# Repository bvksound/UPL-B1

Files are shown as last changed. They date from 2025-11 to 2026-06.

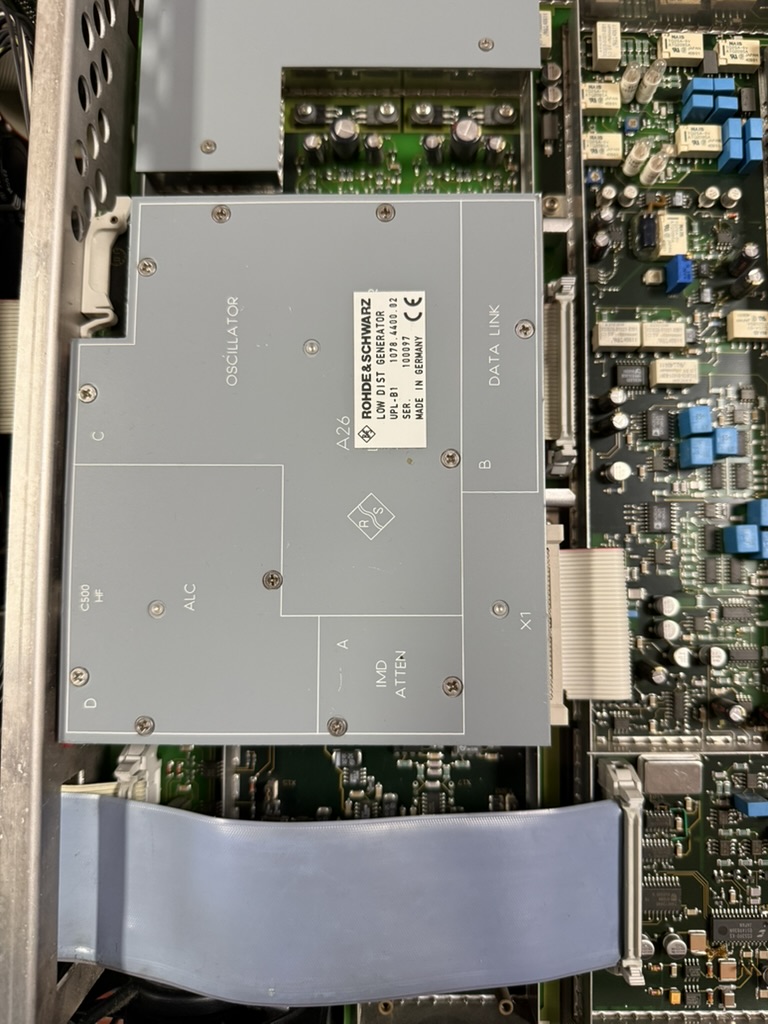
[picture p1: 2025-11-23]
Photo's/27672058-2E6B-4C86-B138-4FB6E2C6E2C1_1_105_c.jpeg

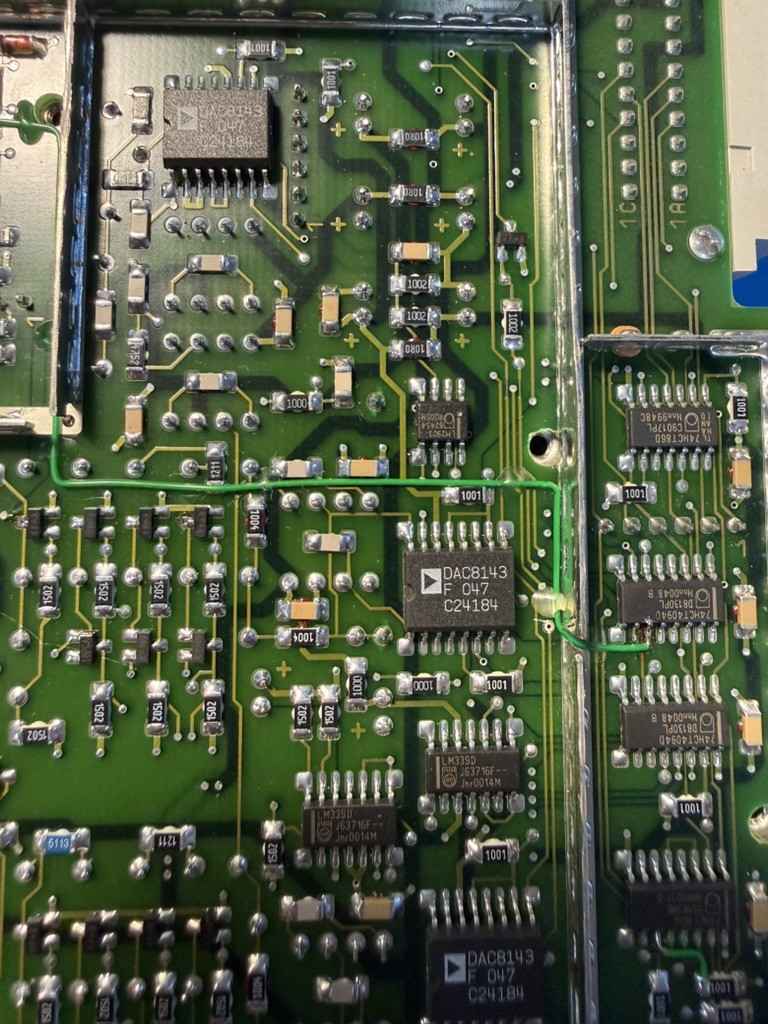
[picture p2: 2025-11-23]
Photo's/FC6CC313-4F3F-445F-819C-2A2638F99B96_1_105_c.jpeg

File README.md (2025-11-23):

UPL-B1 Low Distortion Generator — Functional Description (Sheets 1–5)

The UPL-B1 is a digitally controlled, ultra-low-distortion sine-wave generator. It operates by forming a precisely tuned analog feedback loop based on two integrators, a loop inverter, a fine-tuning DAC, and an ultra-slow automatic level control system. The resulting sine wave is then routed through a calibrated output attenuator to the LOW DIST output connector.

The block diagram in Sheet 1 shows how the system is organized.
What follows is the working description of each functional block in the signal path.

⸻

1. Digital Control Interface (Data Link)

(Located in sheet 1)

At the heart of the module’s control architecture is the Data Link, which acts as the communication interface between the UPL main processor and all analog functions of the generator. A chain of serial-in/parallel-out registers receives configuration words via the UPL’s internal bus. Once a word is clocked in and latched, each bit becomes a control signal for:
	•	selecting RC networks inside the frequency-defining integrators,
	•	programming the 12-bit DAC used for fine frequency tuning,
	•	configuring the ALC’s track-and-hold behavior,
	•	setting the output level via the IMD attenuator.

In this way, the Data Link provides complete, deterministic configuration of the low-distortion generator through a simple serial interface.

⸻

2. First Loop Element: Integrator 2

(Located in sheet 4)

The oscillator loop begins with Integrator 2, which receives the feedback signal from the loop inverter. This block is a precision analog integrator with a set of relay- and switch-selectable RC networks. These RC combinations determine the coarse frequency range of the oscillator.

Because the transfer function of an integrator introduces a –90° phase shift, this element contributes the first quadrature shift in the loop. The output of this block is labelled SIN. It serves as both a phase-shifted signal for the next integrator and as a key reference for amplitude monitoring in the ALC.

⸻

3. Second Loop Element: Integrator 1, and the Loop Inverter

(Both located in sheet 3)

Integrator 1 — second 90° phase shift

The SIN signal from Integrator 2 is fed into Integrator 1, which is structurally similar—another precision op-amp stage with switchable RC networks.
This second integrator produces the COS signal, shifted by another –90°.
Together, the two integrators establish the total –180° shift required by the oscillator’s feedback loop.

Fine Frequency Tuning (DAC + Summing Amplifier)

A portion of the COS signal is routed into a 12-bit DAC system, whose output feeds a summing amplifier. This mechanism provides continuous fine frequency adjustment within each coarse RC range.
The UPL’s firmware writes a digital tuning word via the Data Link, and the DAC modifies the loop dynamics subtly to achieve precise output frequency control.

Loop Inverter — completes the oscillation path

The Loop Inverter receives signals from the fine-tuning circuit and the integrator chain and produces the required additional –180° phase inversion, closing the total loop phase at 360° (0° net).
The loop inverter also establishes the oscillator’s effective feedback gain, which is later stabilized by the amplitude control system.

The output of the loop inverter is fed back to Integrator 2, completing the analog oscillator core.

⸻

4. Amplitude Regulation: The Automatic Level Control (ALC)

(Located in sheet 5)

A precision sine-wave oscillator will naturally drift or saturate unless its amplitude is regulated. In the UPL-B1, this regulation is handled by the Automatic Level Control (ALC) system.

Amplitude Sampling and Track-and-Hold

A portion of the SIN waveform is extracted and fed into a track-and-hold detector.
This allows the ALC to operate cleanly over the full frequency range of the generator—including very low frequencies—where a conventional detector would otherwise create distortion or instability.

Precision Detection and Error Generation

The sampled waveform is rectified and converted into a DC level proportional to its amplitude.
A summing amplifier compares this value to an internally established reference representing the desired output level.

Slow, Low-Distortion Control Loop

The resulting error signal passes through carefully designed low-frequency filters.
These filters ensure that the ALC’s response is extremely slow—far outside the audio band—so that no gain modulation occurs within the audible range. This is critical for achieving the exceptionally low distortion performance of the UPL-B1.

VCA Gain Element

The filtered control voltage drives a voltage-controlled amplifier (VCA) in the main signal path.
When the amplitude is too low, the VCA’s gain increases; when too high, it decreases.
When equilibrium is reached, the loop gain of the oscillator is exactly unity, resulting in a stable, clean sine of precisely controlled amplitude.

The regulated sine now moves to the final output stage.

⸻

5. Output Level Setting: IMD Attenuator

(Located in sheet 2)

The final block is the IMD Attenuator, responsible for delivering calibrated output levels to the LOW DIST connector.
The attenuator uses relay-selected resistor networks combined with precision buffer amplification. Control bits from the Data Link determine the selected attenuation step.

Unlike the ALC-governed gain element, the IMD attenuator applies fixed, accurate attenuation values that do not interact with the oscillator’s internal amplitude regulation. This ensures:
	•	repeatable, calibration-grade output levels,
	•	reliable IMD and THD measurement conditions,
	•	and isolation of the internal oscillator loop from load-dependent variations.

The output of this attenuator is the module’s LOW DIST signal.

⸻

Complete Signal Flow (at a glance)
	1.	UPL processor configures the module via the Data Link (Sheet 1).
	2.	The signal enters Integrator 2 (Sheet 4) which adds the first –90° phase shift.
	3.	It then enters Integrator 1 (Sheet 3) for another –90° shift, producing COS.
	4.	The signal passes through the fine-tuning DAC and the Loop Inverter (Sheet 3), closing the loop.
	5.	The resulting oscillation is amplitude-stabilized by the ALC system (Sheet 5).
	6.	The regulated sine enters the IMD Attenuator (Sheet 2).
	7.	The final output appears as LOW DIST, ready for measurement applications.

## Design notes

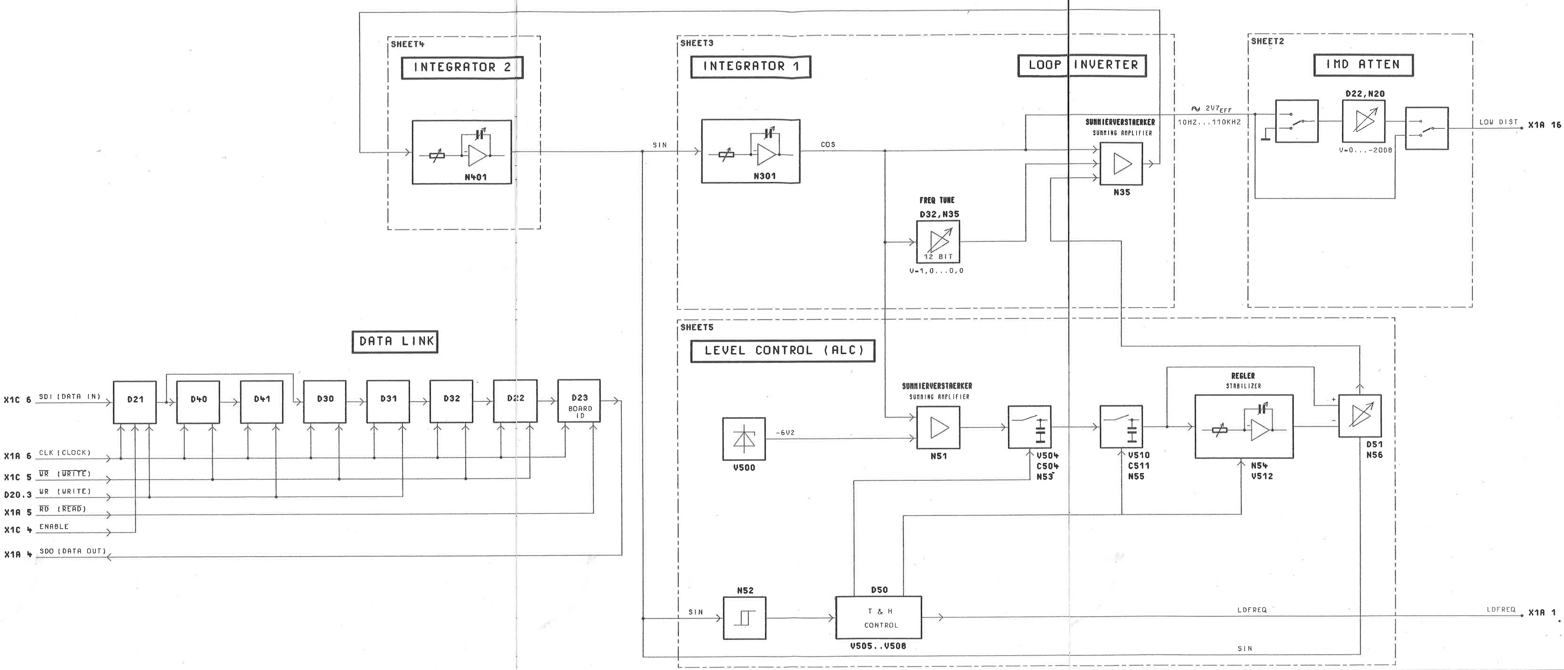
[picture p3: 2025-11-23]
Documentation/Block Schematic Cropped.png

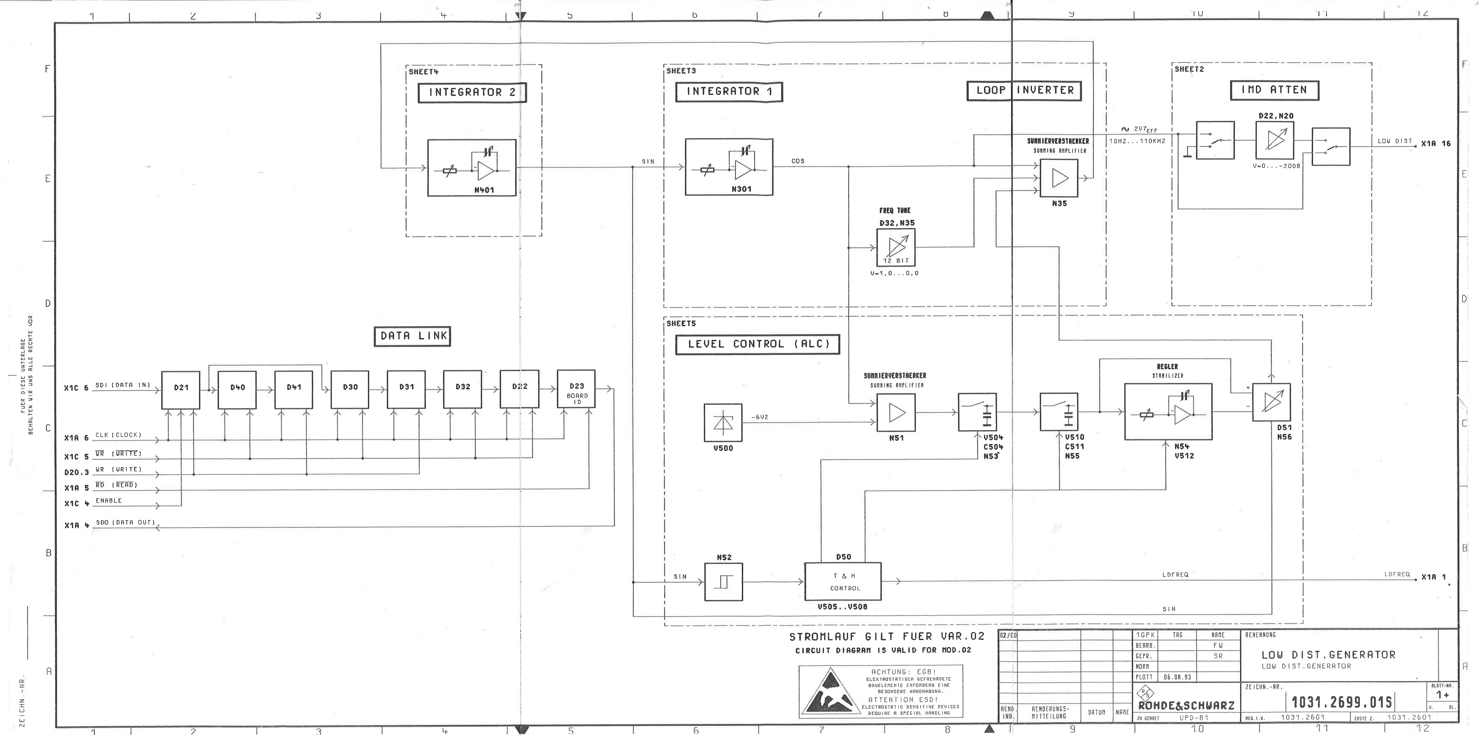
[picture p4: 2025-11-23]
Documentation/Block Schematic.png

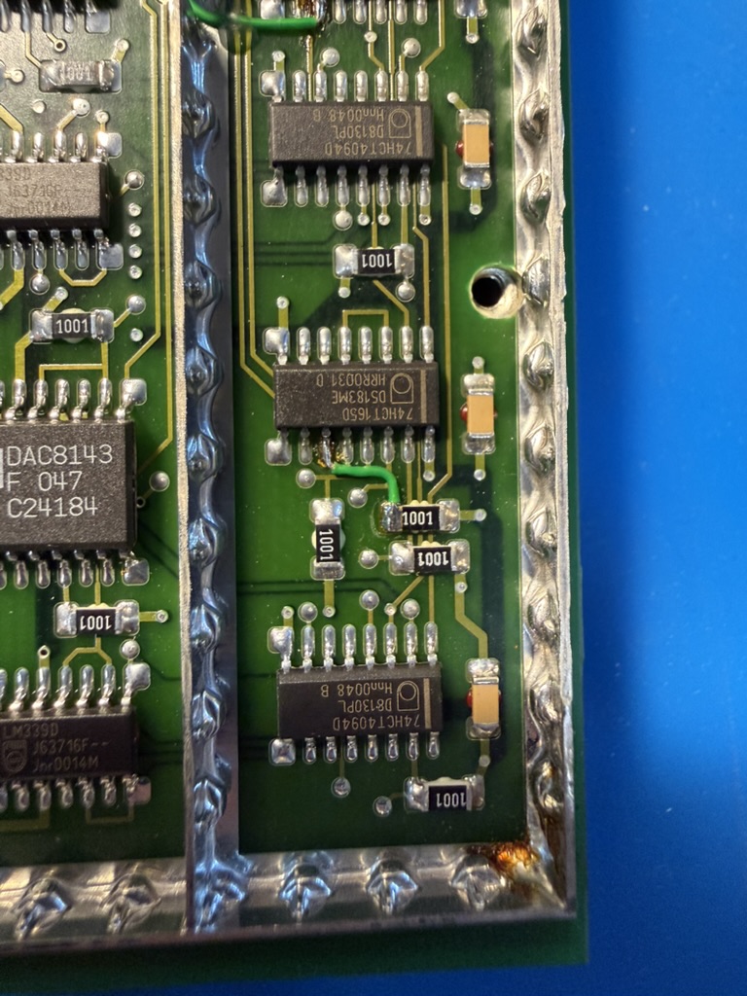
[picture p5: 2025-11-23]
Photo's/623FA692-C8BD-4882-8F0A-5FB2C9D7B14C_1_105_c.jpeg

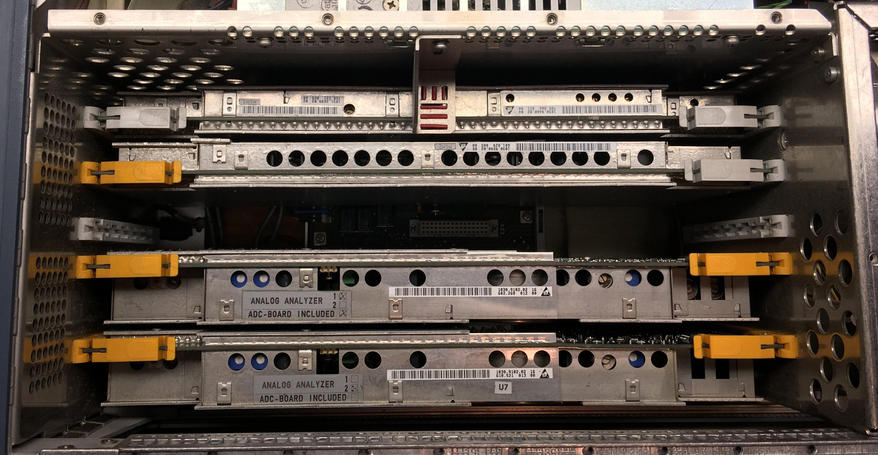
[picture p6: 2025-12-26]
Photo's/UPD_Option UPL-B1 Slot.jpg

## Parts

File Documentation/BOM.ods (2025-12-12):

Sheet: out
 | Value | Footprint | TempCo | Voltage | Manufacturer | Order No | Datasheet | Raw designation from R&S BOM | Still availabe from Distributors | Distributor | Partno | Comment on availability | RoHS | Substitute?
C500 | 1 to 14 pF > 6 turns; |  |  |  |  |  | https://www.ebay.at/itm/284966498300 | CTY 13PF TAUCHTR.RD7X12 CT 0092.4266.00|TEKELEC AT 5401 | TBD
V3 | 16 AK BC850B N 45V 200MA AK 0007.7969.00/PHILIPS-CO BC850B |  |  |  | PHILIPS |  |  | 16 AK BC850B N 45V 200MA AK 0007.7969.00/PHILIPS-CO BC850B | TBD |  |  | Found some on ebay
V510 | 2N4092 | TO-18-3 |  | 40V | INTERSIL | 2N4092 | https://www.mouser.de/datasheet/3/1206/1/jfet-2n4091-2n4092-2n4093-interfet.pdf | AM 2N4092 N-D 40V JFET AM 0010.8791.00/INTERSIL 2N4092 | Yes | Mouser | 494-2N4092 | 35€ p/piece?!
V504 | 2N4856A | TO-18-3 |  |  | Motorola | 2N4856A | https://www.alldatasheet.com/datasheet-pdf/pdf/78471/MOTOROLA/2N4856A.html | AM 2N4856A N-D 40V JFET 0262. 4082.00 |MOTOROLA | Not really |  |  | 60€ p/piece. Min 100
V512 | 2N4856A | TO-18-3 |  |  | Motorola | 2N4856A | https://www.alldatasheet.com/datasheet-pdf/pdf/78471/MOTOROLA/2N4856A.html |  | Not really |  |  | 60€ p/piece. Min 100
V308 | 2N5432 | TO-206AC |  |  | SILICONIX | 2N5432 | https://mm.digikey.com/Volume0/opasdata/d220001/medias/docus/2360/2N5432%20thru%202N5434.pdf | AM 2N5432 N-D 25V JFET AM 0296.8700.00|SILICONIX 2N5432 | No
V309 | 2N5432 | TO-206AC |  |  | SILICONIX | 2N5432 | https://mm.digikey.com/Volume0/opasdata/d220001/medias/docus/2360/2N5432%20thru%202N5434.pdf | AM 2N5432 N-D 25V JFET AM 0296.8700.00/SILICONIX 2N5432 | No
V408 | 2N5432 | TO-206AC |  |  | SILICONIX | 2N5432 | https://mm.digikey.com/Volume0/opasdata/d220001/medias/docus/2360/2N5432%20thru%202N5434.pdf | AM 2N5432 N-D 25V JFET AM 0296.8700.00;SILICONIX 2N5432 | No
V409 | 2N5432 | TO-206AC |  |  | SILICONIX | 2N5432 | https://mm.digikey.com/Volume0/opasdata/d220001/medias/docus/2360/2N5432%20thru%202N5434.pdf | AM 2N5432 N-D 25V JFET AM 0296.8700.00;}SILICONIX 2N5432 | No
V410 | 2N5432 | TO-206AC |  |  | SILICONIX | 2N5432 | https://mm.digikey.com/Volume0/opasdata/d220001/medias/docus/2360/2N5432%20thru%202N5434.pdf | AM 2N5432 N-D 25V JFET AM 0296.8700.00/SILICONIX 2N5432 | No
D50 | 74HC132 | SOIC14 |  |  | PHILIPS | 74HC132D | https://assets.nexperia.com/documents/data-sheet/74HC_HCT132.pdf | BL PC74HC132T 4XSCHMITT T |BL 0520.7811.O00}PHILIPS SE 74HC132D | Yes |  |  |  | Yes
D23 | 74HCT165D | SOIC16 |  |  | PHILIPS | 74HCT165D | https://assets.nexperia.com/documents/data-sheet/74HC_HCT165.pdf | BL PC74HCT165T 8B SHREG BL 0007.5408.O00/PHILIPS SE 74HCT165D | Yes |  |  |  | Yes
D21 | 74HCT4094T | SOIC16 |  |  | PHILIPS | PC74HCT4094T | https://octopart.com/de/datasheet/nxp-semiconductors/PC74HCT4094T | BL PC74HCT4094T 8ST.SHREG |BL O0007.6885.00/PHILIPS-CO PC74HCT4094T | Yes | Mouser | 595-CD74HCT4094EE4 |  | Yes
D31 | 74HCT4094T | SOIC16 |  |  | PHILIPS | PC74HCT4094T | https://octopart.com/de/datasheet/nxp-semiconductors/PC74HCT4094T | BL PC74HCT4094T 8ST.SHREG {BL 0007.6885.00;)PHILIPS-CO PC74HCT4094T | Yes | Mouser | 595-CD74HCT4094EE4 |  | Yes
D41 | 74HCT4094T | SOIC16 |  |  | PHILIPS | PC74HCT4094T | https://octopart.com/de/datasheet/nxp-semiconductors/PC74HCT4094T | BL PC74HCT4094T 8ST.SHREG |BL 0007.6885.00|}PHILIPS-CO PC74HCT4094T | Yes | Mouser | 595-CD74HCT4094EE4 |  | Yes
D20 | 74HCT4094T | SOIC16 |  |  | PHILIPS | PC74HCT86T | https://octopart.com/de/datasheet/nxp-semiconductors/PC74HCT86T | BL PC74HCT86T 4X2IN.EXOR |BL 0007.6291.O00;PHILIPS SE 74HCT86D | Yes | Mouser | 621-74HCT86T14-13 |  | Yes
V20 | BAS32 | SOT23 |  | 75V | PHILIPS | BAS32 | https://assets.nexperia.com/documents/data-sheet/BAS32L.pdf | AD BAS32 75V UDI |AD 0006.7288.00]PHILIPS-CO BAS32 | Yes | Reichelt | BAS32L,115 |  | Yes
V537 | BAS32 | SOT23 |  | 75V | PHILIPS | BAS32 | https://assets.nexperia.com/documents/data-sheet/BAS32L.pdf | AD BAS32 75V UDI |AD 0006.7288.00|PHILIPS-CO BAS32 | Yes | Reichelt | BAS32L,115 |  | Yes
V311 | BAV70 | SOT23 |  |  | PHILIPS | BAV70 | https://assets.nexperia.com/documents/data-sheet/BAV70.pdf | AD BAV70 7OV DUO UDI 0007 .9278.00}PHILIPS-CO BAV70 | Yes | Reichelt | BAV 70 NXP |  | Yes
V313 | BAV70 | SOT23 |  |  | PHILIPS | BAV70 | https://assets.nexperia.com/documents/data-sheet/BAV70.pdf | AD BAV70 7OV DUO UDI 0007 .9278.00/}PHILIPS-CO BAV70 | Yes | Reichelt | BAV 70 NXP |  | Yes
V511 | BAV70 | SOT23 |  |  | PHILIPS | BAV70 | https://assets.nexperia.com/documents/data-sheet/BAV70.pdf | AD BAV70 7OV DUO UDI 0007 .9278.00|PHILIPS-CO BAV70 | Yes | Reichelt | BAV 70 NXP |  | Yes
V514 | BAV99 | SOT23 |  |  | PHILIPS | BAV99 | https://assets.nexperia.com/documents/data-sheet/BAV99.pdf | AD BAV99 70V DUO UDI JAD 0911.0092.00]PHILIPS-CO BAV9S | Yes | Reichelt | BAV99 |  | Yes
V314 | BAV99 | SOT23 |  |  | PHILIPS | BAV99 | https://assets.nexperia.com/documents/data-sheet/BAV99.pdf | AD BAV99 7OV DUO UDI |AD 0911.0092.00|/PHILIPS-CO BAVg9 | Yes | Reichelt | BAV99 |  | Yes
V513 | BAV99 | SOT23 |  |  | PHILIPS | BAV99 | https://assets.nexperia.com/documents/data-sheet/BAV99.pdf | AD BAV99 7OV DUO UDI |AD 0911.0092.00}/PHILIPS-CO BAVS9 | Yes | Reichelt | BAV99 |  | Yes
V515 | BAV99 | SOT23 |  |  | PHILIPS | BAV99 | https://assets.nexperia.com/documents/data-sheet/BAV99.pdf | AD BAV99 7OV DUO UDI jAD 0911.0092.00]PHILIPS-CO BAVS9 | Yes | Reichelt | BAV99 |  | Yes
V21 | BC850B | SOT23 |  | 45V | PHILIPS-CO | BC850B | https://assets.nexperia.com/documents/data-sheet/BC850C.pdf | AK BC850B N 45V 200MA AK 0007.7969.00|PHILIPS-CO BC850B | Yes | Reichelt | BC 850B SMD |  | Yes
V300 | BC850B | SOT23 |  | 45V | PHILIPS-CO | BC850B | https://assets.nexperia.com/documents/data-sheet/BC850C.pdf | AK BC860B P 45V 200MA AK 0007.7975.00 |MOTOROLA BCB6OB LT1 | Yes | Reichelt | BC 850B SMD |  | Yes
V315 | BC850B | SOT23 |  | 45V | PHILIPS-CO | BC850B | https://assets.nexperia.com/documents/data-sheet/BC850C.pdf | AK BC860B P 45V 200MA AK 0007 .7975.00;MOTOROLA BCB860B LT1 | Yes | Reichelt | BC 850B SMD |  | Yes
V400 | BC850B | SOT23 |  | 45V | PHILIPS-CO | BC850B | https://assets.nexperia.com/documents/data-sheet/BC850C.pdf | AK BC860B P 45V 200MA AK 0007 .7975.00}MOTOROLA BC860B LT1 | Yes | Reichelt | BC 850B SMD |  | Yes
V505 | BC850B | SOT23 |  | 45V | PHILIPS-CO | BC850B | https://assets.nexperia.com/documents/data-sheet/BC850C.pdf | AK BC850B N 45V 200MA AK 0007.7969.00/PHILIPS-CO BC850B | Yes | Reichelt | BC 850B SMD |  | Yes
V506 | BC850B | SOT23 |  | 45V | PHILIPS-CO | BC850B | https://assets.nexperia.com/documents/data-sheet/BC850C.pdf | AK BC8S0B N 45V 200MA AK 0007 .7969.00|PHILIPS-CO BC850B | Yes | Reichelt | BC 850B SMD |  | Yes
V507 | BC850B | SOT23 |  | 45V | PHILIPS-CO | BC850B | https://assets.nexperia.com/documents/data-sheet/BC850C.pdf | AK BC860B P 45V 200MA AK 0007.7975.00/MOTOROLA BCB860B LT1 | Yes | Reichelt | BC 850B SMD |  | Yes
V508 | BC850B | SOT23 |  | 45V | PHILIPS-CO | BC850B | https://assets.nexperia.com/documents/data-sheet/BC850C.pdf | AK BC860B P 45V 200MA AK 0007.7975.00|}MOTOROLA BC860B LT1 | Yes | Reichelt | BC 850B SMD |  | Yes
V306 | BSR56 | SOT23 |  |  | PHILIPS | BSR56 | https://www.nxp.com/docs/en/data-sheet/BSR56_57_58.pdf | AM BSR56 N-D 40V JFET |AM 0007.3111.00}PHILIPS-CO BSR56 | No
V307 | BSR56 | SOT23 |  |  | PHILIPS | BSR56 | https://www.nxp.com/docs/en/data-sheet/BSR56_57_58.pdf | AM BSR56 N-D 40V JFET |AM 0007.3111.00}PHILIPS-CO BSR56 | No
V406 | BSR56 | SOT23 |  |  | PHILIPS | BSR56 | https://www.nxp.com/docs/en/data-sheet/BSR56_57_58.pdf | AM BSR56 N-D 40V JFET |AM 0007.3111.00/PHILIPS-CO BSR56 | No
V407 | BSR56 | SOT23 |  |  | PHILIPS | BSR56 | https://www.nxp.com/docs/en/data-sheet/BSR56_57_58.pdf | AM BSR56 N-D 40V JFET |AM 0007.3111.00/PHILIPS-CO BSR56 | No
V502 | BSR56 | SOT23 |  |  | PHILIPS | BSR56 | https://www.nxp.com/docs/en/data-sheet/BSR56_57_58.pdf | AM BSR56 N-D 40V JFET |AM 0007.3111.00]PHILIPS-CO BSR56 | No
V503 | BSR56 | SOT23 |  |  | PHILIPS | BSR56 | https://www.nxp.com/docs/en/data-sheet/BSR56_57_58.pdf | AM BSR56 N-D 40V JFET |}|AM 0007.3111.00|/PHILIPS-CO BSR56 | No
V516 | BZX55/B7V5 | DO-35 |  |  | PHILIPS | BZX55/B7V5 | https://www.vishay.com/docs/85604/bzx55.pdf | AE BZX55/B7V5 o,5W ZDI AE 0349.3041.00|PHILIPS-CO BZX79/B7V5 | Yes | Mouser | 78-BZX55B7V5 |  | Yes
C306 | CC 100nF+/-10% | 1206 | X7R | 50V | VITRAMON | VJ1206 Y104 K XAT | https://www.vishay.com/docs/45198/vjomd.pdf |  | TBD
C307 | CC 100nF+/-10% | 1206 | X7R | 50V | VITRAMON | VJ1206 Y104 K XAT | https://www.vishay.com/docs/45198/vjomd.pdf |  | TBD
C308 | CC 100nF+/-10% | 1206 | X7R | 50V | VITRAMON | VJ1206 Y104 K XAT | https://www.vishay.com/docs/45198/vjomd.pdf |  | TBD
C313 | CC 100nF+/-10% | 1206 | X7R | 50V | VITRAMON | VJ1206 Y104 K XAT | https://www.vishay.com/docs/45199/vjcommercialseries.pdf |  | TBD
C314 | CC 100nF+/-10% | 1206 | X7R | 50V | VITRAMON | VJ1206 Y104 K XAT | https://www.vishay.com/docs/45199/vjcommercialseries.pdf |  | TBD
C316 | CC 100nF+/-10% | 1206 | X7R | 50V | VITRAMON | VJ1206 Y104 K XAT | https://www.vishay.com/docs/45199/vjcommercialseries.pdf |  | TBD
C317 | CC 100nF+/-10% | 1206 | X7R | 50V | VITRAMON | VJ1206 Y104 K XAT | https://www.vishay.com/docs/45199/vjcommercialseries.pdf |  | TBD
C406 | CC 100nF+/-10% | 1206 | X7R | 50V | VITRAMON | VJ1206 Y104 K XAT | https://www.vishay.com/docs/45199/vjcommercialseries.pdf |  | TBD
C506 | CC 100nF+/-10% | 1206 | X7R | 50V | VITRAMON | VJ1206 Y104 K XAT | https://www.vishay.com/docs/45199/vjcommercialseries.pdf |  | TBD
C507 | CC 100nF+/-10% | 1206 | X7R | 50V | VITRAMON | VJ1206 Y104 K XAT | https://www.vishay.com/docs/45199/vjcommercialseries.pdf |  | TBD
C515 | CC 100nF+/-10% | 1206 | X7R | 50V | VITRAMON | VJ1206 Y104 K XAT | https://www.vishay.com/docs/45199/vjcommercialseries.pdf |  | TBD
C516 | CC 100nF+/-10% | 1206 | X7R | 50V | VITRAMON | VJ1206 Y104 K XAT | https://www.vishay.com/docs/45199/vjcommercialseries.pdf |  | TBD
C517 | CC 100nF+/-10% | 1206 | X7R | 50V | VITRAMON | VJ1206 Y104 K XAT | https://www.vishay.com/docs/45199/vjcommercialseries.pdf |  | TBD
C518 | CC 100nF+/-10% | 1206 | X7R | 50V | VITRAMON | VJ1206 Y104 K XAT | https://www.vishay.com/docs/45199/vjcommercialseries.pdf |  | TBD
C501 | CC 15pF+-1% | 1206 | NP0 | 50V | VITRAMON | VJ1206 Y104 K XAT | https://www.vishay.com/docs/45199/vjcommercialseries.pdf | CC 15PF+-1%50V NPO 1206 CC 0099.8750.00|VITRAMON VJ1206 A 150 F FA | TBD
C510 | CC 15pF+-1% | 1206 | NP0 | 50V | VITRAMON | VJ1206 Y104 K XAT | https://www.vishay.com/docs/45199/vjcommercialseries.pdf | CC 15PF+-1%50V NPO 1206 CC 0099.8750.00|VITRAMON VJ1206 A 150 F FA | TBD
C522 | CC 1pF+-0,25pF | 1206 | NP0 | 50V | VITRAMON | VJ1206 Y104 K XAT | https://www.vishay.com/docs/45199/vjcommercialseries.pdf | CC 1PF+-0,25PFS50V NPO1206 |CC 0099.8667.00|VITRAMON VJ1206 A 1RO C AT | TBD
C520 | CC 27pF+-1% | 1206 | NP0 | 50V | VITRAMON | VJ1206 Y104 K XAT | https://www.vishay.com/docs/45199/vjcommercialseries.pdf | CC 27PF+-1%50V NPO 1206 CC 0099.8409.00 | VITRAMON VJ1206A 270F FA | TBD
C509 | CC 3,3nF+-10% | 1206 | X7R | 50V | VITRAMON | VJ1206 Y104 K XAT | https://www.vishay.com/docs/45199/vjcommercialseries.pdf | CC 3,3NF+-10%50V X7R 1206 |CC 0099.8909.00|VITRAMON VJ1206 Y 332 KXAT | TBD
C319 | CC 3,3pF+-0,25pF | 1206 | NP0 | 50V | VITRAMON | VJ 1206 A 3R3 C AT | https://www.vishay.com/docs/45198/vjomd.pdf |  | TBD
C401 | CC 3,9pF+-0, 25pF | 1206 | NP0 | 50V | VITRAMON | VJ1206 Y104 K XAT | https://www.vishay.com/docs/45199/vjcommercialseries.pdf | CC 3,9PF+-0, 25PF50V NPO CC 0007 .8207 .00|VITRAMON VJ1206 A 3RQ9 C AT | TBD
C309 | CC 3,9pF+-0,25pF | 1206 | NP0 | 50V | VITRAMON | VJ1206 A 3R9 C AT | https://www.vishay.com/docs/45198/vjomd.pdf |  | TBD
C310 | CC 3,9pF+-0,25pF | 1206 | NP0 | 50V | VITRAMON | VJ1206 A 3R9 C AT | https://www.vishay.com/docs/45198/vjomd.pdf |  | TBD
C311 | CC 3,9pF+-0,25pF | 1206 | NP0 | 50V | VITRAMON | VJ1206 A 3R9 C AT | https://www.vishay.com/docs/45198/vjomd.pdf |  | TBD
C312 | CC 3,9pF+-0,25pF | 1206 | NP0 | 50V | VITRAMON | VJ1206 A 3R9 C AT | https://www.vishay.com/docs/45198/vjomd.pdf |  | TBD
C215 | CC 3,9pF+-0,25pF | 1206 | NP0 | 50V | VITRAMON | VJ1206 A 3RQ C AT | https://www.vishay.com/docs/45198/vjomd.pdf |  | TBD |  |  |  | Yes
C215 | CC 3,9pF+-0,25pF | 1206 | NP0 | 50V | VITRAMON | VJ1206 A 3RQ C AT | https://www.vishay.com/docs/45198/vjomd.pdf |  | TBD |  |  |  | Yes
C300 | CC 3,9pF+-0,25pF | 1206 | NP0 | 50V | VITRAMON | VJ1206 A 3RQ C AT | https://www.vishay.com/docs/45198/vjomd.pdf |  | TBD |  |  |  | Yes
C301 | CC 3,9pF+-0,25pF | 1206 | NP0 | 50V | VITRAMON | VJ1206 A 3RQ C AT | https://www.vishay.com/docs/45198/vjomd.pdf |  | TBD |  |  |  | Yes
C400 | CC 3,9pF+-0,25pF | 1206 | NP0 | 50V | VITRAMON | VJ1206 Y104 K XAT | https://www.vishay.com/docs/45199/vjcommercialseries.pdf | CC 3,9PF+-0,25PF50V NPO CC 0007 .8207.00|VITRAMON VJ1206 A 3R9 C AT | TBD
C320 | CC 330pF+-1% | 1206 | NP0 | 50V | VITRAMON | VJ 1206 A 331 F AT | https://www.vishay.com/docs/45198/vjomd.pdf |  | TBD
C321 | CC 330pF+-1% | 1206 | NP0 | 50V | VITRAMON | VJ1206 A 331 F AT | https://www.vishay.com/docs/45198/vjomd.pdf |  | TBD
C415 | CC 330pF+-1% | 1206 | NP0 | 50V | VITRAMON | VJ1206 Y104 K XAT | https://www.vishay.com/docs/45199/vjcommercialseries.pdf | CC 330PF+-1%50V NPO 1206 CC 0099 .8873.00|VITRAMON VJ1206 A 331 F AT | TBD
C502 | CC 33pF+-1% | 1206 | NP0 | 50V | VITRAMON | VJ1206 Y104 K XAT | https://www.vishay.com/docs/45199/vjcommercialseries.pdf | CC 33PF+~1%50V NPO 1206 CC 0099.8780.00|VITRAMON VJ1206 A330F AT | TBD
C505 | CC 33pF+-1% | 1206 | NP0 | 50V | VITRAMON | VJ1206 Y104 K XAT | https://www.vishay.com/docs/45199/vjcommercialseries.pdf | CC 33PF+-1%50V NPO 1206 CC 0099 .8780.00|VITRAMON VJ1206 A33OF AT | TBD
C503 | CC 4,7pF+-0,25pF | 1206 | NP0 | 50V | VITRAMON | VJ1206 Y104 K XAT | https://www.vishay.com/docs/45199/vjcommercialseries.pdf | CC 4,7PF+-0, 25PFSOV NPO CC 0007 .8213.00|VITRAMON VJ1206 A 4R7 C AT | TBD
C305 | CC 560pF+-1% | 1206 | NP0 | 50V | VITRAMON | VJ1206 A 561 F AT | https://www.vishay.com/docs/45198/vjomd.pdf |  | TBD |  |  |  | Yes
C405 | CC 560pF+-1% | 1206 | NP0 | 50V | VITRAMON | VJ1206 Y104 K XAT | https://www.vishay.com/docs/45199/vjcommercialseries.pdf | CC 560PF+-1%50V NPO 1206 CC 0007 .3186.00|VITRAMON VJ1206 A 561 F AT | TBD
C521 | CC 8,2pF+-0,25pF | 1206 | NP0 | 50V | VITRAMON | VJ1206 Y104 K XAT | https://www.vishay.com/docs/45199/vjcommercialseries.pdf | CC 8,2PF+-0,25PF50V NPO CC 0007 .8242.00|VITRAMON VJ1206 A 8R2 C AT | TBD
C519 | CE 100uF+-20% | RM2,5 |  | 50V | PANASONIC | ECA 1EFG101I |  | CE 1Q00UF+-20%25V RM2.5 CE 0008.7891.00/PANASONIC ECA~1EFG101I | TBD
C200 | CE 100uF+-20% | RM2.5 |  | 25V | PANASONIC | ECA-1EFGIO1I |  |  | TBD |  |  |  | Yes
C201 | CE 100uF+-20% | RM2.5 |  | 25V | PANASONIC | ECA-1EFGIO1I |  |  | TBD |  |  |  | Yes
C202 | CE 100uF+-20% | RM2.5 |  | 25V | PANASONIC | ECA-1EFGIO1I |  |  | TBD |  |  |  | Yes
C203 | CE 100uF+-20% | RM2.5 |  | 25V | PANASONIC | ECA-1EFGIO1I |  |  | TBD |  |  |  | Yes
C204 | CE 100uF+-20% | RM2.5 |  | 25V | PANASONIC | ECA-1EFGIO1I |  |  | TBD |  |  |  | Yes
C205 | CE 100uF+-20% | RM2.5 |  | 25V | PANASONIC | ECA-1EFGIO1I |  |  | TBD |  |  |  | Yes
C206 | CE 100uF+-20% | RM2.5 |  | 25V | PANASONIC | ECA-1EFGIO1I |  |  | TBD |  |  |  | Yes
C322 | CE 100uF+-20% | RM2.5 |  | 25V | PANASONIC | ECA-1EFGIO1I | https://www.arrow.de/products/eca-1em102b/panasonic |  | TBD
C325 | CE 100uF+-20% | RM2.5 |  | 25V | PANASONIC | ECA-1EFGIO1I | https://www.arrow.de/products/eca-1em102b/panasonic |  | TBD
C508 | CE 10uF+-20% | RM2,5 |  | 50V | PHILIPS | CO 2222 116 11109 |  | CE 10UF+-20%50V RM2,5 {CE 0008.7427.O0}PHILIPS CO 2222 116 11109 | No
C414 | CE 220uF+-20% | RM5 |  | 35V | PANASONIC | ECA-1VFG221BQ |  | CE 220UF+-20%35V RMS |CE 0008.7904.00|PANASONIC ECA-1VFG221BQ | TBD
C315 | CE 47uF+-20% | RM2,5 |  | 50V | PANASONIC | ECA1 HFG 470 I |  | CE 47UF+-20%50V RM2,5 |CE 0008.7479.Q0}PANASONIC ECA1 HFG 470 I | TBD
C504 | CK 1,0nF +-1% |  |  | 100V | WIMA | FKP 2 |  | CK 1,ONF +-1% 100V RMS KP jCK 0007.7598.00|WIMA FKP 2 | TBD
C512 | CK 150nF+-5% |  |  | 63V | WIMA | MKS 2 |  | CK 150NF+-5%63VRD3,5HSMKT |CK 0099.2946.00;WIMA MKS2 | No |  |  | +-1% only on request | Yes
C304 | CK 2,2nF +-1% | RM5 |  | 100V RMS | WIMA | FKP 2 | https://cdn-reichelt.de/documents/datenblatt/B300/WIMA_FKP_2.pdf |  | No |  |  | +-1% on request | Yes
C404 | CK 2,2nF +-1% |  |  | 100V | WIMA | FKP 2 |  | CK 2,2NF +-1% 100V RMS KP |CK 0007.7617.00|WIMA FKP 2 | TBD
C402 | CK 330nF+-1% |  |  | 160V | Roederstein | MKP 1839-433/161 | https://www.vishay.com/docs/26022/mkp1839.pdf | CK 330NF+-1%160V | Yes | Mouser | 75-MKP1839433161 |  | Yes
C302 | CK 330nF+-1% | RD8X19 |  | 160V | Roederstein | MKP 1839-433/161 | https://www.vishay.com/docs/26022/mkp1839.pdf |  | Yes | Mouser | 75-MKP1839433161 |  | Yes
C303 | CK 33nF +-1% | RM5 |  | 63V | WIMA | FKP 2 | https://cdn-reichelt.de/documents/datenblatt/B300/WIMA_FKP_2.pdf |  | No |  |  | +-1% on request | Yes
C403 | CK 33nF +-1% |  |  | 63V | WIMA | FKP 2 |  | CK 33NF +-1% 63V RMS KP |CK 0007.7681.00|WIMA FKP 2 | TBD
D22 | DAC8143 | SOIC16 |  |  | PMI | DAC8143 | https://www.analog.com/media/en/technical-documentation/data-sheets/DAC8143.pdf | BJ DAC8143 1X12B-DAC 1012.9510.00 | PMI DACB143FS | Yes | digikey | DAC8143FSZ | Quite expensive
D30 | DAC8143 | SOIC16 |  |  | PMI | DAC8143 | https://www.analog.com/media/en/technical-documentation/data-sheets/DAC8143.pdf | BJ DACB143 1X 12B-DAC 1012.9510.00 | PMI DAC8143FS | Yes | digikey | DAC8143FSZ | Quite expensive
D32 | DAC8143 | SOIC16 |  |  | PMI | DAC8143 | https://www.analog.com/media/en/technical-documentation/data-sheets/DAC8143.pdf | BJ DAC8143 1X12B-DAC 1012.9510.00 | PMI DAC8143FS | Yes | digikey | DAC8143FSZ | Quite expensive
D40 | DAC8143 | SOIC16 |  |  | PMI | DAC8143 | https://www.analog.com/media/en/technical-documentation/data-sheets/DAC8143.pdf | BJ DAC8143 1X12B-DAC 1012.9510.00/PMI DAC8143FS | Yes | digikey | DAC8143FSZ | Quite expensive
V304 | J105 | TO92 |  |  | SILICONIX | J105 | https://www.alldatasheet.com/datasheet-pdf/pdf/26339/VISHAY/J105.html | AM J105 N~D 25V JFET 1030.9377-.O0|SILICONIX J105 | Only from Broker
V404 | J105 | TO92 |  |  | SILICONIX | J105 | https://www.alldatasheet.com/datasheet-pdf/pdf/26339/VISHAY/J105.html | AM J105 N-D 25V JFET 1030.9377.O00|SILICONIX J105 | Only from Broker
D51 | MC1595L |  |  |  | Motorola | MC1595L | https://octopart.com/de/datasheet/motorola/MC1595L | BO MC1595L MULTIPLIER BO 0451.4365.00|MOTOROLA MC1595L | Only from Broker
R307 | RG 1,0MOhm+-1% | 1206 | TK100 |  | DALE | CRCW1206-10 1M F-T | https://www.vishay.com/docs/20008/dcrcw.pdf | RG 1,OMOHM+-1%TK100 1206 |RG 0815.7532.00|DALE CRCW1206-10 1M F-T | Yes
R407 | RG 1,0MOhm+-1% | 1206 | TK100 |  | DALE | CRCW1206-10 1M F-T | https://www.vishay.com/docs/20008/dcrcw.pdf | RG 1,OMOHM+-1%TK100 1206 |RG 0815.7532.00/DALE CRCW1206-10 1M F-T | Yes
R409 | RG 1,0MOhm+-1% | 1206 | TK100 |  | DALE | CRCW1206-10 1M F-T | https://www.vishay.com/docs/20008/dcrcw.pdf | RG 1,OMOHM+-1%TK100 1206 |RG 0815.7532.00|DALE CRCW1206-10 1M F-T | Yes
R309 | RG 1,0MOhm+-1% | 1206 | TK100 |  | DALE | CRCW1206-10 1M F~T | https://www.vishay.com/docs/20008/dcrcw.pdf | RG 1,OMOHM+-1%TK100 1206 |RG 0815.7532.00|DALE CRCW1206-10 1M F~T | Yes
R305 | RG 1,21kOhm+-1% | 1206 | TK100 |  | DALE | CRCW1206-10 1K21 F-T | https://www.vishay.com/docs/20008/dcrcw.pdf | RG 1,21KOHM+-1%TK100 1206 |RG O006.9968.00/DALE CRCW1206-10 1K21 F-T | No
R405 | RG 1,21kOhm+-1% | 1206 | TK100 |  | DALE | CRCW1206-10 1K21 F-T | https://www.vishay.com/docs/20008/dcrcw.pdf | RG 1,21KOHM+-1%TK100 1206 {RG 0006.9968.00/DALE CRCW1206-10 1K21 F-T | No
R509 | RG 1,5 kOhm+-1% | 1206 | TK100 |  | DALE | CRCW1206-10 1K5 F-T | https://www.vishay.com/docs/20008/dcrcw.pdf | RG 1,5 KOHM+-1%TK100 1206 |RG 0007.5714.00|DALE CRCW1206-10 1K5 F-T | Yes
R526 | RG 1,62kOhm+-1% | 1206 | TK100 |  | DALE | CRCW1206-10 1K62 F-T | https://www.vishay.com/docs/20008/dcrcw.pdf | RG 1,62KOHM+-1%TK100 1206 {RG 0006.9997.00]DALE CRCW1206-10 1K62 F-T | No
R200 | RG 10 kOhm+-1% | 1206 | TK100 | 200V | DALE | CRCW1206-10 10K F-T | https://www.vishay.com/docs/20008/dcrcw.pdf | RG 10 KOHM+-1%TK100 1206 |RG 0007.0793.00| DALE CRCW1206-10 10K F-T | Yes
R201 | RG 10 kOhm+-1% | 1206 | TK100 | 200V | DALE | CRCW1206-10 10K F-T | https://www.vishay.com/docs/20008/dcrcw.pdf | RG 10 KOHM+-1%TK100 1206 |RG 0007.0793.00/0ALE CRCW1206-10 10K F-T | Yes
R202 | RG 10 kOhm+-1% | 1206 | TK100 | 200V | DALE | CRCW1206-10 10K F-T | https://www.vishay.com/docs/20008/dcrcw.pdf | RG 10 KOHM+-1%TK100 1206 |RG 0007.0793.00/DALE CRCW1206-10 10K F-T | Yes
R327 | RG 10 kOhm+-1% | 1206 | TK100 | 200V | DALE | CRCW1206-10 10K F-T | https://www.vishay.com/docs/20008/dcrcw.pdf | RG 10 KOHM+-1%TK100 1206 |RG 0007.0793.00]DALE CRCW1206~10 10K F-T | Yes
R328 | RG 10 kOhm+-1% | 1206 | TK100 | 200V | DALE | CRCW1206-10 10K F-T | https://www.vishay.com/docs/20008/dcrcw.pdf | RG 10 KOHM+-1%TK100 1206 {RG 0007.0793.00|DALE CRCW1206-10 10K F-T | Yes
R329 | RG 10 kOhm+-1% | 1206 | TK100 | 200V | DALE | CRCW1206-10 10K F-T | https://www.vishay.com/docs/20008/dcrcw.pdf | RG 10 KOHM+-1%TK100 1206 {RG 0007 .0793.00;DALE CRCW1206-10 10K F-T | Yes
R427 | RG 10 kOhm+-1% | 1206 | TK100 | 200V | DALE | CRCW1206-10 10K F-T | https://www.vishay.com/docs/20008/dcrcw.pdf | RG 10 KOHM+-1%TK100 1206 {RG 0007.0793.00]DALE CRCW1206-10 10K F-T | Yes
R428 | RG 10 kOhm+-1% | 1206 | TK100 | 200V | DALE | CRCW1206-10 10K F-T | https://www.vishay.com/docs/20008/dcrcw.pdf | RG 10 KOHM+-1%TK100 1206 |RG 0007.0793.00|DALE CRCW1206-10 10K F-T | Yes
R429 | RG 10 kOhm+-1% | 1206 | TK100 | 200V | DALE | CRCW1206-10 10K F-T | https://www.vishay.com/docs/20008/dcrcw.pdf | RG 10 KOHM+-1%TK100 1206 {RG 0007.0793.00)DALE CRCW1206-10 10K F-T | Yes
R511 | RG 10 kOhm+-1% | 1206 | TK100 | 200V | DALE | CRCW1206-10 10K F-T | https://www.vishay.com/docs/20008/dcrcw.pdf | RG 10 KOHM+-1%TK100 1206 |RG 0007.0793.00]DALE CRCW1206-10 10K F-T | Yes
R513 | RG 10 kOhm+-1% | 1206 | TK100 | 200V | DALE | CRCW1206-10 10K F-T | https://www.vishay.com/docs/20008/dcrcw.pdf | RG 10 KOHM+-1%TK100 1206 {RG 0007.0793.00)DALE CRCW1206-10 10K F-T | Yes
R534 | RG 10 kOhm+-1% | 1206 | TK100 | 200V | DALE | CRCW1206-10 10K F-T | https://www.vishay.com/docs/20008/dcrcw.pdf | RG 10 KOHM+-1%TK100 1206 |RG 0007.0793.00)DALE CRCW1206-10 10K F-T | Yes
R535 | RG 10 kOhm+-1% | 1206 | TK100 | 200V | DALE | CRCW1206-10 10K F-T | https://www.vishay.com/docs/20008/dcrcw.pdf | RG 10 KOHM+-1%TK100 1206 |RG 0007.0793.00|DALE CRCW1206-10 10K F-T | Yes
R203 | RG 10,0 Ohm+-1% | 1206 | TK100 |  | DALE | CRCW1206-10 10R F-T | https://www.vishay.com/docs/20008/dcrcw.pdf |  | Yes
R204 | RG 10,0 Ohm+-1% | 1206 | TK100 |  | DALE | CRCW1206-10 10R F-T | https://www.vishay.com/docs/20008/dcrcw.pdf |  | Yes
R205 | RG 10,0 Ohm+-1% | 1206 | TK100 |  | DALE | CRCW1206-10 10R F-T | https://www.vishay.com/docs/20008/dcrcw.pdf |  | Yes
R344 | RG 100 Ohm+-1% | 1206 | TK100 | 200V | DALE | CRCW1206-10 100R F-T | https://www.vishay.com/docs/20008/dcrcw.pdf |  | Yes
R346 | RG 100 Ohm+-1% | 1206 | TK100 | 200V | DALE | CRCW1206-10 100R F-T | https://www.vishay.com/docs/20008/dcrcw.pdf |  | Yes
R347 | RG 100 Ohm+-1% | 1206 | TK100 | 200V | DALE | CRCW1206-10 100R F-T | https://www.vishay.com/docs/20008/dcrcw.pdf |  | Yes
R348 | RG 100 Ohm+-1% | 1206 | TK100 | 200V | DALE | CRCW1206-10 100R F-T | https://www.vishay.com/docs/20008/dcrcw.pdf |  | Yes
R430 | RG 100 Ohm+-1% | 1206 | TK100 | 200V | DALE | CRCW1206-10 100R F-T | https://www.vishay.com/docs/20008/dcrcw.pdf |  | Yes
R510 | RG 100 Ohm+-1% | 1206 | TK100 | 200V | DALE | CRCW1206-10 100R F-T | https://www.vishay.com/docs/20008/dcrcw.pdf |  | Yes
R206 | RG 1000 Ohm+-1% | 1206 | TK100 |  | DALE | CRCW1206-10 1K F-T | https://www.vishay.com/docs/20008/dcrcw.pdf | RG 1000 OHM+-1%TK100 1206 jRG O006.7271.00/DALE CRCW1206-10 1K F-T | Yes
R310 | RG 1000 Ohm+-1% | 1206 | TK100 |  | DALE | CRCW1206-10 1K F-T | https://www.vishay.com/docs/20008/dcrcw.pdf | RG 1000 OHM+-1%TK100 1206 {RG 0006.7271.00|DALE CRCW1206-10 1K F-T | Yes
R311 | RG 1000 Ohm+-1% | 1206 | TK100 |  | DALE | CRCW1206-10 1K F-T | https://www.vishay.com/docs/20008/dcrcw.pdf | RG 1000 OHM+-1%TK100 1206 jRG 0006.7271.00]DALE CRCW1206-10 1K F-T | Yes
R320 | RG 1000 Ohm+-1% | 1206 | TK100 |  | DALE | CRCW1206-10 1K F-T | https://www.vishay.com/docs/20008/dcrcw.pdf | RG 1000 OHM+-1%TK100 1206 |RG 0006.7271.00}DALE CRCW1206-10 1K F-T | Yes
R341 | RG 1000 Ohm+-1% | 1206 | TK100 |  | DALE | CRCW1206-10 1K F-T | https://www.vishay.com/docs/20008/dcrcw.pdf | RG 1000 OHM+-1%TK100 1206 |RG 0006.7271.00|DALE CRCW1206-10 1K F-T | Yes
R342 | RG 1000 Ohm+-1% | 1206 | TK100 |  | DALE | CRCW1206-10 1K F-T | https://www.vishay.com/docs/20008/dcrcw.pdf | RG 1000 OHM+-1%TK100 1206 |RG 0006.7271.00|DALE CRCW1206-10 1K F-T | Yes
R410 | RG 1000 Ohm+-1% | 1206 | TK100 |  | DALE | CRCW1206-10 1K F-T | https://www.vishay.com/docs/20008/dcrcw.pdf | RG 1000 OHM+-1%TK100 1206 |RG O006.7271.00]DALE CRCW1206-10 1K F-T | Yes
R411 | RG 1000 Ohm+-1% | 1206 | TK100 |  | DALE | CRCW1206-10 1K F-T | https://www.vishay.com/docs/20008/dcrcw.pdf | RG 1000 OHM+-1%TK100 1206 |RG 0006.7271.00)DALE CRCW1206-10 1K F-T | Yes
R420 | RG 1000 Ohm+-1% | 1206 | TK100 |  | DALE | CRCW1206-10 1K F-T | https://www.vishay.com/docs/20008/dcrcw.pdf | RG 1000 OHM+-1%TK100 1206 |RG 0006.7271.00/DALE CRCW1206-10 1K F-T | Yes
R527 | RG 1000 Ohm+-1% | 1206 | TK100 |  | DALE | CRCW1206-10 1K F-T | https://www.vishay.com/docs/20008/dcrcw.pdf | RG 1000 OHM+-1%TK100 1206 |RG 0006.7271.00] DALE CRCW1206-10 1K F-T | Yes
R421 | RG 1000kOhm+-1% | 1206 | TK100 |  | DALE | CRCW1206-10 100K F-T | https://www.vishay.com/docs/20008/dcrcw.pdf | RG 1O00KOHM+-1%TK100 1206 |RG 0007.1948.00|DALE CRCW1206-10 100K F-T | Yes
R321 | RG 100kOhm+-1% | 1206 | TK100 |  | DALE | CRCW1206-10 100K F-T | https://www.vishay.com/docs/20008/dcrcw.pdf | RG 1OOKOHM+~1%TK100 1206 |RG 0007. 1948.00)DALE CRCW1206-10 100K F-T | Yes
R335 | RG 100kOhm+-1% | 1206 | TK100 |  | DALE | CRCW1206-10 100K F-T | https://www.vishay.com/docs/20008/dcrcw.pdf | RG 1OOKOHM+-1%TK100 1206 |RG 0007. 1948.00 )|DALE CRCW1206-10 100K F-T | Yes
R336 | RG 100kOhm+-1% | 1206 | TK100 |  | DALE | CRCW1206-10 100K F-T | https://www.vishay.com/docs/20008/dcrcw.pdf | RG 1O0KOHM+-1%TK100 1206 |RG 0007. 1948.00)DALE CRCW1206-10 100K F-T | Yes
R517 | RG 100kOhm+-1% | 1206 | TK100 |  | DALE | CRCW1206-10 100K F-T | https://www.vishay.com/docs/20008/dcrcw.pdf | RG 100KOHM+-1%TK100 1206 {RG 0007. 1948.00])DALE CRCW1206-10 100K F-T | Yes
R343 | RG 121kOhm+-1% | 1206 | TK100 |  | DALE | CRCW1206-10 121K F-T | https://www.vishay.com/docs/20008/dcrcw.pdf | RG 121KOHM+-1%TK100 1206 |RG 0007.1960.00)DALE CRCW1206-10 121K F-T | No
R312 | RG 15,0kOhm+-1% | 1206 | TK100 |  | DALE | CRCW1206-10 15K F-T | https://www.vishay.com/docs/20008/dcrcw.pdf | RG 15,OKOHM+-1%TK100 1206 |RG 0007.5843.00|DALE CRCW1206-10 15K F-T | Yes
R330 | RG 15,0kOhm+-1% | 1206 | TK100 |  | DALE | CRCW1206-10 15K F-T | https://www.vishay.com/docs/20008/dcrcw.pdf | RG 15,OKOHM+-1%TK100 1206 |RG 0007 .5843.00|DALE CRCW1206-10 15K F-T | Yes
R331 | RG 15,0kOhm+-1% | 1206 | TK100 |  | DALE | CRCW1206-10 15K F-T | https://www.vishay.com/docs/20008/dcrcw.pdf | RG 15,QKOHM+-1%TK100 1206 | RG 0007 .5843.00)DALE CRCW1206-10 15K F-T | Yes
R332 | RG 15,0kOhm+-1% | 1206 | TK100 |  | DALE | CRCW1206-10 15K F-T | https://www.vishay.com/docs/20008/dcrcw.pdf | RG 15,QKOHM+-1%TK100 1206 | RG 0007 .5843.00|DALE CRCW1206-10 15K F-T | Yes
R412 | RG 15,0kOhm+-1% | 1206 | TK100 |  | DALE | CRCW1206-10 15K F-T | https://www.vishay.com/docs/20008/dcrcw.pdf | RG 15,OKQHM+-1%TK100 1206 {RG 0007.5843.00|DALE CRCW1206-10 15K F-T | Yes
R506 | RG 15,0kOhm+-1% | 1206 | TK100 |  | DALE | CRCW1206-10 15K F-T | https://www.vishay.com/docs/20008/dcrcw.pdf | RG 15,OKOHM+-1%TK100 1206 |RG 0007.5843.00/] DALE CRCW1206-10 15K F-T | Yes
R507 | RG 15,0kOhm+-1% | 1206 | TK100 |  | DALE | CRCW1206-10 15K F-T | https://www.vishay.com/docs/20008/dcrcw.pdf | RG 15,OKOHM+-1%TK100 1206 |RG 0007.5843.00]DALE CRCW1206-10 15K F-T | Yes
R524 | RG 2,0 kOhm+-1% | 1206 | TK100 |  | DALE | CRCW1206-10 2K F-T | https://www.vishay.com/docs/20008/dcrcw.pdf | RG 2,0 KOHM+-1%TK100 1206 {RG 0007.5737.00/DALE CRCW1206-10 2K F-T | Yes |  |  |  |  | TNPW040241K7BEED
R512 | RG 2,21kOhm+-1% | 1206 | TK100 |  | DALE | CRCW1206-10 2K21 F-T | https://www.vishay.com/docs/20008/dcrcw.pdf | RG 2,21KOHM+-1%TK100 1206 |RG 0007.5743.00/DALE CRCW1206-10 2K21 F-T | No |  |  |  |  | TNPW040241K7BEED
R518 | RG 2,21kOhm+-1% | 1206 | TK100 |  | DALE | CRCW1206-10 2K21 F-T | https://www.vishay.com/docs/20008/dcrcw.pdf | RG 2,21KOHM+-1%TK100 1206 |RG 0007.5743.00/DALE CRCW1206-10 2K21 F-T | No |  |  |  |  | TNPW040241K7BEED
R530 | RG 2,21kOhm+-1% | 1206 | TK100 |  | DALE | CRCW1206-10 2K21 F-T | https://www.vishay.com/docs/20008/dcrcw.pdf | RG 2,21KOHM+-1%TK100 1206 |RG O0007.5743.00] DALE CRCW1206-10 2K21 F-T | No |  |  |  |  | 71-RCA08054K75FKEA
R531 | RG 2,21kOhm+-1% | 1206 | TK100 |  | DALE | CRCW1206-10 2K21 F-T | https://www.vishay.com/docs/20008/dcrcw.pdf | RG 2,21KOHM+-1%TK100 1206 {RG 0007.5743.00]DALE CRCW1206-10 2K21 F-T | No |  |  |  |  | 71-RCA08054K75FKEA
R525 | RG 2,43kOhm+-1% | 1206 | TK100 |  | DALE | CRCW1206-10 2K43 F-T | https://www.vishay.com/docs/20008/dcrcw.pdf | RG 2,43KOHM+-1%TK100 1206 |RG 0007.5750.00|DALE CRCW1206-10 2K43 F-T | No
R539 | RG 2,74kOhm+-1% | 1206 | TK100 |  | DALE | CRCW1206-10 2K74 F-T | https://www.vishay.com/docs/20008/dcrcw.pdf | RG 2,74KOHM+-1%TK100 1206 [RG 0007.5766.00|DALE CRCW1206-10 2K74 F-T | No
R540 | RG 2,74kOhm+-1% | 1206 | TK100 |  | DALE | CRCW1206-10 2K74 F-T | https://www.vishay.com/docs/20008/dcrcw.pdf | RG 2,74KOHM+-1%TK100 1206 {RG 0007.5766.00|DALE CRCW1206-10 2K74 F-T | No
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

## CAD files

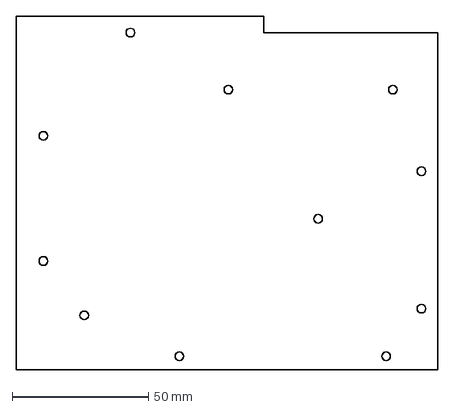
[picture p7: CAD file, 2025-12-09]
Mechanical/PCB/PCB_Main.dxf
155.0 x 130.0 mm

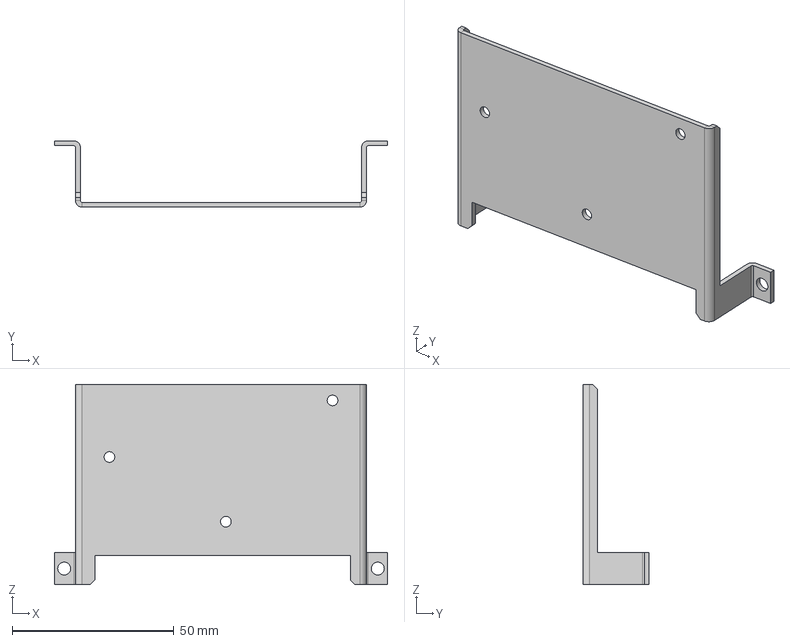
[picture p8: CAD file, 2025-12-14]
Mechanical/Bracket/B1 Bracket.step
103.0 x 20.5 x 62.0 mm

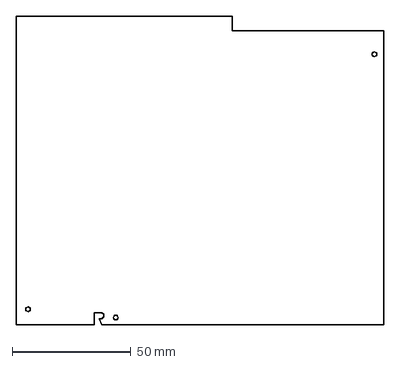
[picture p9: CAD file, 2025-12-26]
Mechanical/Kicad/PCB Outline.dxf
155.0 x 130.0 mm

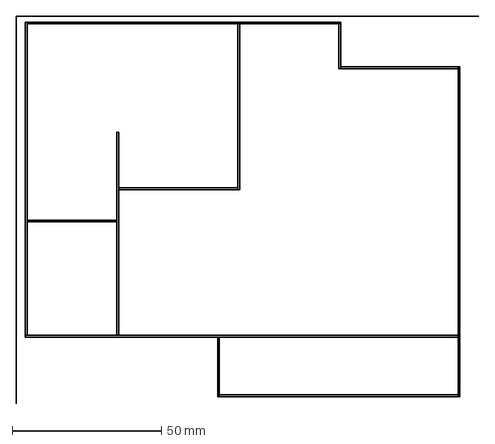
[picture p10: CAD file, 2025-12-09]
Mechanical/PCB/Cut-Outs.dxf
155.0 x 130.0 mm

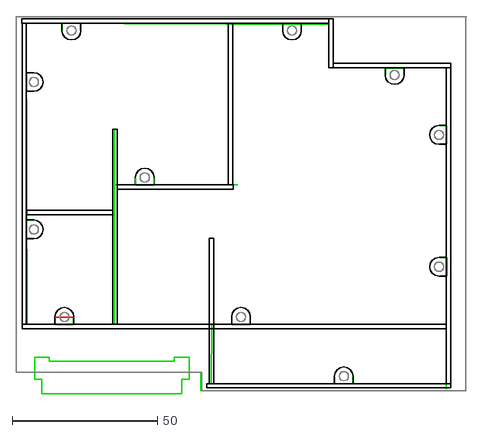
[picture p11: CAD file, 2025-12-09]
Mechanical/PlacementTopside.dxf
155.0 x 129.9

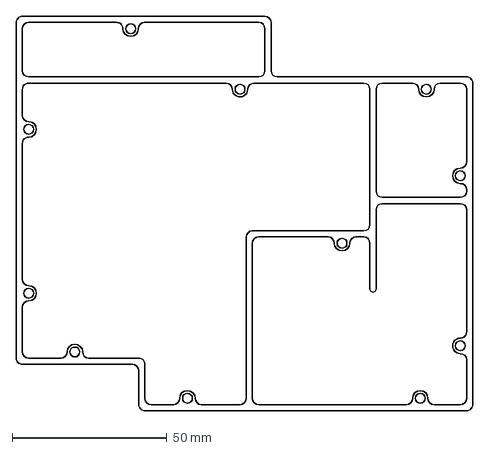
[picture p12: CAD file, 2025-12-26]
Mechanical/Kicad/Shielding Outline Top.dxf
147.7 x 127.6 mm

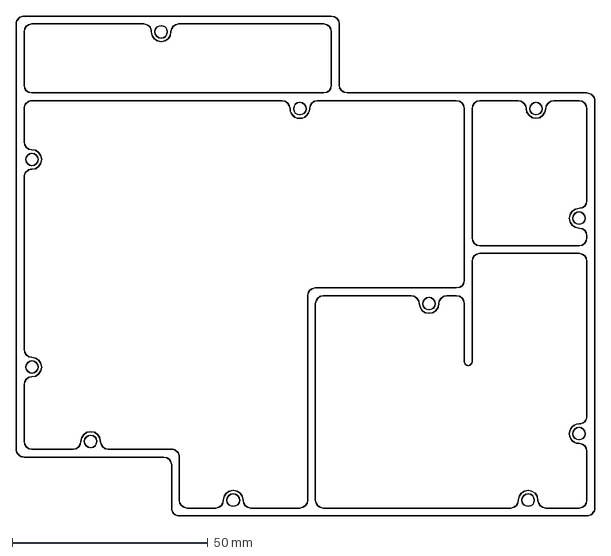
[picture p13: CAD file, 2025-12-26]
Mechanical/Kicad/Holes.dxf
147.7 x 127.6 mm

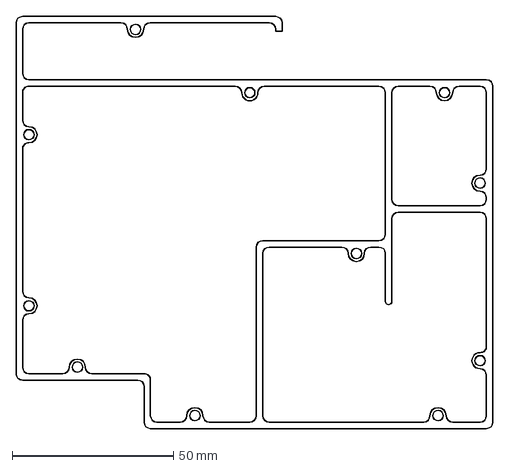
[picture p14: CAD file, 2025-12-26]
Mechanical/Kicad/Shielding Outline Bottom.dxf
147.7 x 127.6 mm

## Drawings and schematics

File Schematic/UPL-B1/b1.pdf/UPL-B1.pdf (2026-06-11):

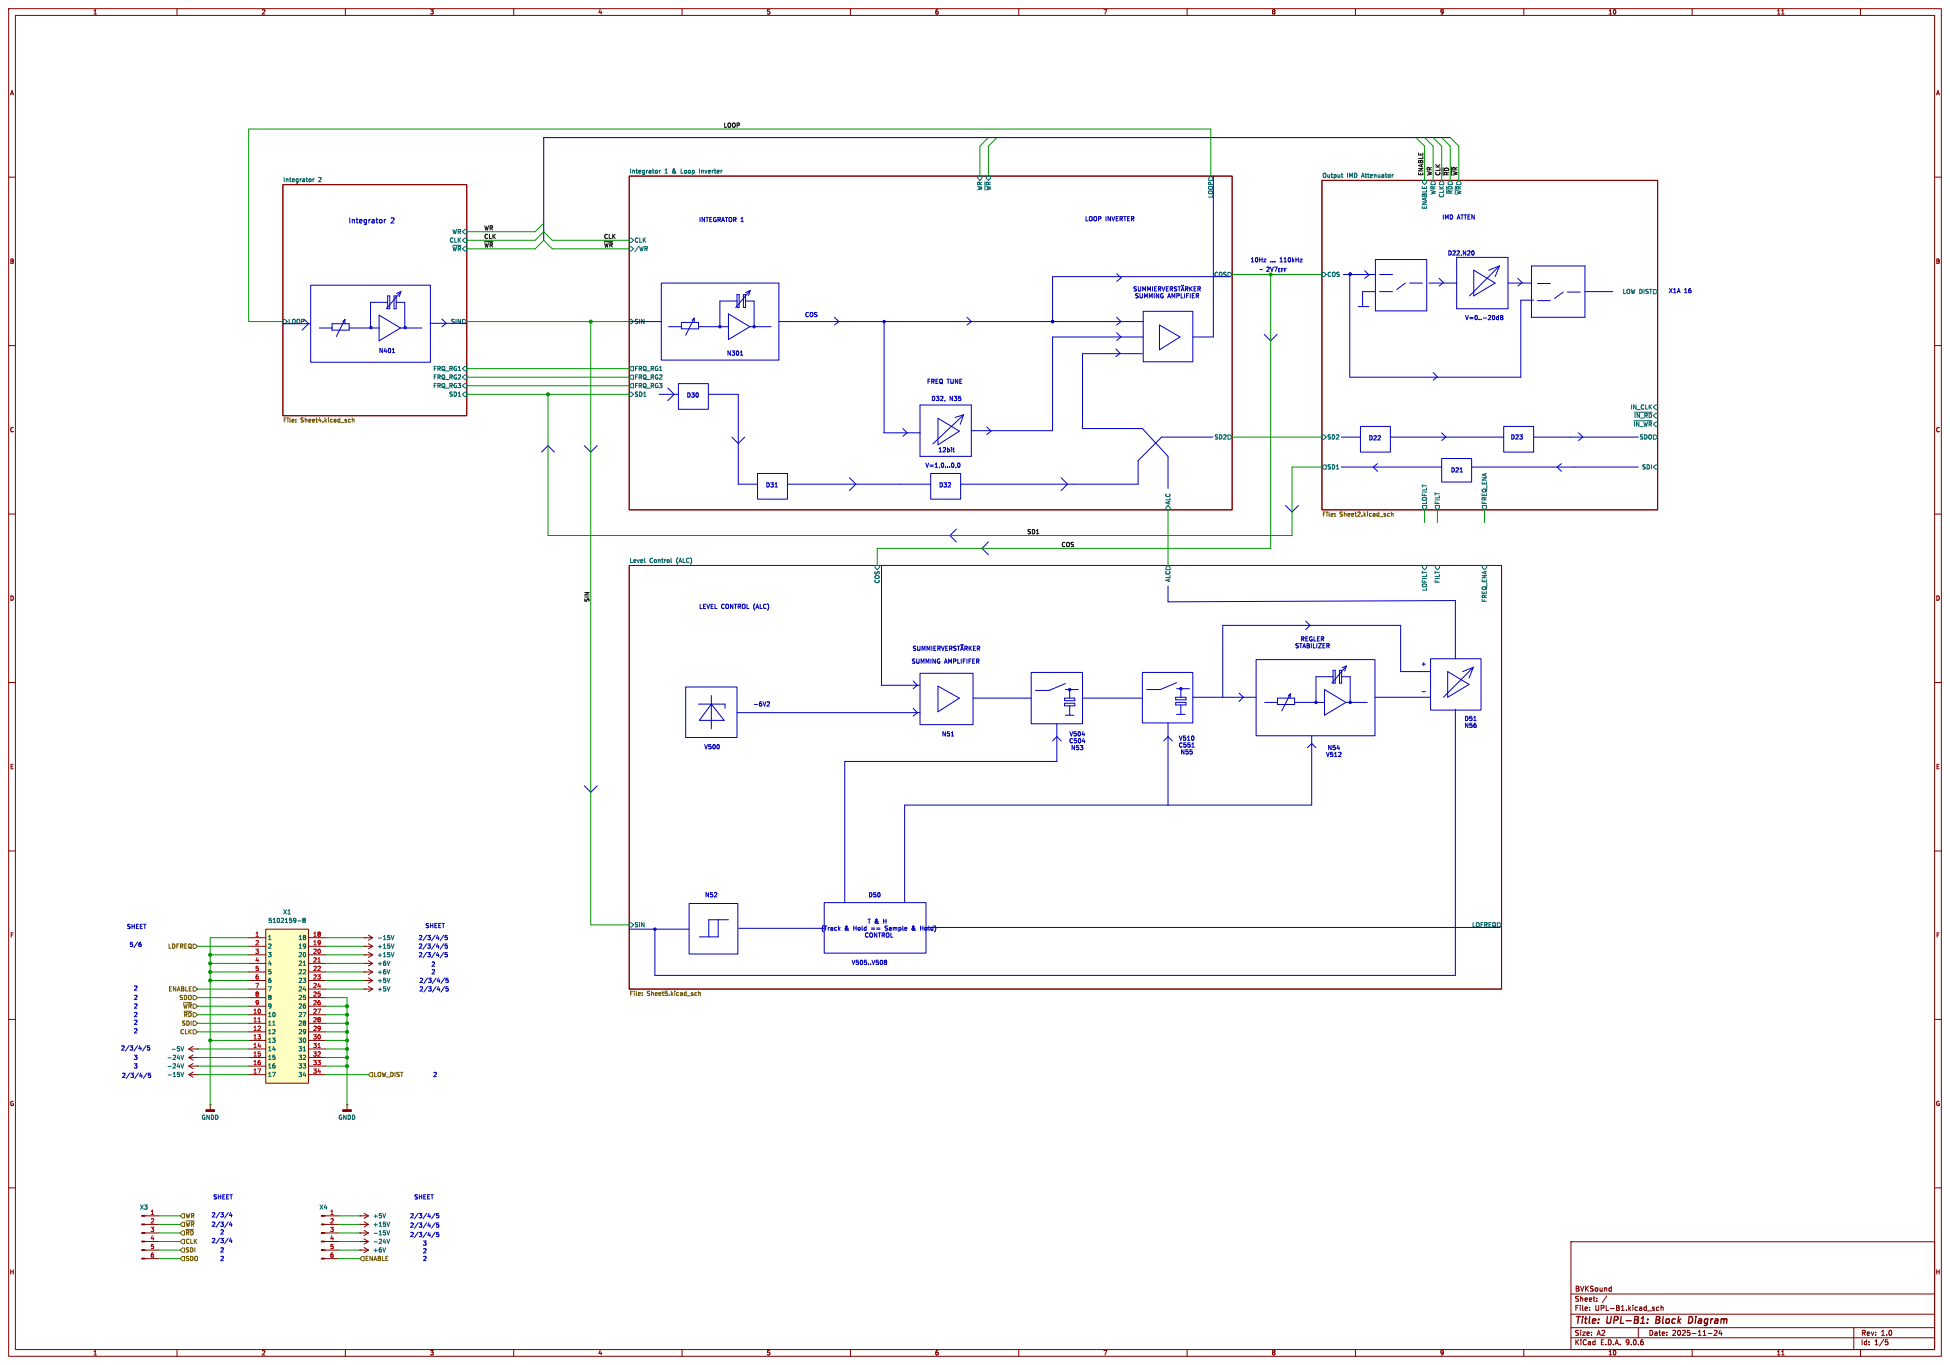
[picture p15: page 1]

Output IMD Attenuator File: Sheet2.kicad_sch

(Track & Hold == Sample & Hold) CONTROL

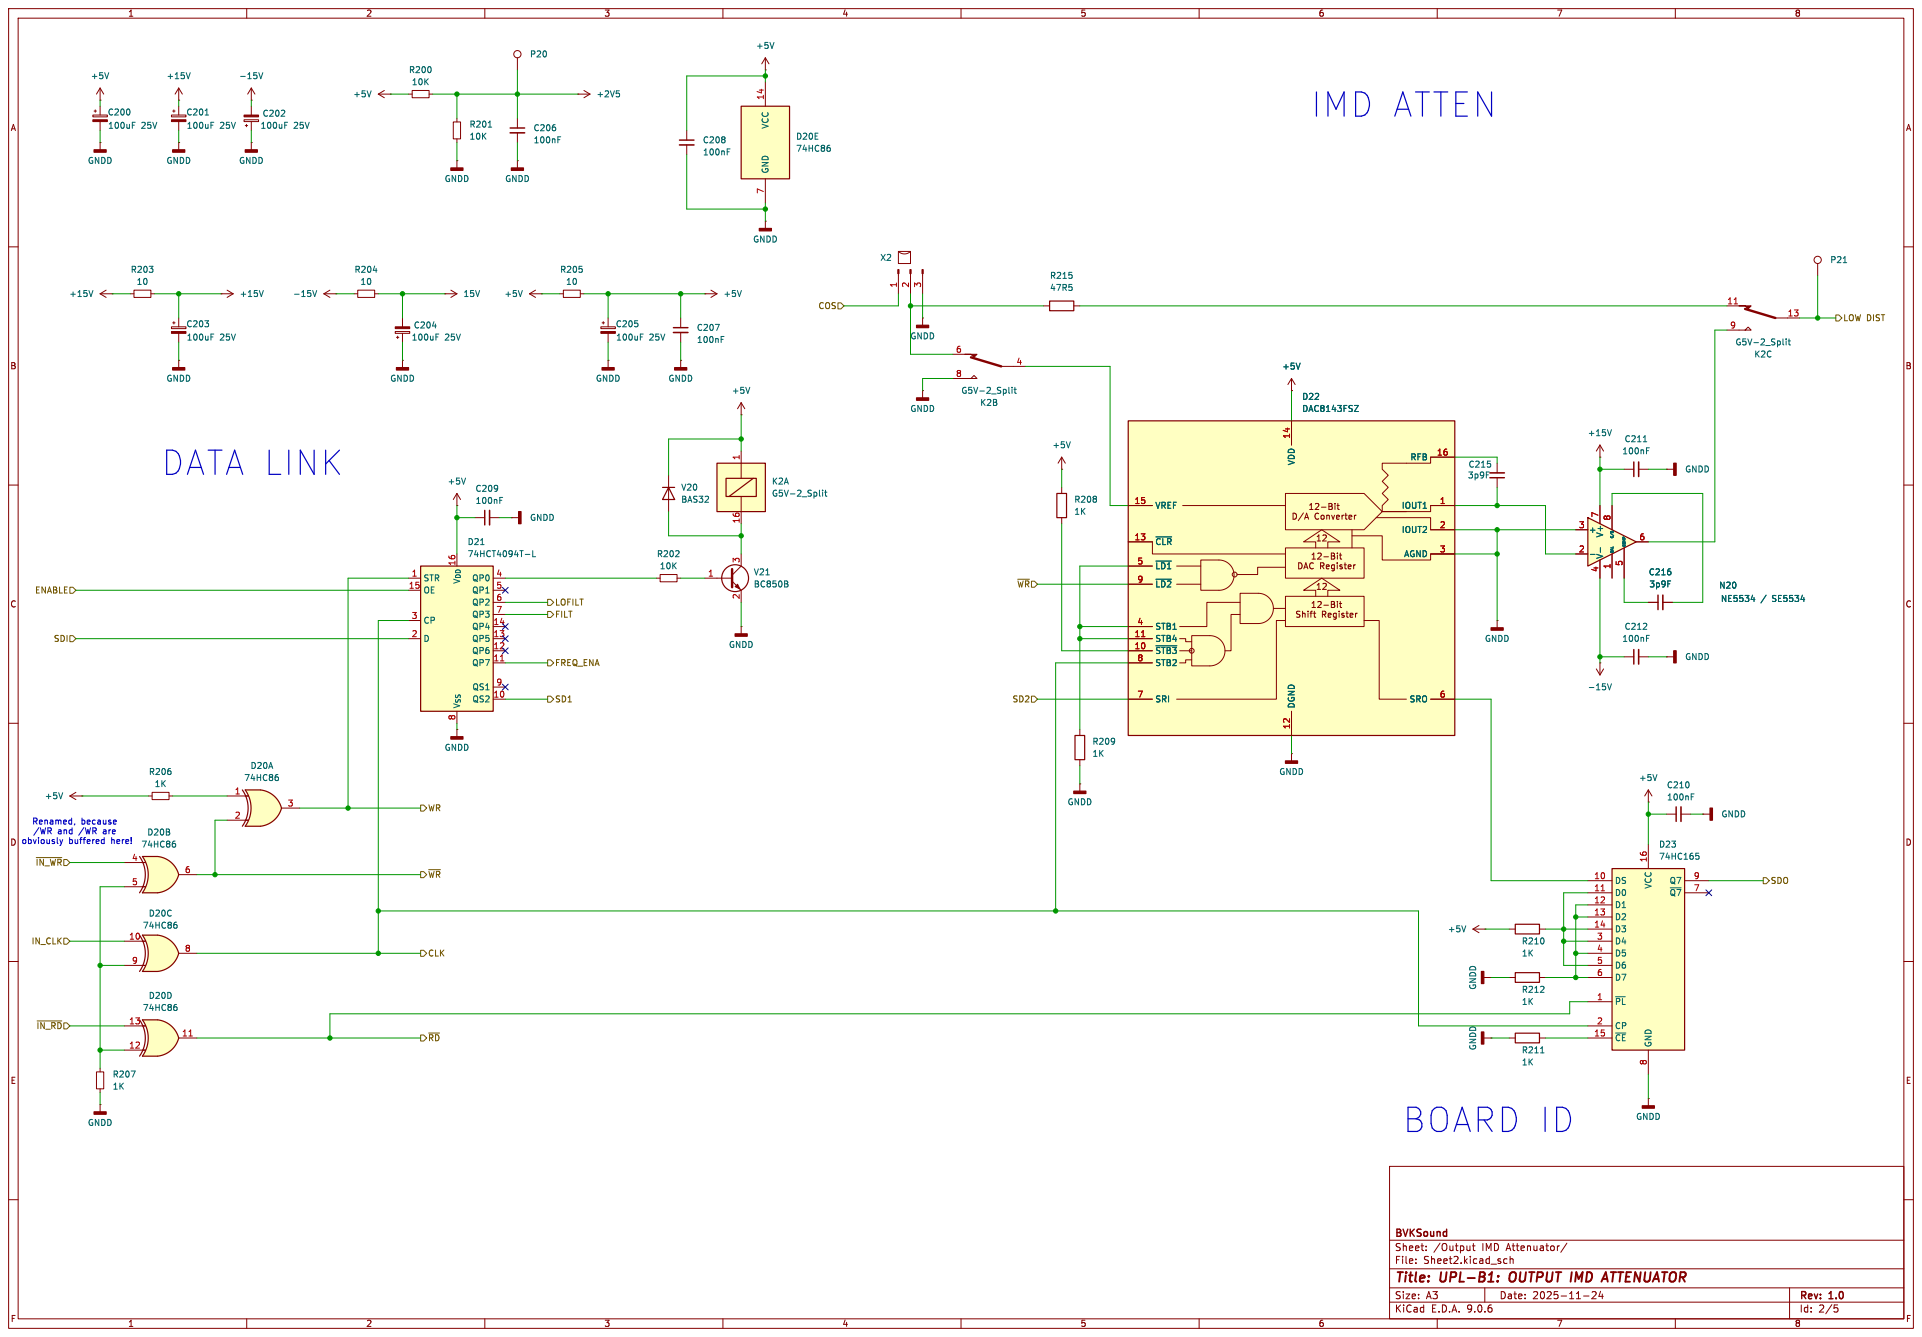
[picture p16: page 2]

Renamed, because
/WR and /WR are

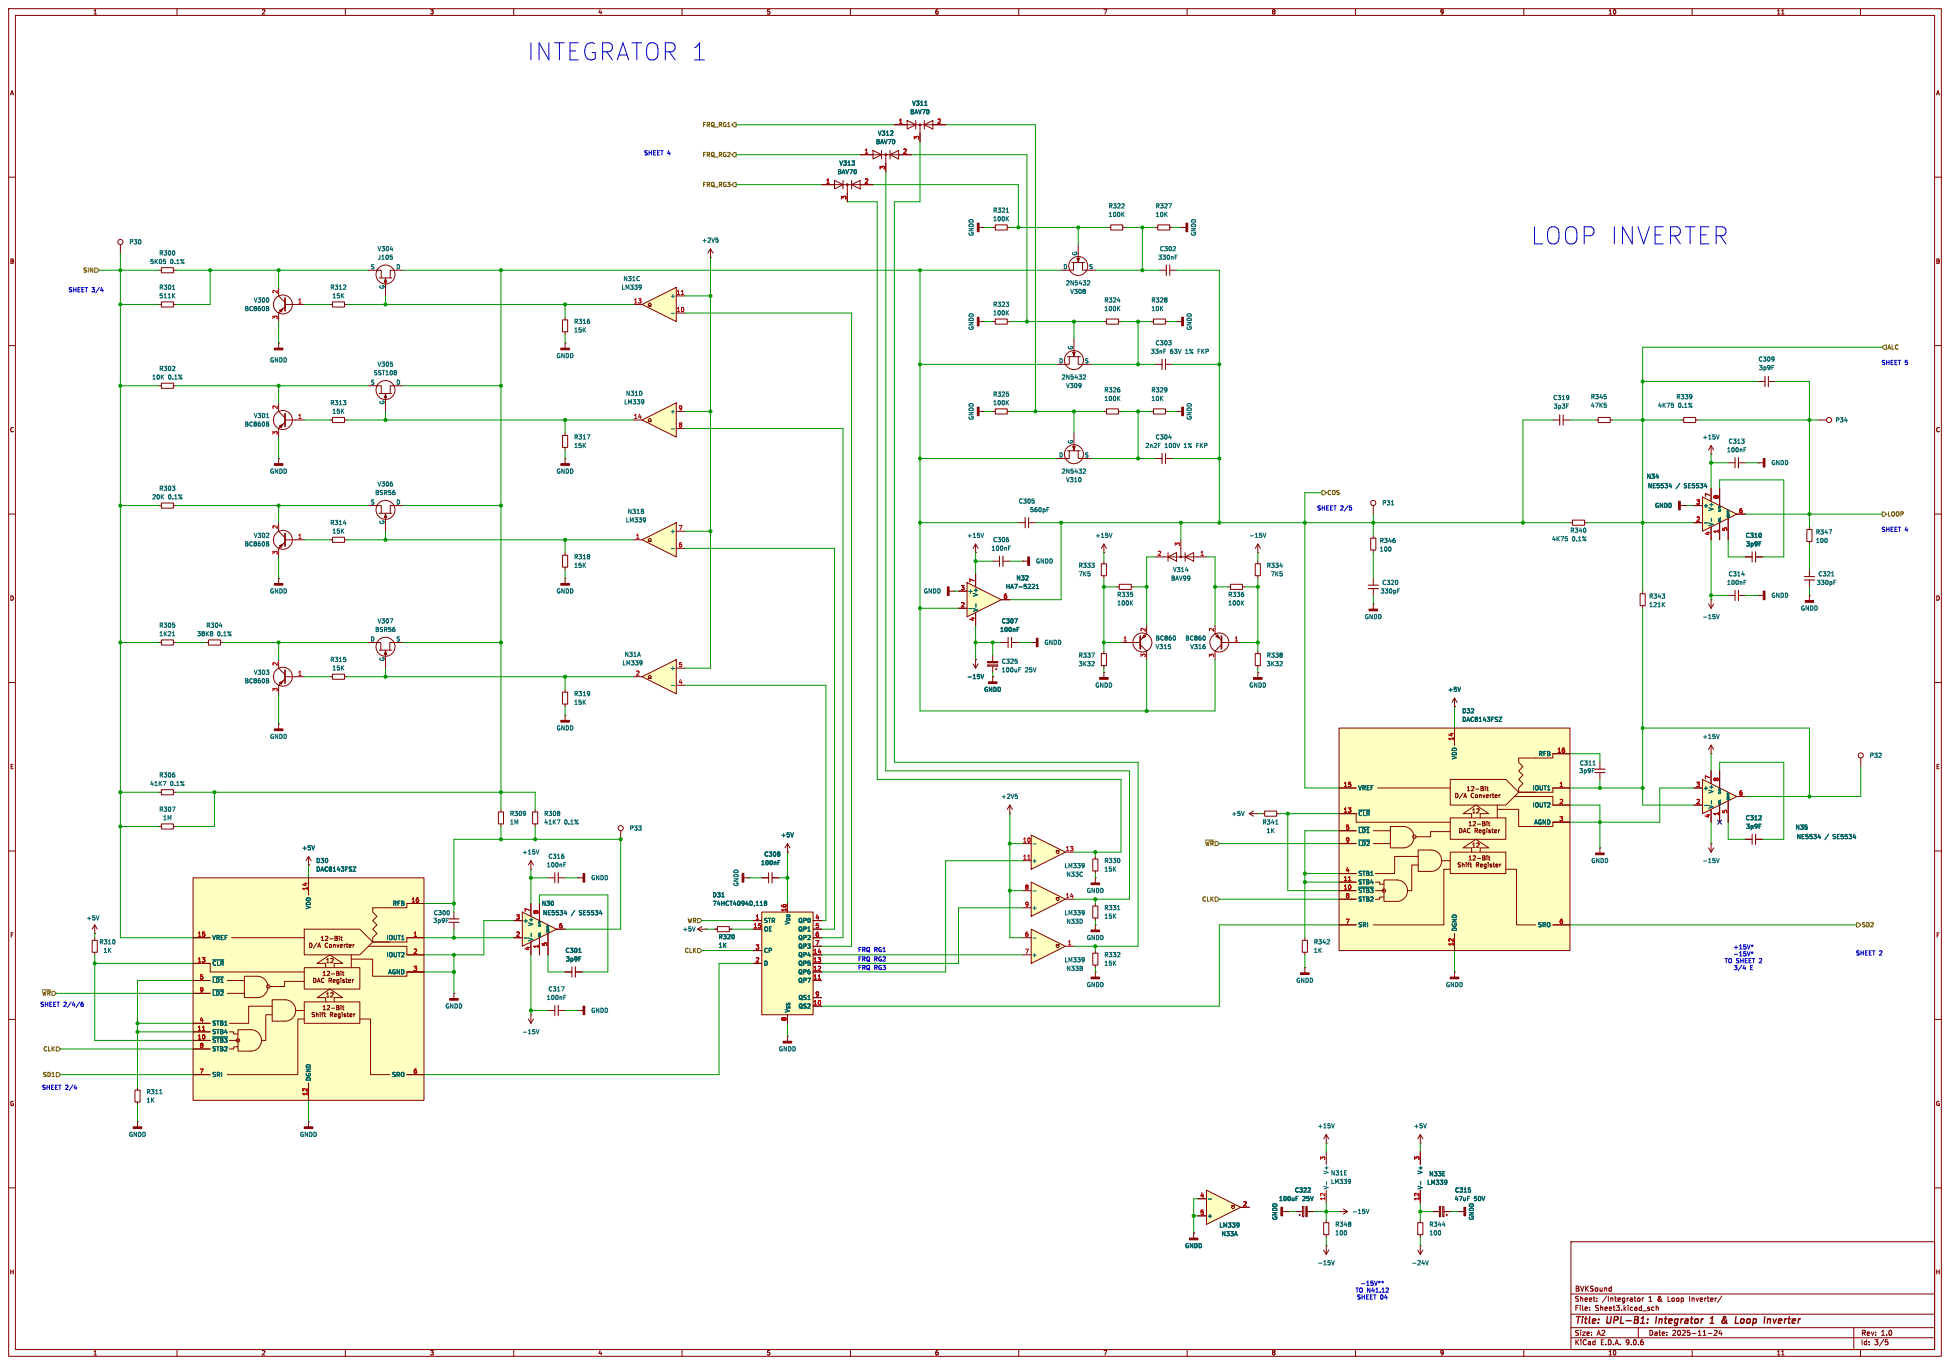
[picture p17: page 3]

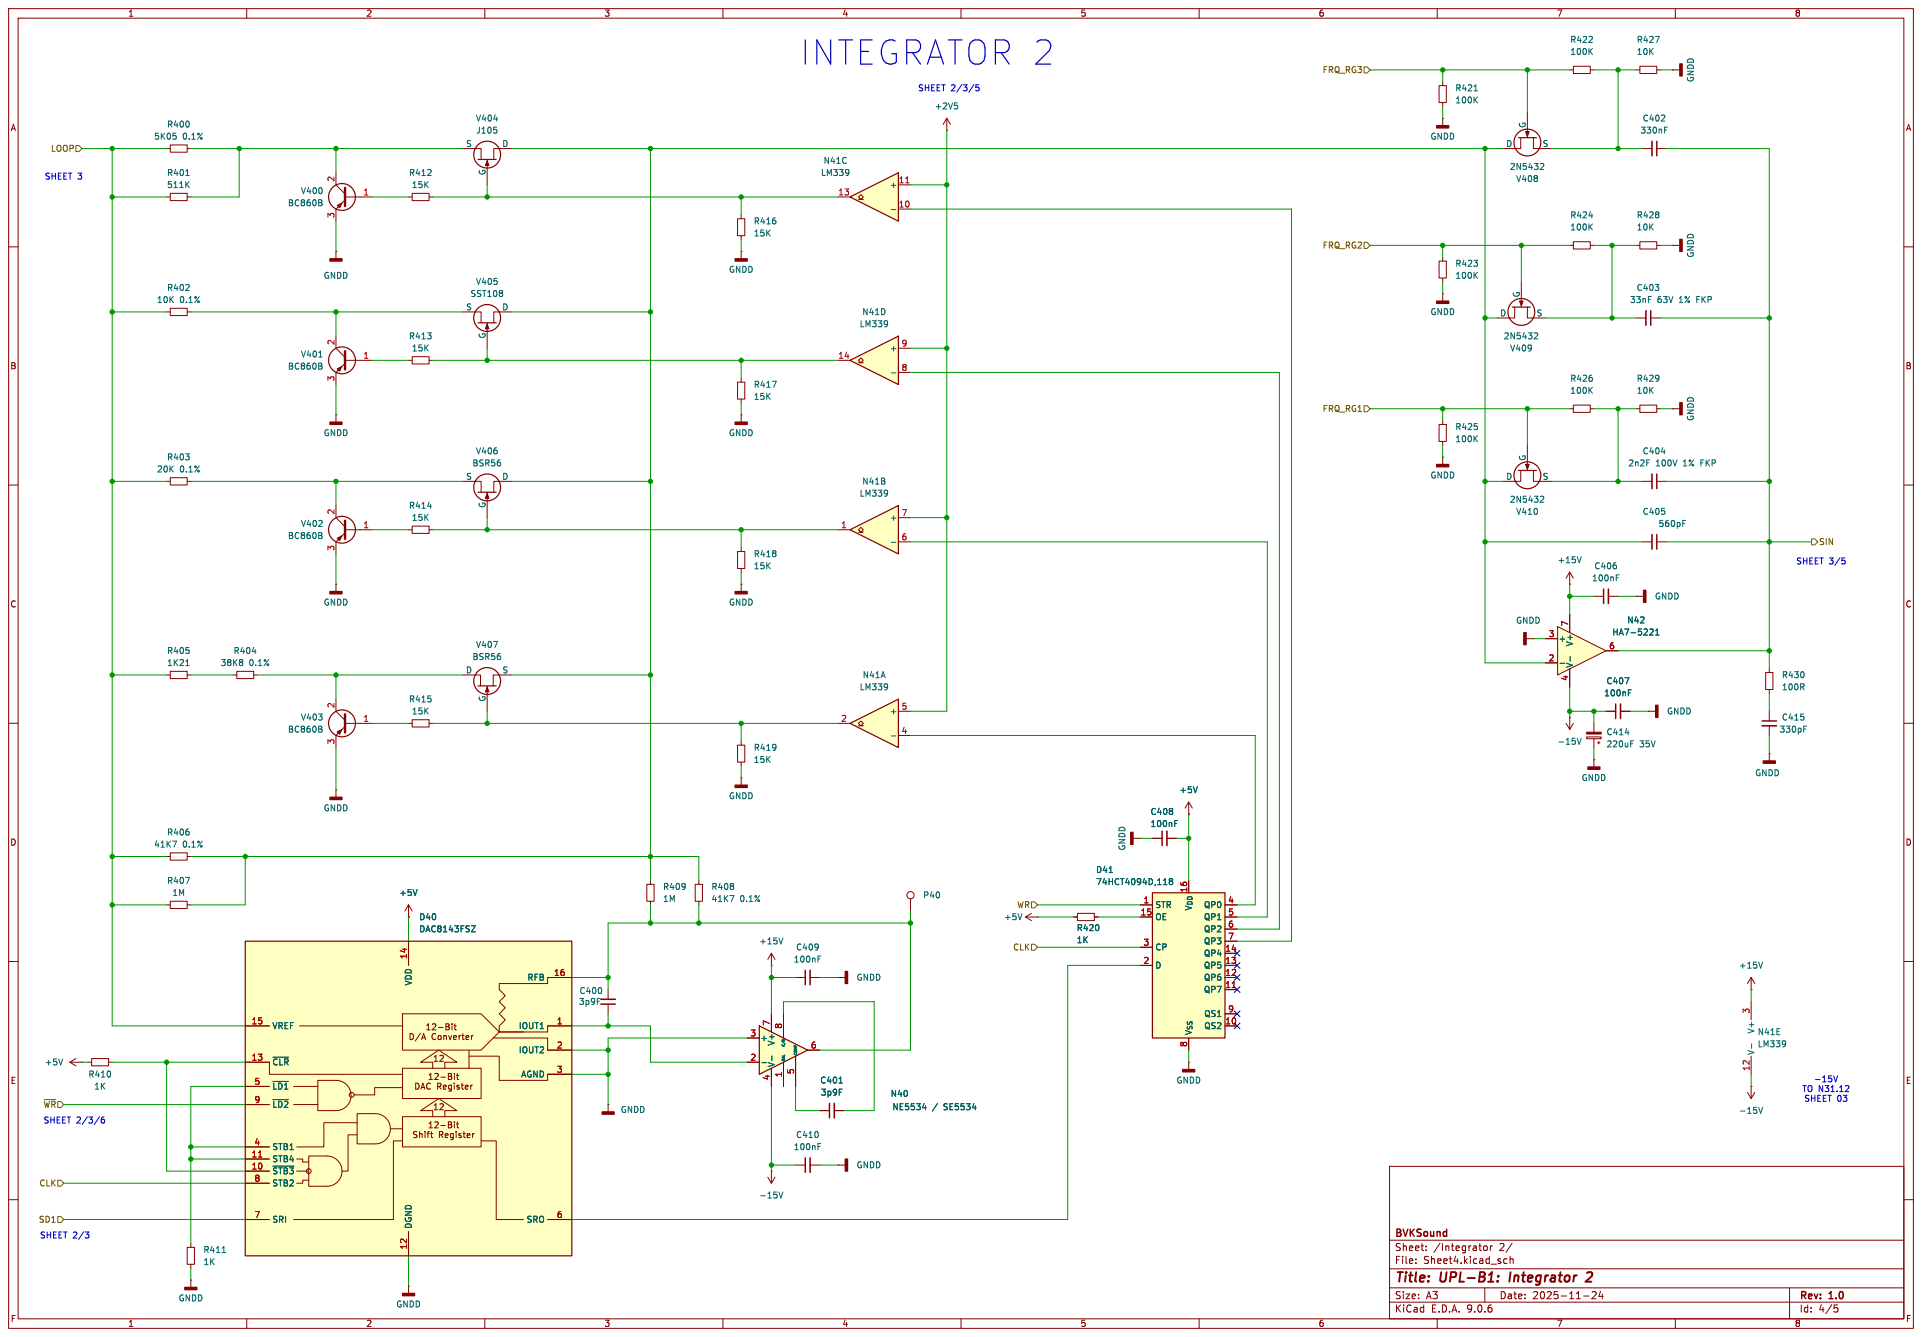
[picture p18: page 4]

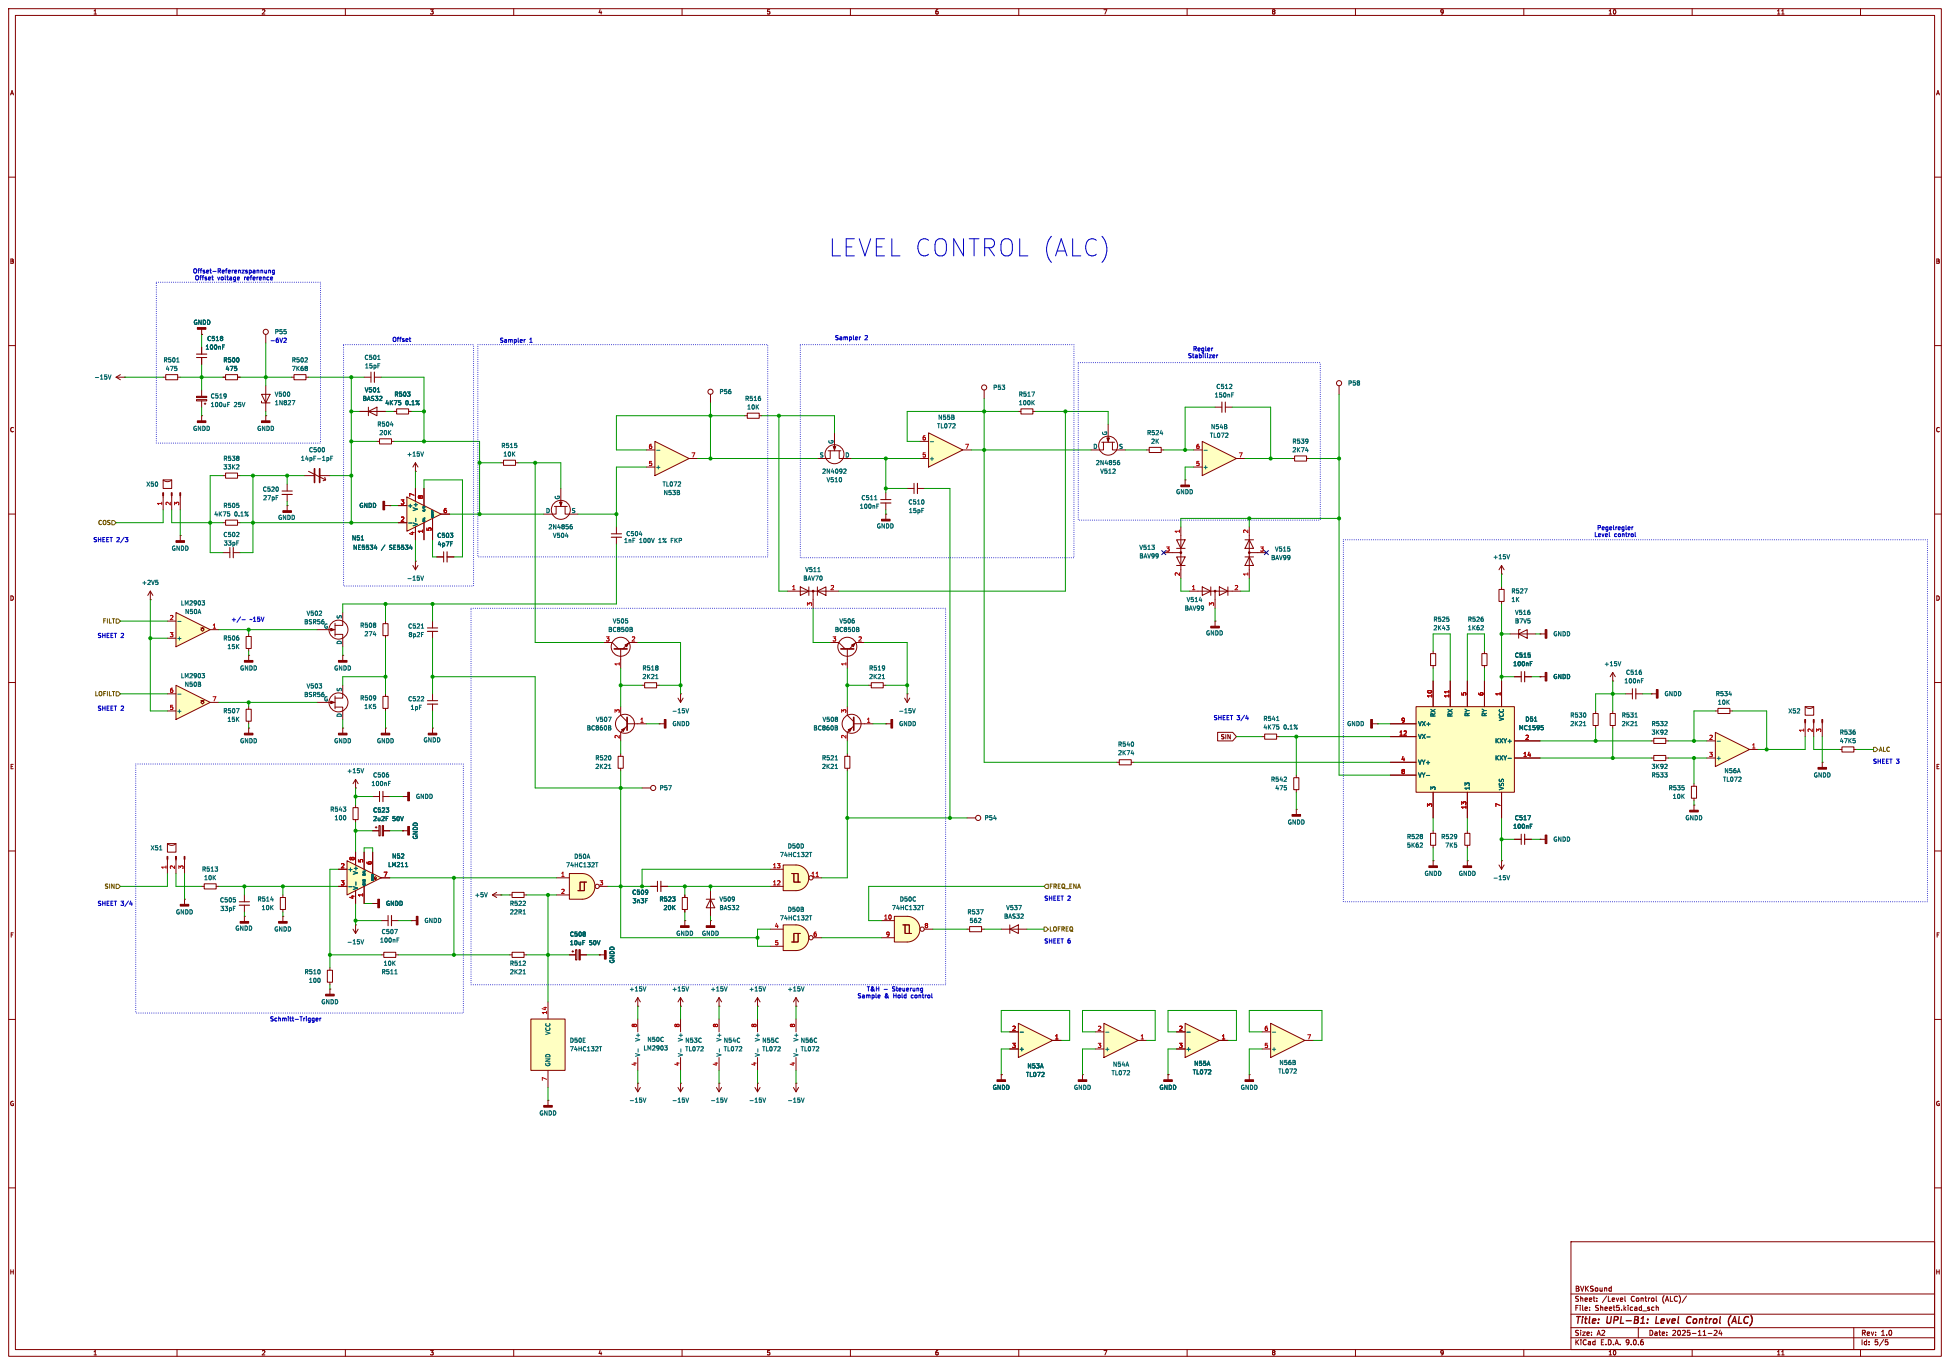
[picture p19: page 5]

Offset-Referenzspannung Offset voltage reference

COS
Pegelregler Level control SHEET 2 SHEET 3/4

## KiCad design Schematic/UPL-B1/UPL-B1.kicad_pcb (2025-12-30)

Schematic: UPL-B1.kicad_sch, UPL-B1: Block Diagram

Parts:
X1: 5102159-8; CONN_5103311-7_TYC; Mouser Part Number 571-5102159-8
X3, X4: Conn_01x06_Pin; PinHeader_1x06_P2.54mm_Vertical

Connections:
+5V: X1.23, X1.24, X4.1; also elsewhere on the board
+6V: X1.21, X1.22, X4.5
+15V: X1.19, X1.20, X4.2; also elsewhere on the board
-5V: X1.14
-15V: X1.17, X1.18, X4.3; also elsewhere on the board
-24V: X1.15, X1.16, X4.4; also elsewhere on the board
/CLK: X3.4; also elsewhere on the board
/ENABLE: X1.7, X4.6; also elsewhere on the board
/IN_CLK: X1.12; also elsewhere on the board
/LDFREQ: X1.2
/LOW_DIST: X1.34; also elsewhere on the board
/SDI: X1.11, X3.5; also elsewhere on the board
/SDO: X1.8, X3.6; also elsewhere on the board
/WR: X3.1; also elsewhere on the board
//IN_RD: X1.10; also elsewhere on the board
//IN_WR: X1.9; also elsewhere on the board
/~RD: X3.3; also elsewhere on the board
/~WR: X3.2; also elsewhere on the board
GNDD: X1.1, X1.3, X1.4, X1.5, X1.6, X1.13, X1.25, X1.26, X1.27, X1.28, X1.29, X1.30, X1.31, X1.32, X1.33; also elsewhere on the board

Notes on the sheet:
2/3/4/5
T & H (Track & Hold == Sample & Hold) CONTROL
SUMMIERVERSTÄRKER
D31
-6V2
FREQ TUNE
IMD ATTEN
INTEGRATOR 1
D22,N20
D22
D32, N35
12bit
REGLER STABILIZER
D51 N56
N52
D32
SHEET
V500
N51
Integrator 2
V505..V508
V504 C504 N53
D50
COS
N401
X1A 16
N54 V512
SUMMIERVERSTÄRKER SUMMING AMPLIFIER
10Hz ... 110kHz
D23
2/3/4
V510 C551 N55
D30
SUMMING AMPLIFIFER
~ 2V7_{EFF}
V=0..-20dB
+ -
N301
D21
LOOP INVERTER

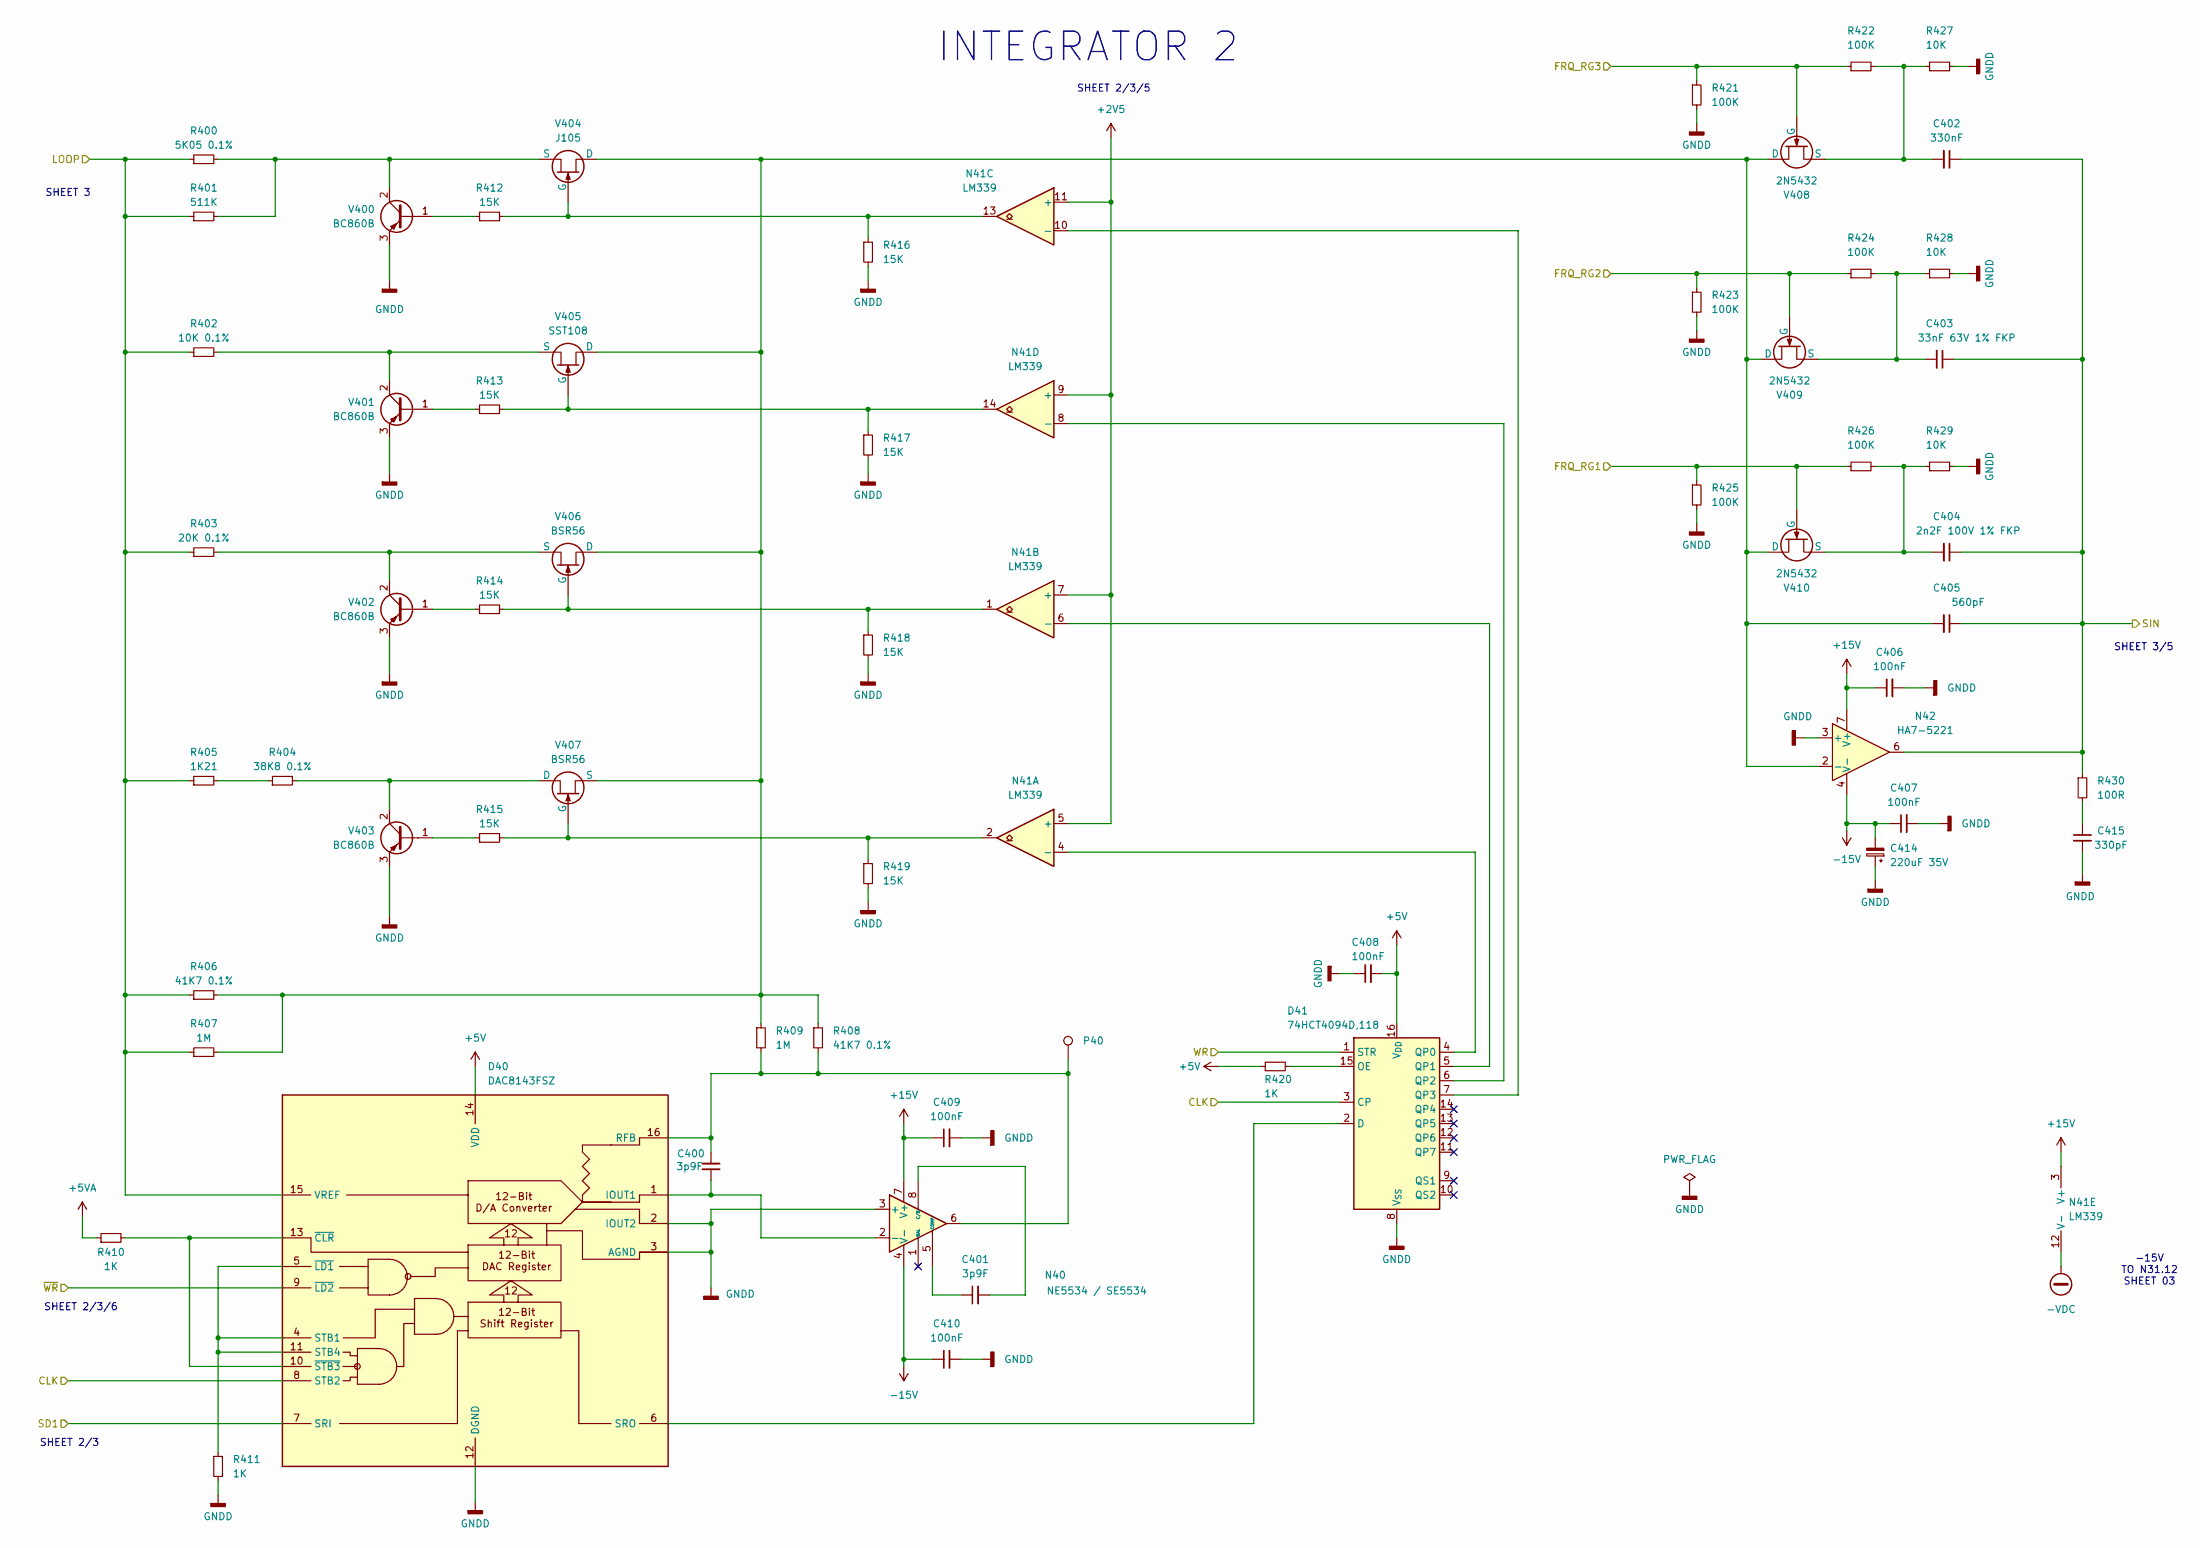
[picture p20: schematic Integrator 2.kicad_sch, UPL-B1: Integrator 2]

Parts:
C400, C401: 3p9F; C_1206_3216Metric_Pad1.33x1.80mm_HandSolder
C402: 330nF; C_Axial_L17.0mm_D7.0mm_P25.00mm_Horizontal
C403: 33nF 63V 1% FKP
C404: 2n2F 100V 1% FKP
C405: 560pF; C_1206_3216Metric_Pad1.33x1.80mm_HandSolder
C406, C407, C408, C409, C410: 100nF; C_1206_3216Metric_Pad1.33x1.80mm_HandSolder
C414: 220uF 35V; C_Radial_D10.0mm_H12.5mm_P5.00mm
C415: 330pF; C_1206_3216Metric_Pad1.33x1.80mm_HandSolder
D40: DAC8143FSZ; SOIC-16W_7.5x10.3mm_P1.27mm; Manufacturer_Part_Number DAC8143FSZ
D41: 74HCT4094D,118; SOIC-16_3.9x9.9mm_P1.27mm; Mouser Part Number 771-74HCT4094D-T
N40: NE5534 / SE5534; SOIC-8_3.9x4.9mm_P1.27mm
N41: LM339; SOIC-14_3.9x8.7mm_P1.27mm
N42: HA7-5221; MSOP-8_3x3mm_P0.65mm
P40: TestPoint; PinHeader_1x01_P1.00mm_Vertical
R400: 5K05 0.1%; R_Axial_DIN0204_L3.6mm_D1.6mm_P7.62mm_Horizontal
R401: 511K; R_1206_3216Metric_Pad1.30x1.75mm_HandSolder
R402: 10K 0.1%; R_Axial_DIN0204_L3.6mm_D1.6mm_P7.62mm_Horizontal
R403: 20K 0.1%; R_Axial_DIN0204_L3.6mm_D1.6mm_P7.62mm_Horizontal
R404: 38K8 0.1%; R_Axial_DIN0204_L3.6mm_D1.6mm_P7.62mm_Horizontal
R405: 1K21; R_1206_3216Metric_Pad1.30x1.75mm_HandSolder
R406, R408: 41K7 0.1%; R_Axial_DIN0204_L3.6mm_D1.6mm_P7.62mm_Horizontal
R407, R409: 1M; R_1206_3216Metric_Pad1.30x1.75mm_HandSolder
R410, R411, R420: 1K; R_1206_3216Metric_Pad1.30x1.75mm_HandSolder
R412, R413, R414, R415, R416, R417, R418, R419: 15K; R_1206_3216Metric_Pad1.30x1.75mm_HandSolder
R421, R422, R423, R424, R425, R426: 100K; R_1206_3216Metric_Pad1.30x1.75mm_HandSolder
R427, R428, R429: 10K; R_1206_3216Metric_Pad1.30x1.75mm_HandSolder
R430: 100R; R_1206_3216Metric_Pad1.30x1.75mm_HandSolder
V400, V401, V402, V403: BC860B; SOT-23
V404: J105; TO-92L_Inline
V405: SST108; SOT-23
V406, V407: BSR56; SOT-23
V408, V409, V410: 2N5432; TO-52-3

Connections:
+2V5: N41.5 (+), N41.7 (+), N41.9 (+), N41.11 (+); also elsewhere on the board
+5V: C408.2, D40.14 (VDD), D41.16 (V_{DD}), R420.1; also elsewhere on the board
+5VA: R410.1; also elsewhere on the board
+15V: C406.1, C409.1, N40.7 (V+), N41.3 (V+), N42.7 (V+); also elsewhere on the board
-15V: C407.1, C410.1, C414.2, N40.4 (V-), N42.4 (V-); also elsewhere on the board
-VDC: N41.12 (V-); also elsewhere on the board
/CLK: D40.8 (STB2), D41.3 (CP); also elsewhere on the board
/Integrator 1 & Loop Inverter/FRQ_RG1: R425.1, R426.1, V410.2 (G); also elsewhere on the board
/Integrator 1 & Loop Inverter/FRQ_RG2: R423.1, R424.1, V409.2 (G); also elsewhere on the board
/Integrator 1 & Loop Inverter/FRQ_RG3: R421.1, R422.1, V408.2 (G); also elsewhere on the board
/LOOP: D40.15 (VREF), R400.1, R401.1, R402.1, R403.1, R405.1, R406.1, R407.1; also elsewhere on the board
/SD1: D40.7 (SRI); also elsewhere on the board
/WR: D41.1 (STR); also elsewhere on the board
/~WR: D40.9 (~LD2); also elsewhere on the board
GNDD: C406.2, C407.2, C408.1, C409.2, C410.2, C414.1, C415.2, D40.2 (IOUT2), D40.3 (AGND), D40.12 (DGND), D41.8 (V_{SS}), N40.3 (+), N42.3 (+), R411.2, R416.2, R417.2, R418.2, R419.2, R421.2, R423.2, R425.2, R427.2, R428.2, R429.2, V400.3 (E), V401.3 (E), V402.3 (E), V403.3 (E); also elsewhere on the board
unnamed: C415.1, R430.2
unnamed: C400.1, D40.1 (IOUT1), N40.2 (-)
unnamed: C400.2, D40.16 (RFB), N40.6, P40.1, R408.2, R409.2
unnamed: D40.6 (SRO), D41.2 (D)
unnamed: D40.4 (STB1), D40.5 (~LD1), D40.11 (STB4), R411.1
unnamed: D40.10 (~STB3), D40.13 (~CLR), R410.2
unnamed: D41.15 (OE), R420.2
unnamed: D41.4 (QP0), N41.4 (-)
unnamed: D41.5 (QP1), N41.6 (-)
unnamed: D41.6 (QP2), N41.8 (-)
unnamed: D41.7 (QP3), N41.10 (-)
unnamed: C401.1, N40.5 (COMP)
unnamed: C401.2, N40.8 (C/B)
unnamed: C405.2, N42.2 (-), R406.2, R407.2, R408.1, R409.1, V404.1 (D), V405.1 (D), V406.1 (D), V407.3 (S), V408.1 (D), V409.1 (D), V410.1 (D)
unnamed: R404.1, R405.2
unnamed: R412.1, V400.1 (B)
unnamed: R400.2, R401.2, V400.2 (C), V404.3 (S)
unnamed: R413.1, V401.1 (B)
unnamed: R402.2, V401.2 (C), V405.3 (S)
unnamed: R414.1, V402.1 (B)
unnamed: R403.2, V402.2 (C), V406.3 (S)
unnamed: R415.1, V403.1 (B)
unnamed: R404.2, V403.2 (C), V407.1 (D)
unnamed: N41.13, R412.2, R416.1, V404.2 (G)
unnamed: N41.14, R413.2, R417.1, V405.2 (G)
unnamed: N41.1, R414.2, R418.1, V406.2 (G)
unnamed: N41.2, R415.2, R419.1, V407.2 (G)
unnamed: C402.2, R422.2, R427.1, V408.3 (S)
unnamed: C403.2, R424.2, R428.1, V409.3 (S)
unnamed: C404.2, R426.2, R429.1, V410.3 (S)
SIN: C402.1, C403.1, C404.1, C405.1, N42.6, R430.1; also elsewhere on the board

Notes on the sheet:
-15V TO N31.12 SHEET 03
INTEGRATOR 2
SHEET 2/3/5
SHEET 2/3/6
SHEET 3/5
SHEET 2/3
SHEET 3

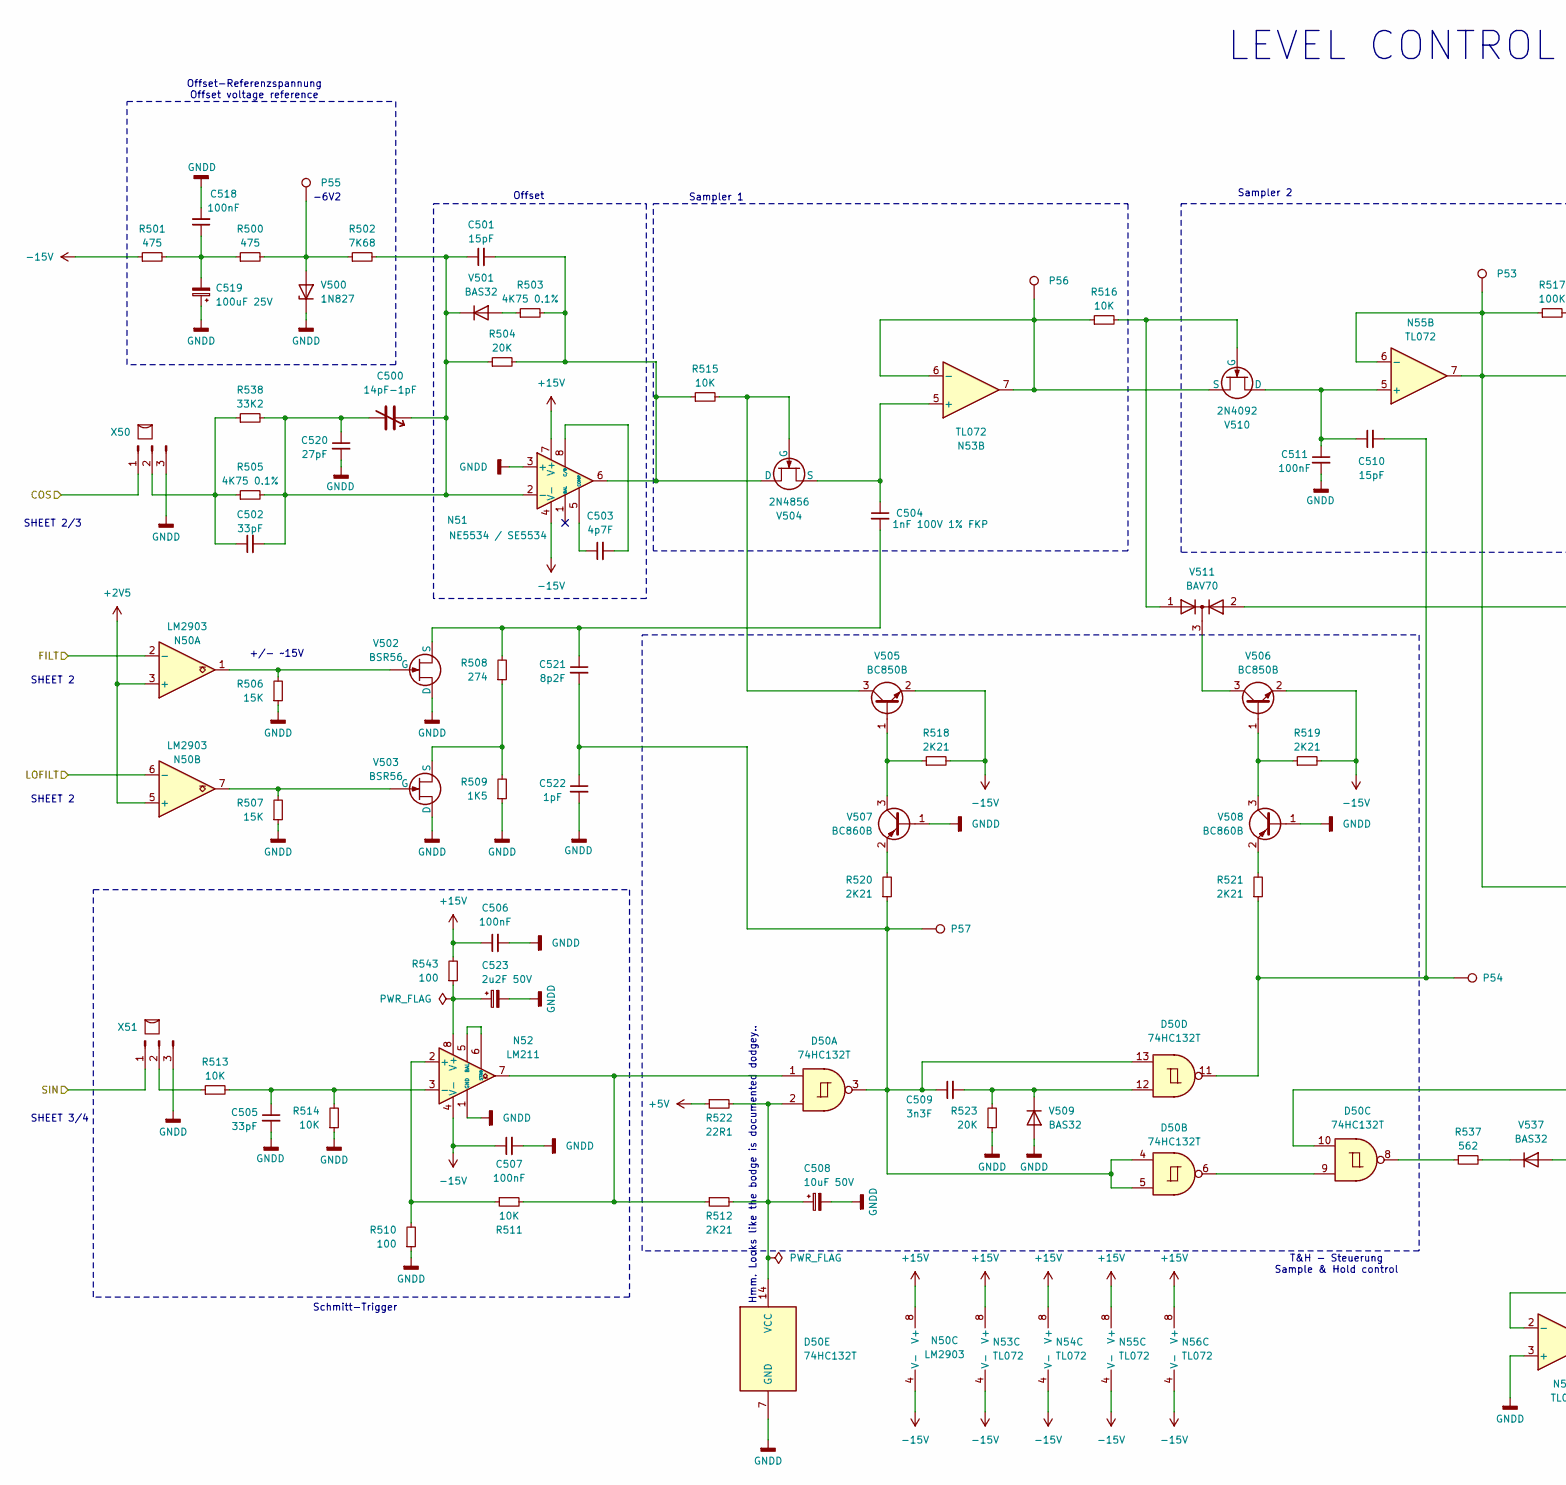
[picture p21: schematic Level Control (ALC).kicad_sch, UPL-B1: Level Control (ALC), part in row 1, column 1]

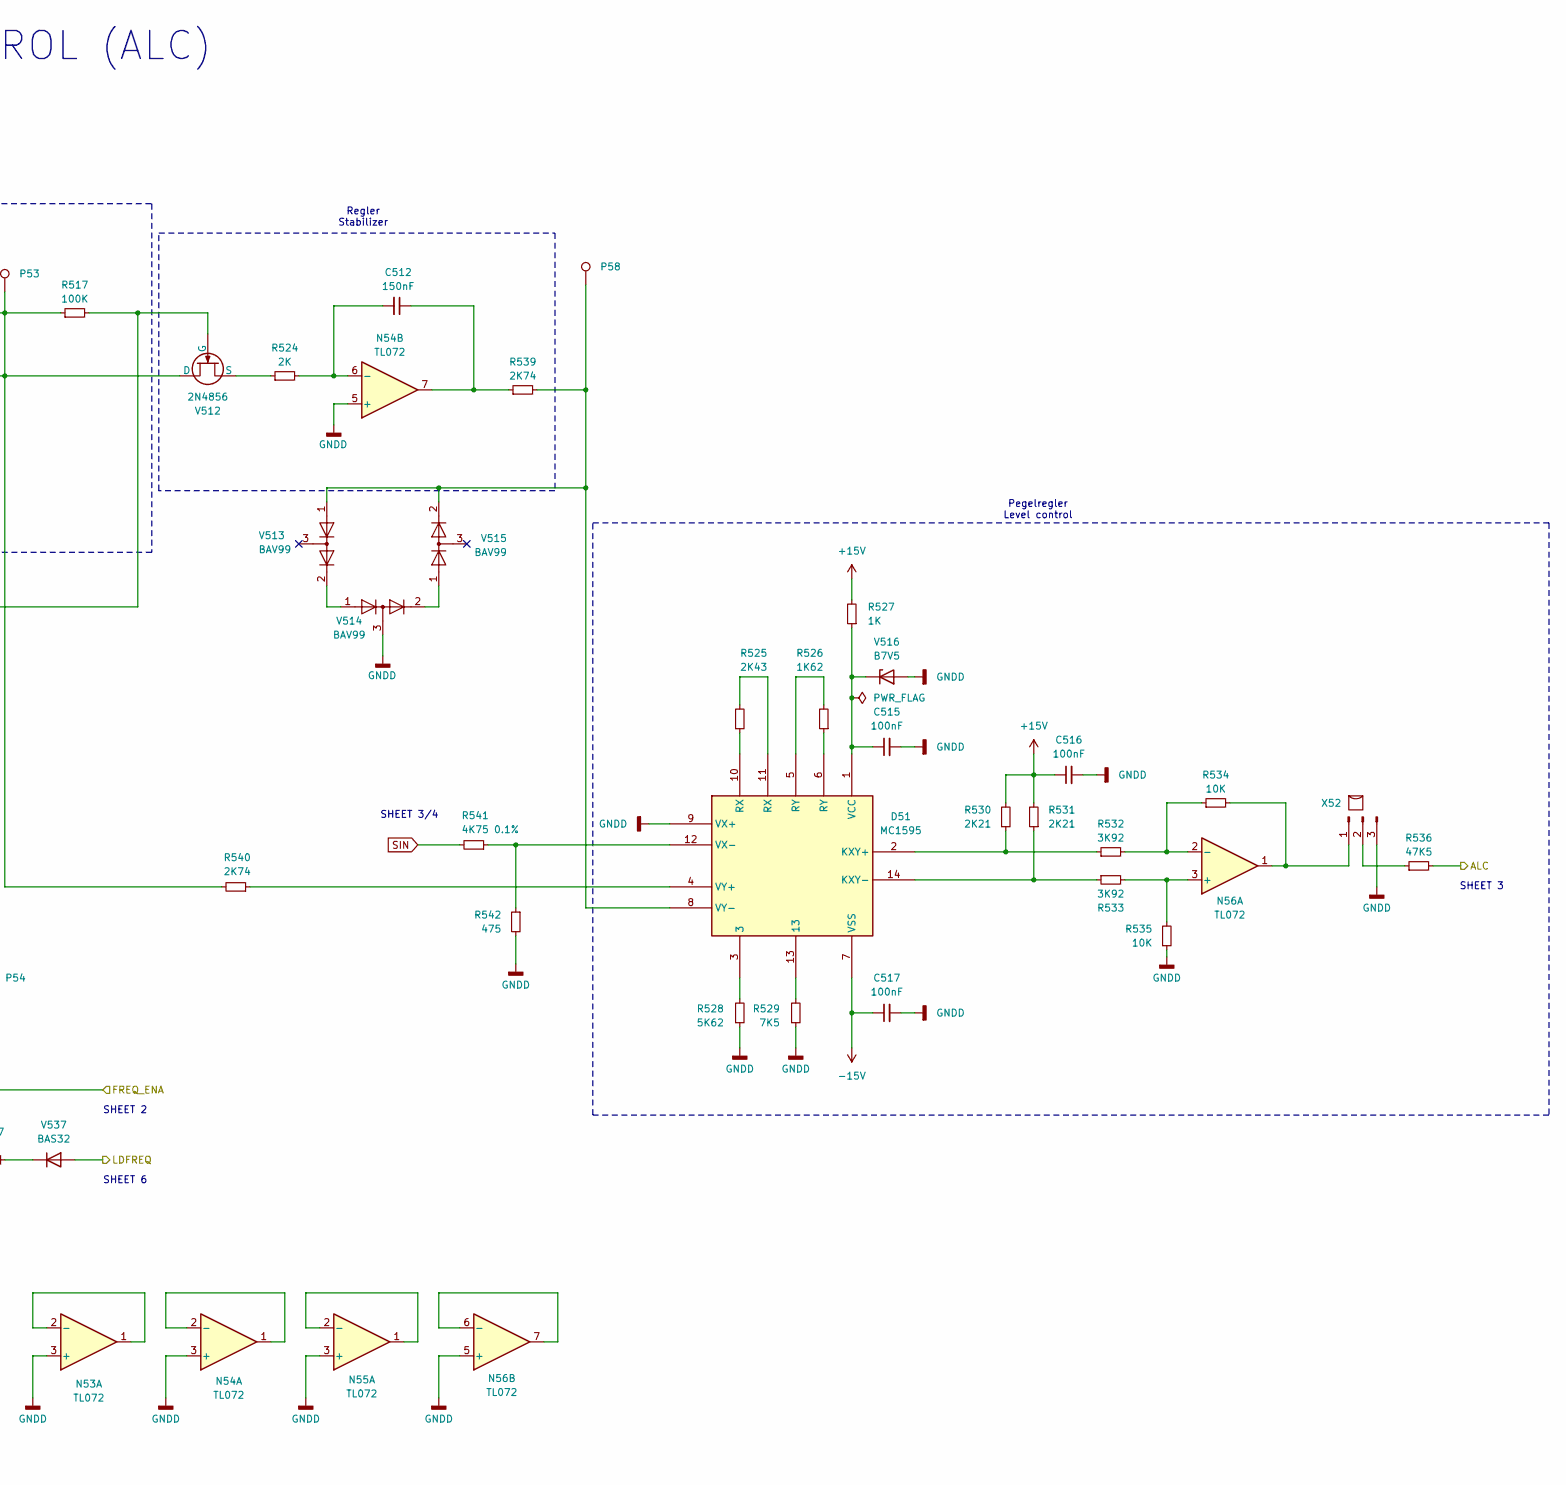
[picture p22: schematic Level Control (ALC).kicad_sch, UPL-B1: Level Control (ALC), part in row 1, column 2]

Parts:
C500: 14pF-1pF
C501, C510: 15pF; C_1206_3216Metric_Pad1.33x1.80mm_HandSolder
C502, C505: 33pF; C_1206_3216Metric_Pad1.33x1.80mm_HandSolder
C503: 4p7F; C_1206_3216Metric_Pad1.33x1.80mm_HandSolder
C504: 1nF 100V 1% FKP
C506, C507, C511, C515, C516, C517, C518: 100nF; C_1206_3216Metric_Pad1.33x1.80mm_HandSolder
C508: 10uF 50V; C_Radial_D6.3mm_H11.0mm_P2.50mm
C509: 3n3F; C_1206_3216Metric_Pad1.33x1.80mm_HandSolder
C512: 150nF
C519: 100uF 25V; C_Radial_D6.3mm_H11.0mm_P2.50mm
C520: 27pF; C_1206_3216Metric_Pad1.33x1.80mm_HandSolder
C521: 8p2F; C_1206_3216Metric_Pad1.33x1.80mm_HandSolder
C522: 1pF; C_1206_3216Metric_Pad1.33x1.80mm_HandSolder
C523: 2u2F 50V; C_Radial_D6.3mm_H11.0mm_P2.50mm
D50: 74HC132T; SOIC-14_3.9x8.7mm_P1.27mm
D51: MC1595; DIP-14_W7.62mm
N50: LM2903; SOIC-8_3.9x4.9mm_P1.27mm
N51: NE5534 / SE5534; SOIC-8_3.9x4.9mm_P1.27mm
N52: LM211; SOIC-8_3.9x4.9mm_P1.27mm
N53, N54, N55, N56: TL072; SOIC-8_3.9x4.9mm_P1.27mm
P53, P54, P55, P56, P57, P58: TestPoint; PinHeader_1x01_P1.00mm_Vertical
R500, R501, R542: 475; R_1206_3216Metric_Pad1.30x1.75mm_HandSolder
R502: 7K68; R_Axial_DIN0204_L3.6mm_D1.6mm_P7.62mm_Horizontal
R503, R541: 4K75 0.1%; R_1206_3216Metric_Pad1.30x1.75mm_HandSolder
R504, R523: 20K; R_1206_3216Metric_Pad1.30x1.75mm_HandSolder
R505: 4K75 0.1%; R_Axial_DIN0204_L3.6mm_D1.6mm_P7.62mm_Horizontal
R506, R507: 15K; R_1206_3216Metric_Pad1.30x1.75mm_HandSolder
R508: 274; R_1206_3216Metric_Pad1.30x1.75mm_HandSolder
R509: 1K5; R_1206_3216Metric_Pad1.30x1.75mm_HandSolder
R510, R543: 100; R_1206_3216Metric_Pad1.30x1.75mm_HandSolder
R511, R513, R514, R515, R516, R534, R535: 10K; R_1206_3216Metric_Pad1.30x1.75mm_HandSolder
R512, R518, R519, R520, R521, R530, R531: 2K21; R_1206_3216Metric_Pad1.30x1.75mm_HandSolder
R517: 100K; R_1206_3216Metric_Pad1.30x1.75mm_HandSolder
R522: 22R1; R_1206_3216Metric_Pad1.30x1.75mm_HandSolder
R524: 2K; R_1206_3216Metric_Pad1.30x1.75mm_HandSolder
R525: 2K43; R_1206_3216Metric_Pad1.30x1.75mm_HandSolder
R526: 1K62; R_1206_3216Metric_Pad1.30x1.75mm_HandSolder
R527: 1K; R_1206_3216Metric_Pad1.30x1.75mm_HandSolder
R528: 5K62; R_1206_3216Metric_Pad1.30x1.75mm_HandSolder
R529: 7K5; R_1206_3216Metric_Pad1.30x1.75mm_HandSolder
R532, R533: 3K92; R_1206_3216Metric_Pad1.30x1.75mm_HandSolder
R536: 47K5; R_1206_3216Metric_Pad1.30x1.75mm_HandSolder
R537: 562; R_1206_3216Metric_Pad1.30x1.75mm_HandSolder
R538: 33K2; R_1206_3216Metric_Pad1.30x1.75mm_HandSolder
R539, R540: 2K74; R_1206_3216Metric_Pad1.30x1.75mm_HandSolder
V500: 1N827; D_DO-35_SOD27_P7.62mm_Horizontal
V501, V509, V537: BAS32; D_SOD-523
V502, V503: BSR56; SOT-23
V504, V512: 2N4856; TO-52-3
V505, V506: BC850B; SOT-23
V507, V508: BC860B; SOT-23
V510: 2N4092; TO-52-3
V511: BAV70; SOT-23
V513, V514, V515: BAV99; SOT-23
V516: B7V5; D_DO-41_SOD81_P10.16mm_Horizontal
X50, X51, X52: Conn_01x03_Pin_Bridge; PinHeader_1x03_P2.54mm_Vertical

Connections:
+2V5: N50.3 (+), N50.5 (+); also elsewhere on the board
+5V: R522.1; also elsewhere on the board
+15V: C506.1, C516.1, N50.8 (V+), N51.7 (V+), N53.8 (V+), N54.8 (V+), N55.8 (V+), N56.8 (V+), R527.2, R530.2, R531.2, R543.2; also elsewhere on the board
-15V: C507.1, C517.1, D51.7 (VSS), N50.4 (V-), N51.4 (V-), N52.4 (V-), N53.4 (V-), N54.4 (V-), N55.4 (V-), N56.4 (V-), R501.1, R518.2, R519.2, V505.2 (E), V506.2 (E); also elsewhere on the board
/COS: X50.1; also elsewhere on the board
/Integrator 1 & Loop Inverter/ALC: R536.2; also elsewhere on the board
/Level Control (ALC)/FILT: N50.2 (-); also elsewhere on the board
/Level Control (ALC)/FREQ_ENA: D50.10; also elsewhere on the board
/Level Control (ALC)/LDFREQ: V537.2 (A)
/Level Control (ALC)/LOFILT: N50.6 (-); also elsewhere on the board
GNDD: C505.2, C506.2, C507.2, C508.2, C511.2, C515.2, C516.2, C517.2, C518.2, C519.1, C520.2, C522.2, C523.2, D50.7 (GND), D51.9 (VX+), N51.3 (+), N52.1 (GND), N53.3 (+), N54.3 (+), N54.5 (+), N55.3 (+), N56.5 (+), R506.1, R507.1, R509.1, R510.1, R514.1, R523.1, R528.1, R529.1, R535.1, R542.2, V500.1 (K), V502.1 (D), V503.1 (D), V507.1 (B), V508.1 (B), V509.2 (A), V514.3 (K), V516.2 (A), X50.3, X51.3, X52.3; also elsewhere on the board
unnamed: C509.1, C521.2, C522.1, D50.3, D50.4, D50.5, D50.13, P57.1, R520.1
unnamed: C510.2, D50.11, P54.1, R521.1
unnamed: C512.1, N54.7, R539.1
unnamed: C518.1, C519.2, R500.1, R501.2
unnamed: D50.1, N52.7, R511.2, R512.1
unnamed: D50.6, D50.9
unnamed: D50.8, R537.1
unnamed: C508.1, D50.2, D50.14 (VCC), R512.2, R522.2
unnamed: D51.2 (KXY+), R530.1, R532.1
unnamed: D51.14 (KXY-), R531.1, R533.1
unnamed: D51.3, R528.2
unnamed: D51.13, R529.2
unnamed: D51.10 (RX), R525.1
unnamed: D51.11 (RX), R525.2
unnamed: D51.5 (RY), R526.2
unnamed: D51.6 (RY), R526.1
unnamed: C515.1, D51.1 (VCC), R527.1, V516.1 (K)
unnamed: D51.12 (VX-), R541.1, R542.1
unnamed: D51.4 (VY+), R540.1
unnamed: D51.8 (VY-), P58.1, R539.2, V513.1 (K), V515.2 (A)
unnamed: C500.1, C500.2, C501.1, C502.2, C520.1, N51.2 (-), R502.2, R504.1, R505.2, R538.2, V501.1 (K)
unnamed: C503.1, N51.5 (COMP)
unnamed: C503.2, N51.8 (C/B)
unnamed: N52.2 (+), R510.2, R511.1
unnamed: C505.1, N52.3 (-), R513.2, R514.2
unnamed: N52.5 (BAL), N52.6 (STRB)
unnamed: C523.1, N52.8 (V+), R543.1
unnamed: N53.1, N53.2 (-)
unnamed: C504.1, N53.5 (+), V504.3 (S)
unnamed: N53.6 (-), N53.7, P56.1, R516.1, V510.3 (S)
unnamed: N54.1, N54.2 (-)
unnamed: C512.2, N54.6 (-), R524.2
unnamed: N55.1, N55.2 (-)
unnamed: C510.1, C511.1, N55.5 (+), V510.1 (D)
unnamed: N55.6 (-), N55.7, P53.1, R517.1, R540.2, V512.1 (D)
unnamed: N56.3 (+), R533.2, R535.2
unnamed: N56.2 (-), R532.2, R534.1
unnamed: N56.6 (-), N56.7
unnamed: P55.1, R500.2, R502.1, V500.2 (A)
unnamed: R503.1, V501.2 (A)
unnamed: N50.1, R506.2, V502.2 (G)
unnamed: C504.2, C521.1, R508.2, V502.3 (S)
unnamed: N50.7, R507.2, V503.2 (G)
unnamed: R508.1, R509.2, V503.3 (S)
unnamed: C501.2, N51.6, R503.2, R504.2, R515.1, V504.1 (D)
unnamed: R515.2, V504.2 (G), V505.3 (C)
unnamed: R518.1, V505.1 (B), V507.3 (C)
unnamed: R519.1, V506.1 (B), V508.3 (C)
unnamed: V506.3 (C), V511.3 (K)
unnamed: R520.2, V507.2 (E)
unnamed: R521.2, V508.2 (E)
unnamed: C509.2, D50.12, R523.2, V509.1 (K)
unnamed: R516.2, V510.2 (G), V511.1 (A)
unnamed: R517.2, V511.2 (A), V512.2 (G)
unnamed: R524.1, V512.3 (S)
unnamed: V513.2 (A), V514.1 (K)
unnamed: V514.2 (A), V515.1 (K)
unnamed: R537.2, V537.1 (K)
unnamed: C502.1, R505.1, R538.1, X50.2
unnamed: R513.1, X51.2
unnamed: N56.1, R534.2, X52.1
unnamed: R536.1, X52.2
SIN: R541.2, X51.1; also elsewhere on the board

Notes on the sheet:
Regler Stabilizer
Schmitt-Trigger
SHEET 2
+/- ~15V
LEVEL CONTROL (ALC)
SHEET 2/3
SHEET 3/4
SHEET 6
Sampler 1
Sampler 2
-6V2
Offset
Hmm. Looks like the bodge is documented dodgey..
SHEET 3
Pegelregler Level control
Offset-Referenzspannung Offset voltage reference
T&H - Steuerung Sample & Hold control

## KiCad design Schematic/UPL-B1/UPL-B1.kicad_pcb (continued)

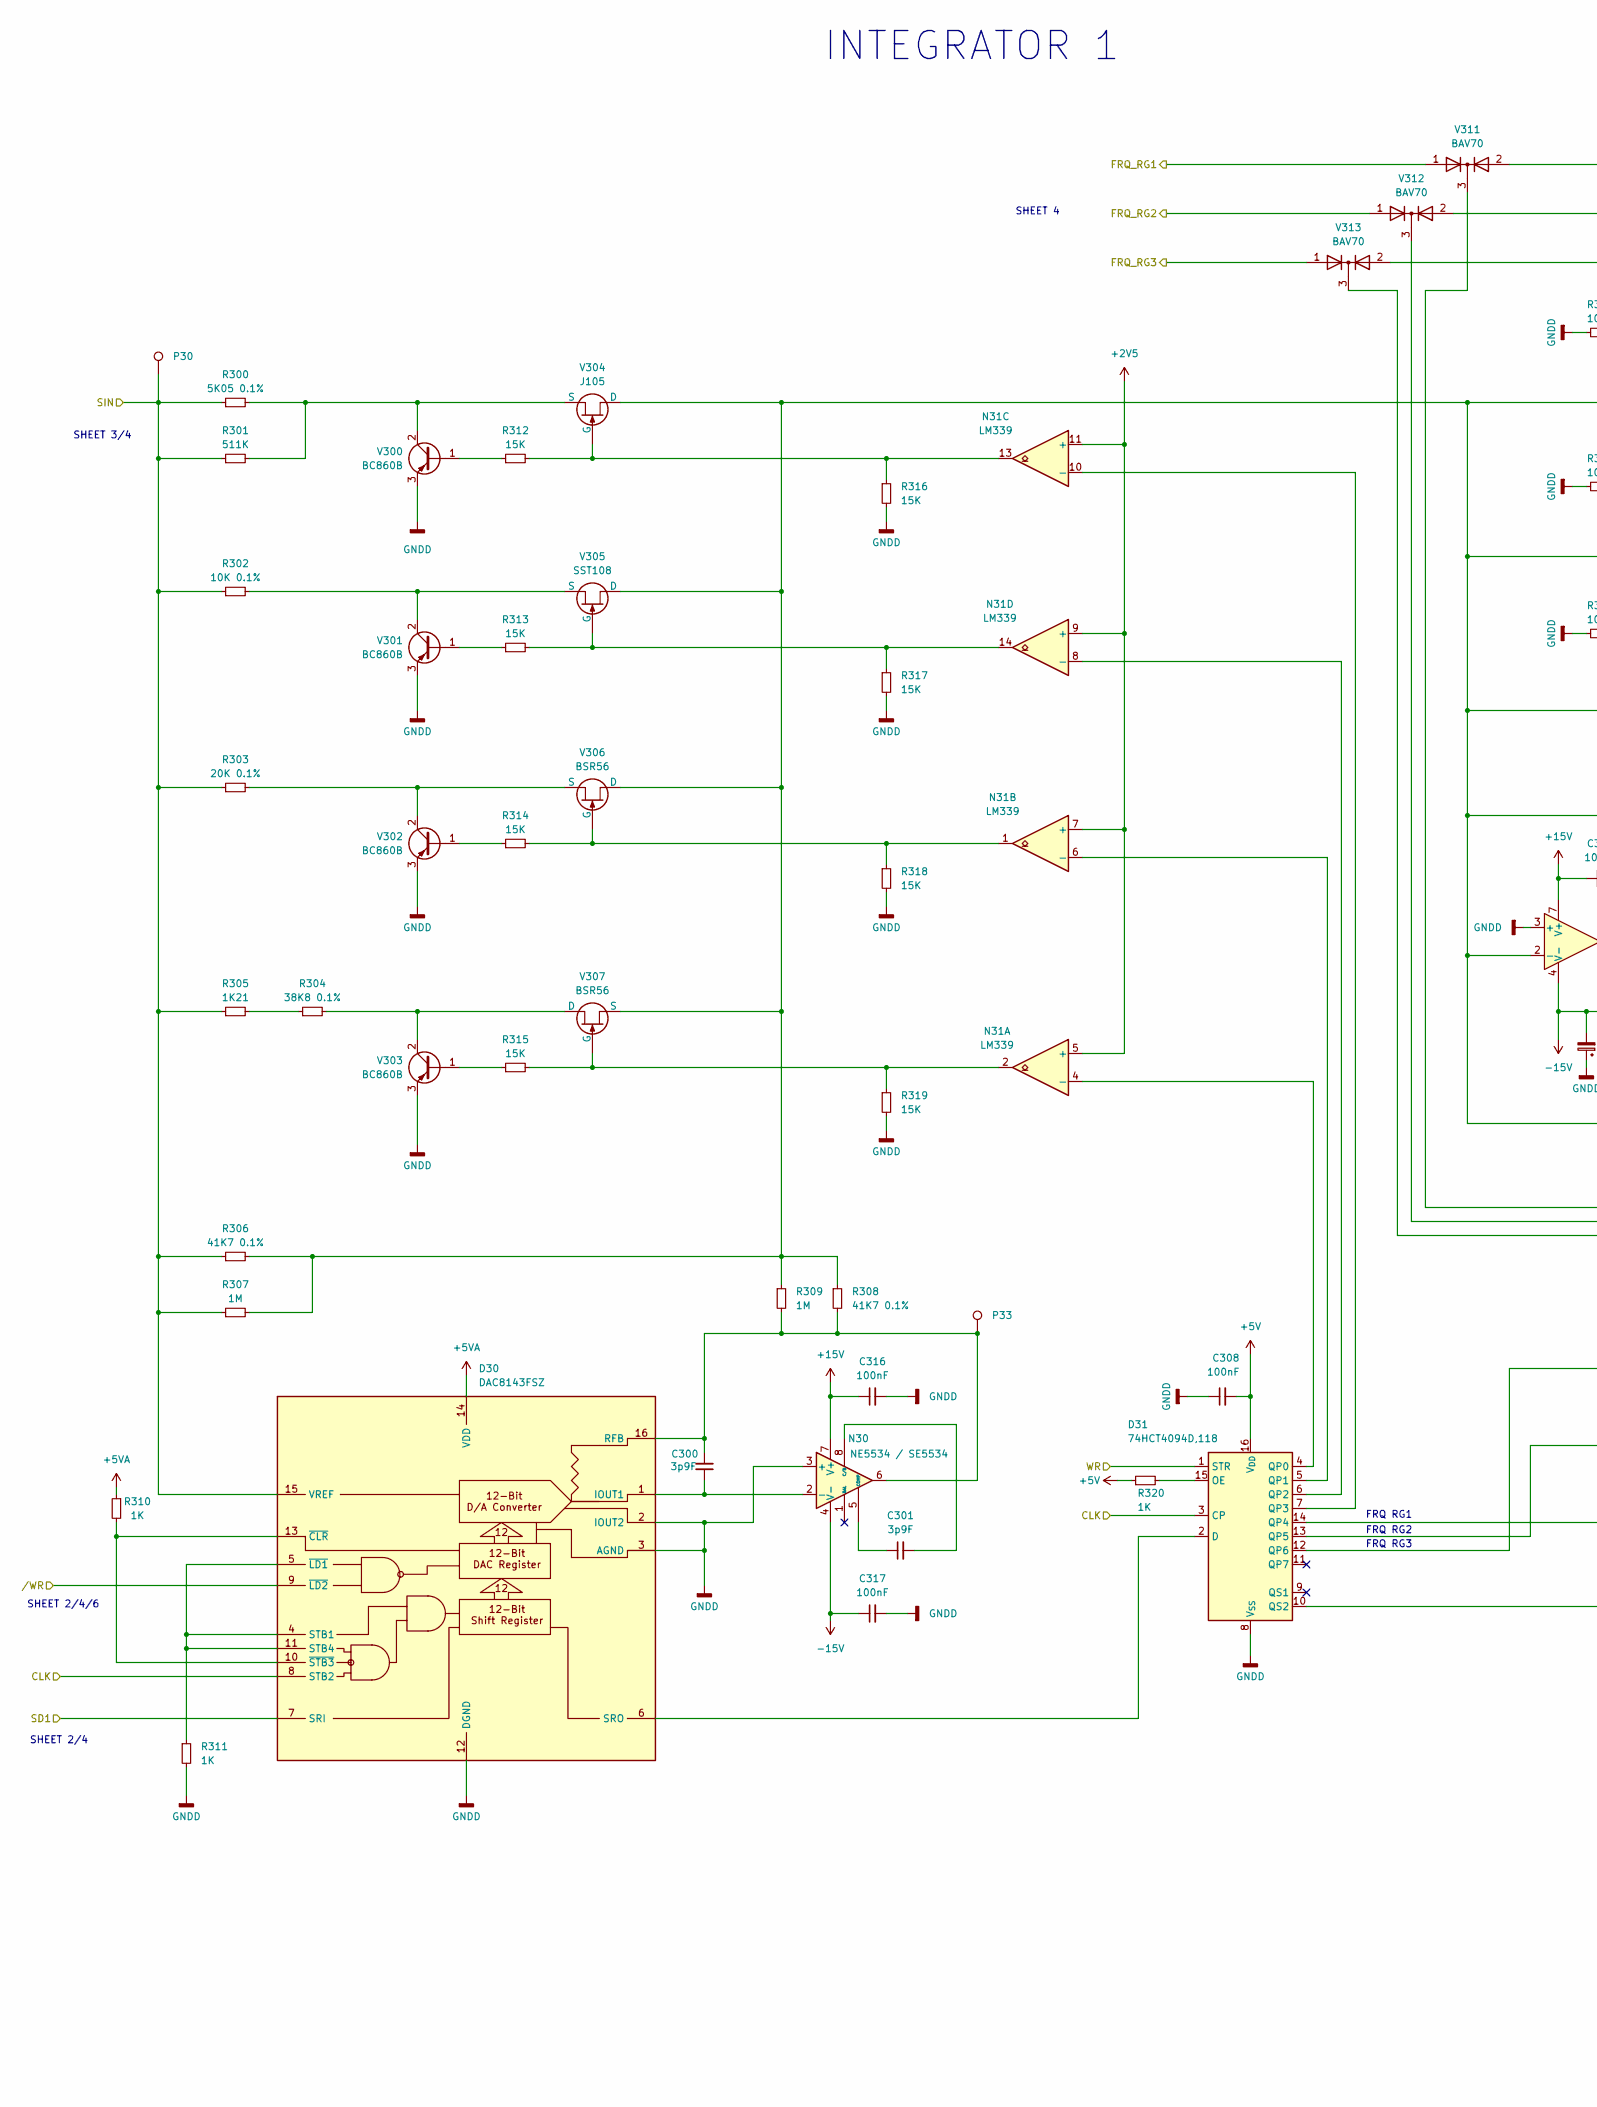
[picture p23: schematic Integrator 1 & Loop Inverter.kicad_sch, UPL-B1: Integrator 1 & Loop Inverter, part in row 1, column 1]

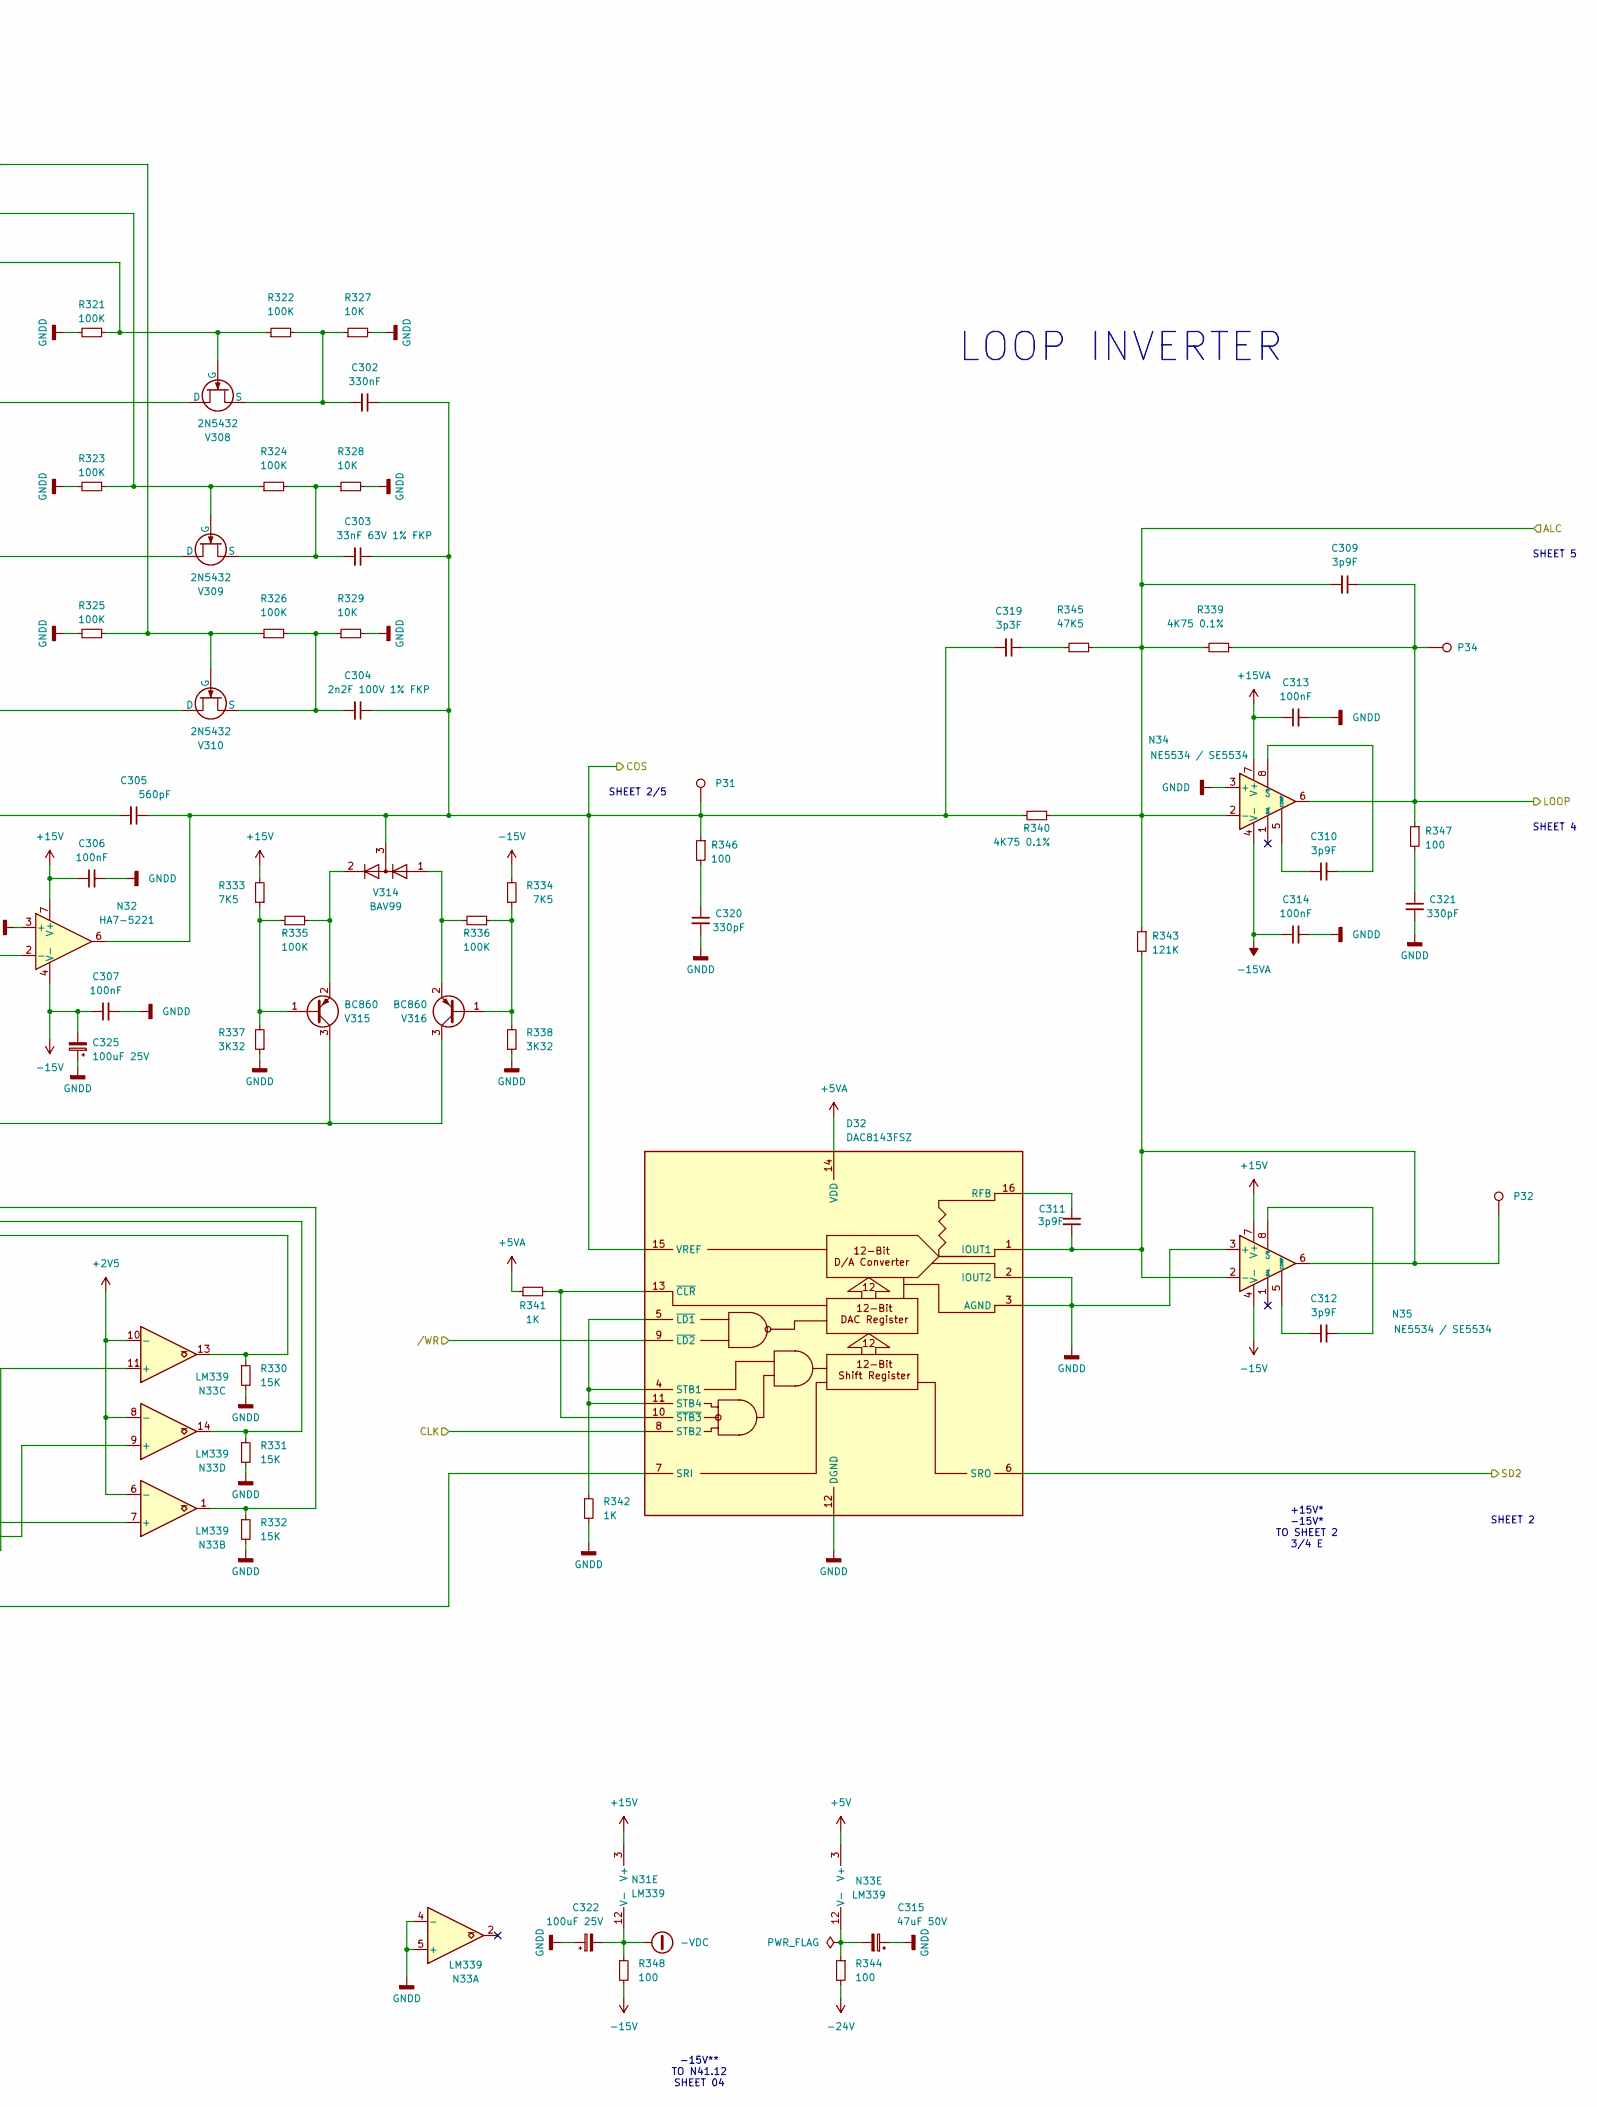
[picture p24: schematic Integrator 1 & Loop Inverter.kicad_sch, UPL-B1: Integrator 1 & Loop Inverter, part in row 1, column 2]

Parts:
C300, C301, C309, C310, C311, C312: 3p9F; C_1206_3216Metric_Pad1.33x1.80mm_HandSolder
C302: 330nF; C_Axial_L17.0mm_D7.0mm_P25.00mm_Horizontal
C303: 33nF 63V 1% FKP
C304: 2n2F 100V 1% FKP
C305: 560pF; C_1206_3216Metric_Pad1.33x1.80mm_HandSolder
C306, C307, C308, C313, C314, C316, C317: 100nF; C_1206_3216Metric_Pad1.33x1.80mm_HandSolder
C315: 47uF 50V; C_Radial_D6.3mm_H11.0mm_P2.50mm
C319: 3p3F; C_1206_3216Metric_Pad1.33x1.80mm_HandSolder
C320, C321: 330pF; C_1206_3216Metric_Pad1.33x1.80mm_HandSolder
C322, C325: 100uF 25V; C_Radial_D6.3mm_H11.0mm_P2.50mm
D30, D32: DAC8143FSZ; SOIC-16W_7.5x10.3mm_P1.27mm; Manufacturer_Part_Number DAC8143FSZ
D31: 74HCT4094D,118; SOIC-16_3.9x9.9mm_P1.27mm; Mouser Part Number 771-74HCT4094D-T
N30, N34, N35: NE5534 / SE5534; SOIC-8_3.9x4.9mm_P1.27mm
N31, N33: LM339; SOIC-14_3.9x8.7mm_P1.27mm
N32: HA7-5221; MSOP-8_3x3mm_P0.65mm
P30, P31, P32, P33, P34: TestPoint; PinHeader_1x01_P1.00mm_Vertical
R300: 5K05 0.1%; R_Axial_DIN0204_L3.6mm_D1.6mm_P7.62mm_Horizontal
R301: 511K; R_1206_3216Metric_Pad1.30x1.75mm_HandSolder
R302: 10K 0.1%; R_Axial_DIN0204_L3.6mm_D1.6mm_P7.62mm_Horizontal
R303: 20K 0.1%; R_Axial_DIN0204_L3.6mm_D1.6mm_P7.62mm_Horizontal
R304: 38K8 0.1%; R_Axial_DIN0204_L3.6mm_D1.6mm_P7.62mm_Horizontal
R305: 1K21; R_1206_3216Metric_Pad1.30x1.75mm_HandSolder
R306, R308: 41K7 0.1%; R_Axial_DIN0204_L3.6mm_D1.6mm_P7.62mm_Horizontal
R307, R309: 1M; R_1206_3216Metric_Pad1.30x1.75mm_HandSolder
R310, R311, R320, R341, R342: 1K; R_1206_3216Metric_Pad1.30x1.75mm_HandSolder
R312, R313, R314, R315, R316, R317, R318, R319, R330, R331, R332: 15K; R_1206_3216Metric_Pad1.30x1.75mm_HandSolder
R321, R322, R323, R324, R325, R326, R335, R336: 100K; R_1206_3216Metric_Pad1.30x1.75mm_HandSolder
R327, R328, R329: 10K; R_1206_3216Metric_Pad1.30x1.75mm_HandSolder
R333, R334: 7K5; R_1206_3216Metric_Pad1.30x1.75mm_HandSolder
R337, R338: 3K32; R_1206_3216Metric_Pad1.30x1.75mm_HandSolder
R339, R340: 4K75 0.1%; R_Axial_DIN0204_L3.6mm_D1.6mm_P7.62mm_Horizontal
R343: 121K; R_1206_3216Metric_Pad1.30x1.75mm_HandSolder
R344, R346, R347, R348: 100; R_1206_3216Metric_Pad1.30x1.75mm_HandSolder
R345: 47K5; R_1206_3216Metric_Pad1.30x1.75mm_HandSolder
V300, V301, V302, V303: BC860B; SOT-23
V304: J105; TO-92L_Inline
V305: SST108; SOT-23
V306, V307: BSR56; SOT-23
V308, V309, V310: 2N5432; TO-52-3
V311, V312, V313: BAV70; SOT-23
V314: BAV99; SOT-23
V315, V316: BC860; SOT-23

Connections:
+2V5: N31.5 (+), N31.7 (+), N31.9 (+), N31.11 (+), N33.6 (-), N33.8 (-), N33.10 (-); also elsewhere on the board
+5V: C308.2, D31.16 (V_{DD}), N33.3 (V+), R320.1; also elsewhere on the board
+5VA: D30.14 (VDD), D32.14 (VDD), R310.1, R341.1; also elsewhere on the board
+15V: C306.1, C316.1, N30.7 (V+), N31.3 (V+), N32.7 (V+), N35.7 (V+), R333.2; also elsewhere on the board
+15VA: C313.1, N34.7 (V+); also elsewhere on the board
-15V: C307.1, C317.1, C325.2, N30.4 (V-), N32.4 (V-), N35.4 (V-), R334.2, R348.2; also elsewhere on the board
-15VA: C314.1, N34.4 (V-); also elsewhere on the board
-24V: R344.2; also elsewhere on the board
-VDC: C322.2, N31.12 (V-), R348.1; also elsewhere on the board
/CLK: D30.8 (STB2), D31.3 (CP), D32.8 (STB2); also elsewhere on the board
/COS: C302.1, C303.1, C304.1, C305.1, C319.2, D32.15 (VREF), N32.6, P31.1, R340.2, R346.1, V314.3 (K); also elsewhere on the board
/Integrator 1 & Loop Inverter/ALC: C309.2, N34.2 (-), R339.2, R340.1, R343.1, R345.1; also elsewhere on the board
/Integrator 1 & Loop Inverter/FRQ_RG1: V311.1 (A); also elsewhere on the board
/Integrator 1 & Loop Inverter/FRQ_RG2: V312.1 (A); also elsewhere on the board
/Integrator 1 & Loop Inverter/FRQ_RG3: V313.1 (A); also elsewhere on the board
/Integrator 1 & Loop Inverter/SD2: D32.6 (SRO); also elsewhere on the board
/Integrator 1 & Loop Inverter/WR: D31.1 (STR)
/LOOP: C309.1, N34.6, P34.1, R339.1, R347.1; also elsewhere on the board
/SD1: D30.7 (SRI); also elsewhere on the board
/~WR: D30.9 (~LD2), D32.9 (~LD2); also elsewhere on the board
GNDD: C306.2, C307.2, C308.1, C313.2, C314.2, C315.1, C316.2, C317.2, C320.2, C321.2, C322.1, C325.1, D30.2 (IOUT2), D30.3 (AGND), D30.12 (DGND), D31.8 (V_{SS}), D32.2 (IOUT2), D32.3 (AGND), D32.12 (DGND), N30.3 (+), N32.3 (+), N33.4 (-), N33.5 (+), N34.3 (+), N35.3 (+), R311.2, R316.2, R317.2, R318.2, R319.2, R321.2, R323.2, R325.2, R327.2, R328.2, R329.2, R330.2, R331.2, R332.2, R337.1, R338.1, R342.2, V300.3 (E), V301.3 (E), V302.3 (E), V303.3 (E); also elsewhere on the board
unnamed: C319.1, R345.2
unnamed: C320.1, R346.2
unnamed: C321.1, R347.2
unnamed: C300.1, D30.1 (IOUT1), N30.2 (-)
unnamed: C300.2, D30.16 (RFB), N30.6, P33.1, R308.2, R309.2
unnamed: D30.6 (SRO), D31.2 (D)
unnamed: D30.4 (STB1), D30.5 (~LD1), D30.11 (STB4), R311.1
unnamed: D30.10 (~STB3), D30.13 (~CLR), R310.2
unnamed: D31.15 (OE), R320.2
unnamed: D31.4 (QP0), N31.4 (-)
unnamed: D31.5 (QP1), N31.6 (-)
unnamed: D31.6 (QP2), N31.8 (-)
unnamed: D31.7 (QP3), N31.10 (-)
unnamed: D31.14 (QP4), N33.7 (+)
unnamed: D31.13 (QP5), N33.9 (+)
unnamed: D31.12 (QP6), N33.11 (+)
unnamed: D31.10 (QS2), D32.7 (SRI)
unnamed: C311.1, D32.1 (IOUT1), N35.2 (-), N35.6, P32.1, R343.2
unnamed: C311.2, D32.16 (RFB)
unnamed: D32.4 (STB1), D32.5 (~LD1), D32.11 (STB4), R342.1
unnamed: D32.10 (~STB3), D32.13 (~CLR), R341.2
unnamed: C301.1, N30.5 (COMP)
unnamed: C301.2, N30.8 (C/B)
unnamed: C305.2, N32.2 (-), R306.2, R307.2, R308.1, R309.1, V304.1 (D), V305.1 (D), V306.1 (D), V307.3 (S), V308.1 (D), V309.1 (D), V310.1 (D), V315.3 (C), V316.3 (C)
unnamed: C315.2, N33.12 (V-), R344.1
unnamed: C310.1, N34.5 (COMP)
unnamed: C310.2, N34.8 (C/B)
unnamed: C312.1, N35.5 (COMP)
unnamed: C312.2, N35.8 (C/B)
unnamed: R304.1, R305.2
unnamed: R312.1, V300.1 (B)
unnamed: R300.2, R301.2, V300.2 (C), V304.3 (S)
unnamed: R313.1, V301.1 (B)
unnamed: R302.2, V301.2 (C), V305.3 (S)
unnamed: R314.1, V302.1 (B)
unnamed: R303.2, V302.2 (C), V306.3 (S)
unnamed: R315.1, V303.1 (B)
unnamed: R304.2, V303.2 (C), V307.1 (D)
unnamed: N31.13, R312.2, R316.1, V304.2 (G)
unnamed: N31.14, R313.2, R317.1, V305.2 (G)
unnamed: N31.1, R314.2, R318.1, V306.2 (G)
unnamed: N31.2, R315.2, R319.1, V307.2 (G)
unnamed: R321.1, R322.1, V308.2 (G), V313.2 (A)
unnamed: C302.2, R322.2, R327.1, V308.3 (S)
unnamed: R323.1, R324.1, V309.2 (G), V312.2 (A)
unnamed: C303.2, R324.2, R328.1, V309.3 (S)
unnamed: R325.1, R326.1, V310.2 (G), V311.2 (A)
unnamed: C304.2, R326.2, R329.1, V310.3 (S)
unnamed: N33.1, R332.1, V311.3 (K)
unnamed: N33.14, R331.1, V312.3 (K)
unnamed: N33.13, R330.1, V313.3 (K)
unnamed: R335.2, V314.2 (A), V315.2 (E)
unnamed: R333.1, R335.1, R337.2, V315.1 (B)
unnamed: R334.1, R336.1, R338.2, V316.1 (B)
unnamed: R336.2, V314.1 (K), V316.2 (E)
SIN: D30.15 (VREF), P30.1, R300.1, R301.1, R302.1, R303.1, R305.1, R306.1, R307.1; also elsewhere on the board

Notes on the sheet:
INTEGRATOR 1
+15V* -15V* TO SHEET 2 3/4 E
SHEET 4
SHEET 2/4/6
FRQ RG1
LOOP INVERTER
FRQ RG3
SHEET 2/4
FRQ RG2
SHEET 3/4
SHEET 2/5
-15V** TO N41.12 SHEET 04
SHEET 2
SHEET 5

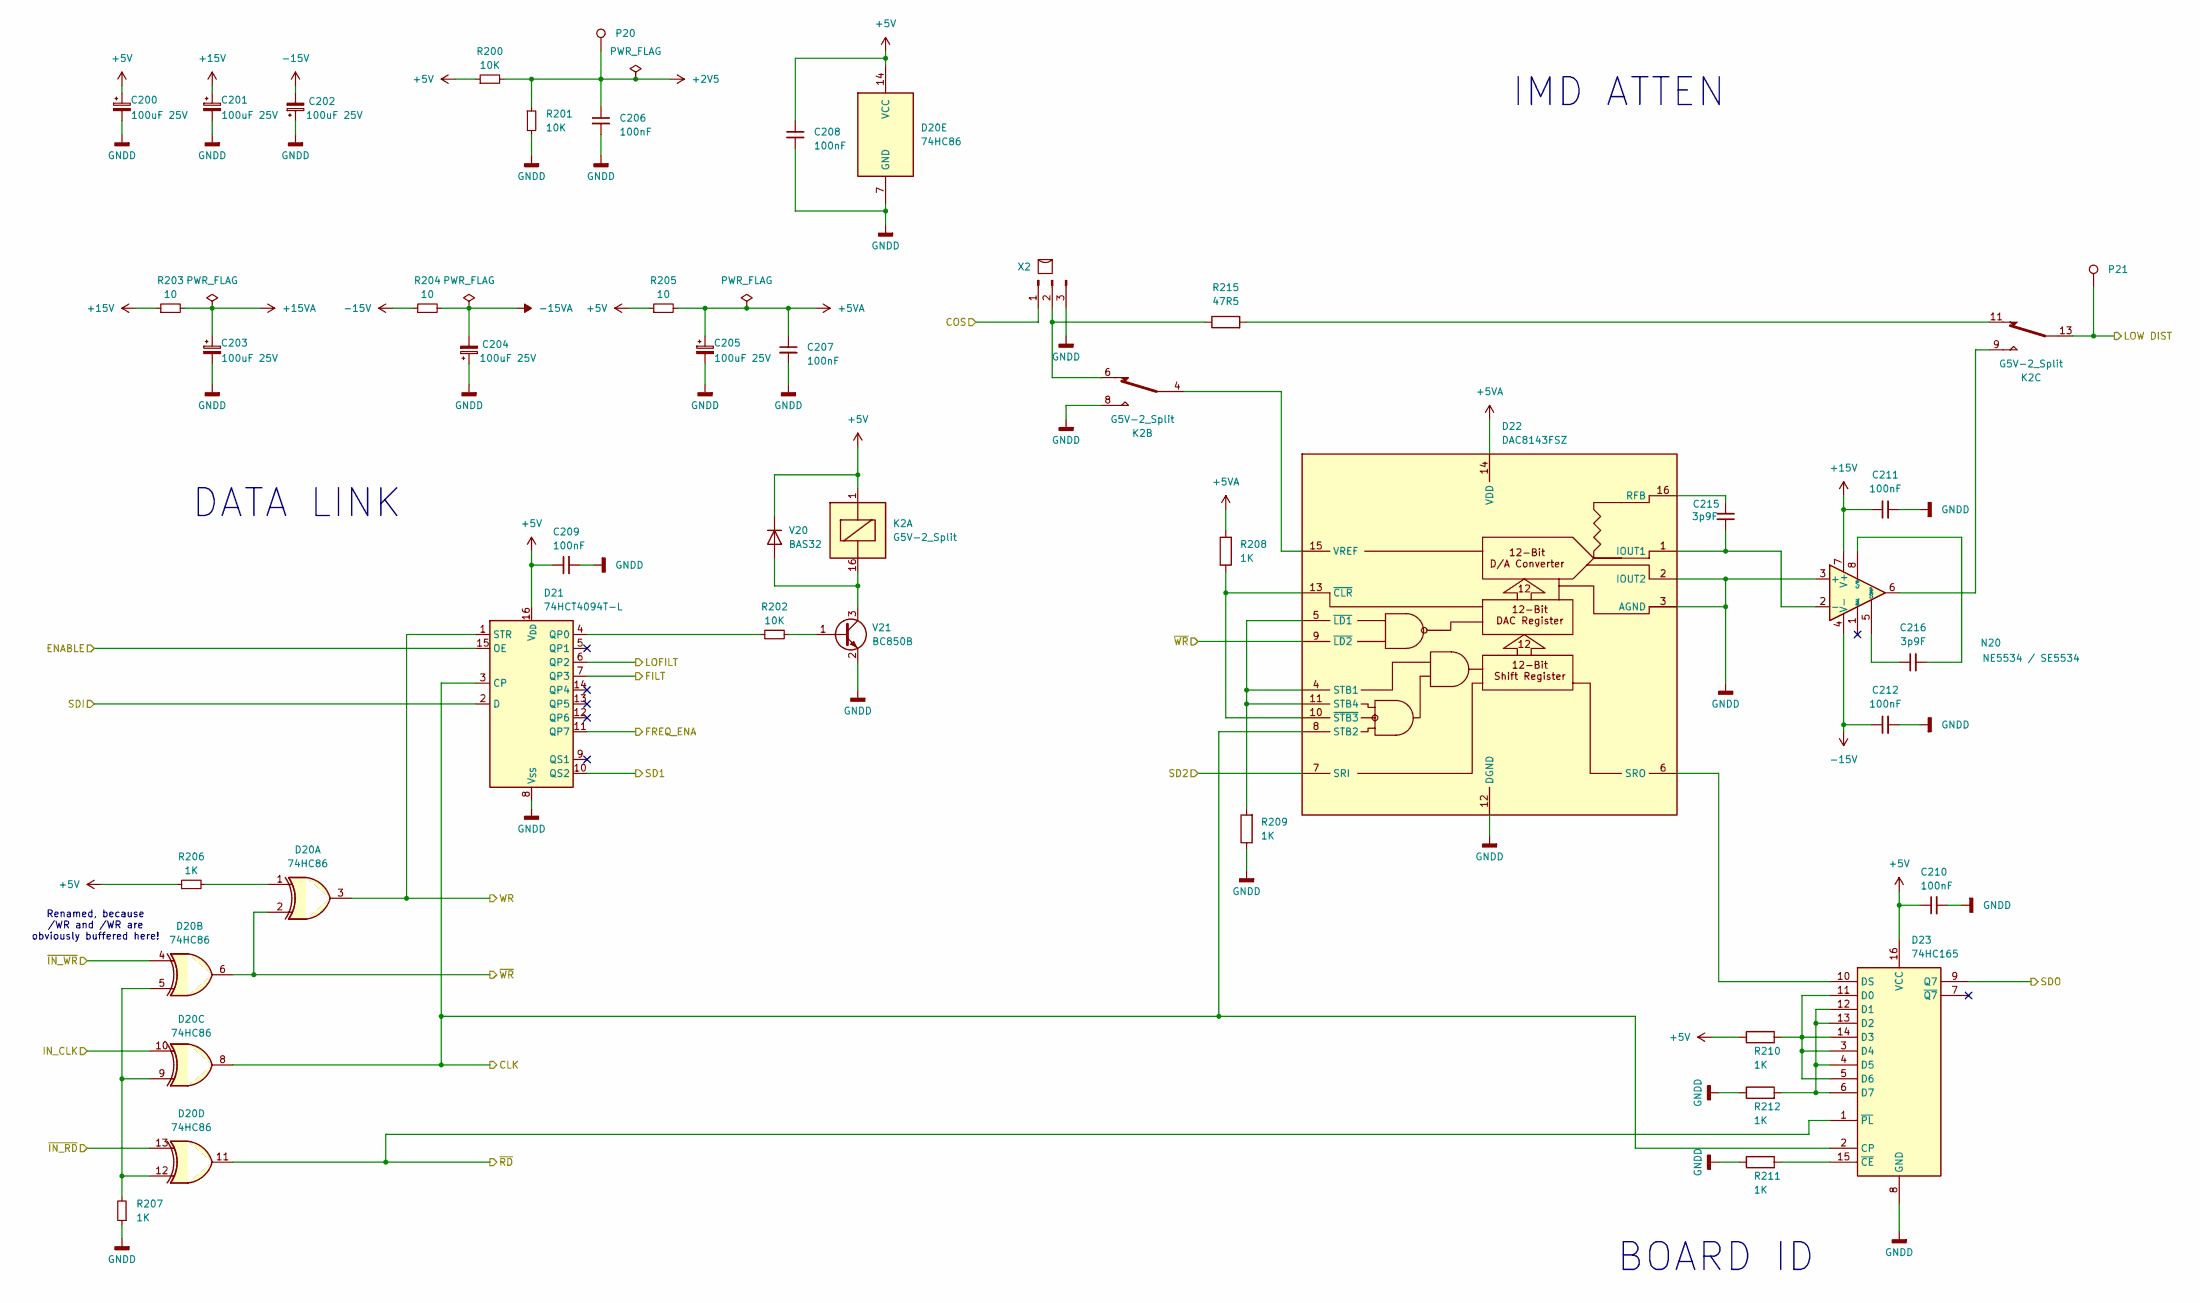
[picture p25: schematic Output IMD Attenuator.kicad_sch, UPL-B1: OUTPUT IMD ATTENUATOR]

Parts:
C200, C201, C202, C203, C204, C205: 100uF 25V; C_Radial_D6.3mm_H11.0mm_P2.50mm
C206, C207, C208, C209, C210, C211, C212: 100nF; C_1206_3216Metric_Pad1.33x1.80mm_HandSolder
C215, C216: 3p9F; C_1206_3216Metric_Pad1.33x1.80mm_HandSolder
D20: 74HC86; SOIC-14_3.9x8.7mm_P1.27mm
D21: 74HCT4094T-L; SOIC-16_3.9x9.9mm_P1.27mm
D22: DAC8143FSZ; SOIC-16W_7.5x10.3mm_P1.27mm
D23: 74HC165; SOIC-16_3.9x9.9mm_P1.27mm
K2: G5V-2_Split; Relay_DPDT_Omron_G5V-2
N20: NE5534 / SE5534; SOIC-8_3.9x4.9mm_P1.27mm
P20, P21: TestPoint; PinHeader_1x01_P1.00mm_Vertical
R200, R201, R202: 10K; R_1206_3216Metric_Pad1.30x1.75mm_HandSolder
R203, R204, R205: 10; R_1206_3216Metric_Pad1.30x1.75mm_HandSolder
R206, R207, R208, R209, R210, R211, R212: 1K; R_1206_3216Metric_Pad1.30x1.75mm_HandSolder
R215: 47R5; R_1206_3216Metric_Pad1.30x1.75mm_HandSolder
V20: BAS32; D_SOD-523
V21: BC850B; SOT-23
X2: Conn_01x03_Pin_Bridge; PinHeader_1x03_P2.54mm_Vertical

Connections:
+2V5: C206.1, P20.1, R200.2, R201.1; also elsewhere on the board
+5V: C200.1, C208.1, C209.1, C210.1, D20.14 (VCC), D21.16 (V_{DD}), D23.16 (VCC), K2.1, R200.1, R205.1, R206.1, R210.1, V20.1 (K); also elsewhere on the board
+5VA: C205.1, C207.1, D22.14 (VDD), R205.2, R208.2; also elsewhere on the board
+15V: C201.1, C211.1, N20.7 (V+), R203.1; also elsewhere on the board
+15VA: C203.1, R203.2; also elsewhere on the board
-15V: C202.2, C212.1, N20.4 (V-), R204.1; also elsewhere on the board
-15VA: C204.2, R204.2; also elsewhere on the board
/CLK: D20.8, D21.3 (CP), D22.8 (STB2), D23.2 (CP); also elsewhere on the board
/COS: X2.1; also elsewhere on the board
/ENABLE: D21.15 (OE); also elsewhere on the board
/IN_CLK: D20.10; also elsewhere on the board
/Integrator 1 & Loop Inverter/SD2: D22.7 (SRI); also elsewhere on the board
/LOW_DIST: K2.13, P21.1; also elsewhere on the board
/Level Control (ALC)/FILT: D21.7 (QP3); also elsewhere on the board
/Level Control (ALC)/FREQ_ENA: D21.11 (QP7); also elsewhere on the board
/Level Control (ALC)/LOFILT: D21.6 (QP2); also elsewhere on the board
/SD1: D21.10 (QS2); also elsewhere on the board
/SDI: D23.9 (Q7); also elsewhere on the board
/SDO: D21.2 (D); also elsewhere on the board
/WR: D20.3, D21.1 (STR); also elsewhere on the board
//IN_RD: D20.13; also elsewhere on the board
//IN_WR: D20.4; also elsewhere on the board
/~RD: D20.11, D23.1 (~PL); also elsewhere on the board
/~WR: D20.2, D20.6, D22.9 (~LD2); also elsewhere on the board
GNDD: C200.2, C201.2, C202.1, C203.2, C204.1, C205.2, C206.2, C207.2, C208.2, C209.2, C210.2, C211.2, C212.2, D20.7 (GND), D21.8 (V_{SS}), D22.2 (IOUT2), D22.3 (AGND), D22.12 (DGND), D23.8 (GND), K2.8, N20.3 (+), R201.2, R207.1, R209.1, R211.1, R212.1, V21.2 (E), X2.3; also elsewhere on the board
unnamed: D20.1, R206.2
unnamed: D20.5, D20.9, D20.12, R207.2
unnamed: D21.4 (QP0), R202.1
unnamed: C215.1, D22.1 (IOUT1), N20.2 (-)
unnamed: C215.2, D22.16 (RFB)
unnamed: D22.6 (SRO), D23.10 (DS)
unnamed: D22.4 (STB1), D22.5 (~LD1), D22.11 (STB4), R209.2
unnamed: D22.15 (VREF), K2.4
unnamed: D22.10 (~STB3), D22.13 (~CLR), R208.1
unnamed: D23.3 (D4), D23.5 (D6), D23.11 (D0), D23.14 (D3), R210.2
unnamed: D23.4 (D5), D23.6 (D7), D23.12 (D1), D23.13 (D2), R212.2
unnamed: D23.15 (~CE), R211.2
unnamed: K2.9, N20.6
unnamed: K2.11, R215.2
unnamed: C216.1, N20.5 (COMP)
unnamed: C216.2, N20.8 (C/B)
unnamed: K2.16, V20.2 (A), V21.3 (C)
unnamed: R202.2, V21.1 (B)
unnamed: K2.6, R215.1, X2.2

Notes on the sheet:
Renamed, because /WR and /WR are obviously buffered here!
IMD ATTEN
BOARD ID
DATA LINK

Board: 4 copper layers, 302 parts (228 on the bottom side), 200 nets, no tracks yet.

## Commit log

2025-11-23 Draft kicad project added
    [Sheet2.kicad_sch, Sheet3.kicad_sch, Sheet4.kicad_sch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]
2025-11-23 Connections page added
    [Sheet6.kicad_sch, UPL_B1.kicad_sch]
2025-11-24 added connections and library
    [Sheet2.kicad_sch, Sheet3.kicad_sch, Sheet4.kicad_sch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]
2025-11-25 Integrator 2 schematic added
    [Sheet4.kicad_sch]
2025-12-07 Added Integrator 1 and Level control
    [Sheet2.kicad_sch, Sheet3.kicad_sch, Sheet4.kicad_sch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]
2025-12-08 Add device datasheets, begin migration to hierarchical labels
    [Sheet3.kicad_sch, Sheet4.kicad_sch, Sheet5.kicad_sch]
2025-12-08 Begin drawing IMD section
    [Sheet2.kicad_sch]
2025-12-08 update on Output IMD
    [Sheet2.kicad_sch, Sheet5.kicad_sch]
2025-12-08 IMD Atten added
    [Sheet2.kicad_sch]
2025-12-08 updated to hierarchical labels
    [Sheet6.kicad_sch]
2025-12-08 Cleanup component names
    [Sheet2.kicad_sch, Sheet3.kicad_sch, Sheet4.kicad_sch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]
2025-12-08 Added Todo on Root page
    [UPL-B1.kicad_sch]
2025-12-09 Add drawing of topside mechanical.
    To be used in board outline and drill patterns
    [PlacementTopside.dxf]
2025-12-09 Begin PCB outline and add fencing drawing
    [UPL-B1.kicad_pcb]
2025-12-09 Minor fixups for layout.
    Reannotate, deduplicate N53B. Add some hierachical pins. First
    preparations for layout
    [Sheet2.kicad_sch, Sheet3.kicad_sch, Sheet5.kicad_sch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]
2025-12-09 Begin redrawing overview page.
    Having a huge bitmap in the background makes KiCad lag significantly, so
    try to get rid of it.
    [UPL-B1.kicad_sch]
2025-12-09 Redraw block diagram as vector art. Add more links in hierarchical overview.
    Remove original picture
    [Sheet4.kicad_sch, UPL-B1.kicad_sch]
2025-12-09 Clean up overview some more
    [UPL-B1.kicad_sch]
2025-12-09 updated DXF files for PCB
    [Cut-Outs.dxf, PCB_Main.dxf, UPL-B1.kicad_pcb]
2025-12-10 Begin making original BOM machine readable
    [BOM.ods]
2025-12-10 Continue BOM
    [BOM.ods]
2025-12-10 More BOM work
    [BOM.ods]
2025-12-10 Even more BOM work
    [BOM.ods]
2025-12-10 Updated symbols for ADC and Shiftregister
    [Sheet2.kicad_sch, Sheet3.kicad_sch, Sheet4.kicad_sch]
2025-12-11 Group functional blocks in ALC. Begin documenting digital chain.
    Fixed D21 designator, placed a few NC-Crosses on unused pins for good
    practice.
    [Sheet2.kicad_sch, Sheet4.kicad_sch, Sheet5.kicad_sch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]
2025-12-11 updated root schematic, added connections and removed connectorsheet
    [Sheet6.kicad_sch, UPL-B1.kicad_sch]
2025-12-11 Rework digital signal chain
    [Sheet2.kicad_sch, Sheet3.kicad_sch, UPL-B1.kicad_sch]
2025-12-11 More BOM work..
    [BOM.ods]
2025-12-11 added majority of footprints
    [Sheet2.kicad_sch, Sheet3.kicad_sch, Sheet4.kicad_sch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]
2025-12-12 First round of autoplacement.
    [UPL-B1.kicad_pcb, kicad-parts-placer-input.csv]
2025-12-12 Some BOM work.
    [BOM.ods]
2025-12-12 Rough component outline on PCB
    [Sheet2.kicad_sch, Sheet3.kicad_sch, Sheet4.kicad_sch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]
2025-12-14 Bracket added
    [B1 Bracket.step]
2025-12-16 ERC fixes.
    - Power flags added for power nets "hanging" off resistors.
    - Add missing NC-markers for intentionally unconnected parts
    - Fix -15V bridge between circuits on S4/S3
    - Add +5 to /CLR of DAC
    - Use non-hierachical labels on main sheet.
    [Sheet2.kicad_sch, Sheet3.kicad_sch, Sheet4.kicad_sch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]
2025-12-16 Use +/-15VA for some opamps and +5VA for the DACs.
    Note: Did they really use +/-15VA (denoted with asterisk in R&S
    schematics) on N34 but not on N20?
    [Sheet2.kicad_sch, Sheet3.kicad_sch]
2025-12-16 Minor readability changes
    [Sheet4.kicad_sch, Sheet5.kicad_sch, UPL-B1.kicad_sch]
2025-12-21 Updated PCB layout to include copper zones
    [UPL-B1.kicad_pcb]
2025-12-21 update on PCB board
    [UPL-B1.kicad_pcb]
2025-12-21 rough part outline
    [UPL-B1.kicad_pcb]
2025-12-26 added dxf files for Kicad and some documentation
    [Holes.dxf, PCB Outline.dxf, Shielding Outline Bottom.dxf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]
2025-12-29 renamed sheets and updated main connector
    [Integrator 1 & Loop Inverter.kicad_sch, Integrator 2.kicad_sch, Level Control (ALC).kicad_sch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]
2025-12-30 updated 3D-file for connector
    [UPL-B1.kicad_pcb]
2026-06-11 Annotate with reverse engineering clues
    [Integrator 1 & Loop Inverter.kicad_sch, Integrator 2.kicad_sch, Level Control (ALC).kicad_sch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]
